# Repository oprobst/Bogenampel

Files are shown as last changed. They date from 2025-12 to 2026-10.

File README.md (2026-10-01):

# Bogenampel

Eine funkgesteuerte Timer-Anzeige für Bogenschießplätze — zwei Geräte, zwei Taster,
kein Pairing, kein Netzwerk.

<!-- TODO: Durch ein Foto der fertig montierten Anzeigetafel im Betrieb ersetzen
     (leuchtende 7-Segment-Anzeige). Bis dahin steht hier die geöffnete
     Bedieneinheit, weil sie das Projekt am besten zeigt. -->
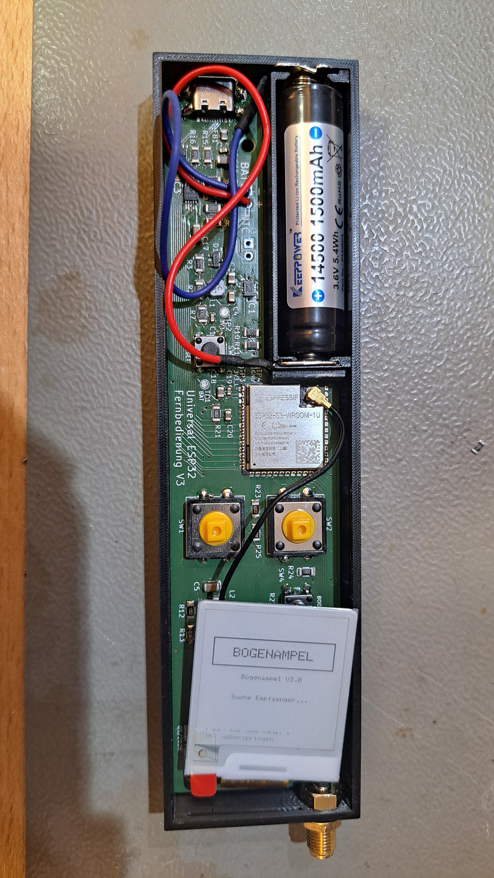
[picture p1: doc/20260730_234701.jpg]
Bedieneinheit geöffnet: ESP32-S3, 14500-Akku und e-Paper mit dem Startbildschirm


---

**Inhalt** — [1. Das Projekt](#1-das-projekt) · [2. Entwicklung](#2-entwicklung)

---

# 1. Das Projekt

## Worum es geht

Auf dem Schießplatz gibt eine Ampel den Takt vor: Rot heißt warten, Grün heißt
schießen, die Restzeit läuft sichtbar herunter. Die Bogenampel macht genau das —
aber ohne Kabel zwischen Schießlinie und Zielbereich, und mit so wenig Bedienung
wie möglich.

An der Bedieneinheit wird einmal der Modus vorgewählt (120 oder 240 Sekunden,
1-2 oder 3-4 Schützen), danach steuern **zwei Taster** den kompletten
Turnierablauf. Die Einstellung überlebt das Ausschalten.

Die Anlage besteht aus zwei Geräten:

- **Bedieneinheit (Sender)** — liegt an der Schießlinie. Akkubetrieben, e-Paper-Display,
  zwei große Taster.
- **Anzeigeeinheit (Empfänger)** — steht am Ziel. Große dreistellige 7-Segment-Anzeige
  aus LED-Streifen, in Ampelfarben, dazu zwei Gruppenbalken.

Dazwischen läuft ESP-NOW auf Kanal 1 — kein WLAN, kein Accesspoint, kein Pairing.
Der Sender sucht den Empfänger beim Einschalten selbst und merkt sich dessen
MAC-Adresse zur Laufzeit.

**Das wichtigste Sicherheitsmerkmal ist ein Stück Nicht-Verhalten**: Der Empfänger
zählt eine gestartete Passe **autonom** zu Ende. Fällt der Funk aus oder geht der
Sender aus, läuft der Timer trotzdem korrekt ab und schaltet danach auf Rot. Die
Anzeige bleibt nie in Grün stehen, nur weil die Verbindung weg ist.

## Die Bedieneinheit

ESP32-S3-WROOM-1U mit externer Antenne am U.FL-Anschluss, 1,54″-e-Paper
(200 × 200, SSD1681), eine 14500-LiIon-Zelle mit MCP73837-Lader und ein
Soft-Power-Latch um einen TPS62742: Einschalten per Taster, Ausschalten übernimmt
die Firmware selbst, sobald sie fertig aufgeräumt hat.
Das e-Paper behält sein Bild ohne Strom — der Abschaltbildschirm bleibt deshalb nach
dem Ausschalten lesbar stehen.

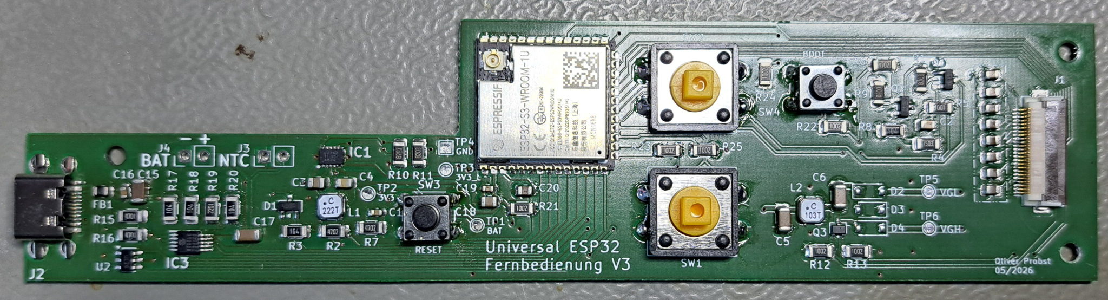
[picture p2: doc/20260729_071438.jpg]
Bestückte Sender-Platine mit ESP32-S3-WROOM-1U und den beiden Tastern


Die Platine trägt den Namen „Universal ESP32 Fernbedienung V3" — sie ist bewusst
etwas allgemeiner gehalten als nötig. Links sitzen Ladeteil und USB-C, in der Mitte
das Funkmodul mit den beiden Tastern, rechts die Ansteuerung für das e-Paper.

## Die Anzeigeeinheit

Ein XIAO ESP32C3 treibt einen WS2811-Streifen mit **66 Pixeln**: 12 für den
Gruppenbalken C/D, 12 für A/B und 3 × 14 für die dreistellige Ziffernanzeige
(2 Pixel je Segment). Versorgt wird alles aus einem USB-C-Netzteil, das über einen
CH224K-Trigger auf **12 V** verhandelt wird.

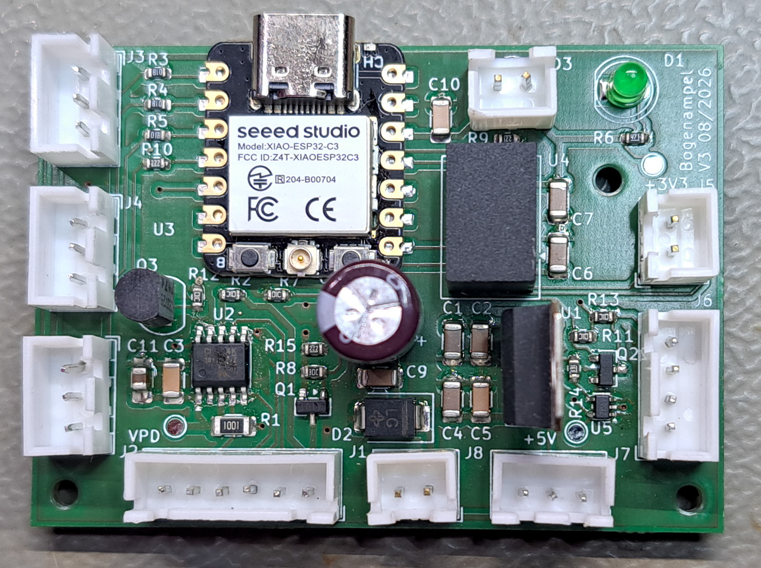
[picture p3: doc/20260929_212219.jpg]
Bestückte Empfänger-Platine mit XIAO ESP32C3 und CH224K


Drei Potis regeln direkt am Gerät, ohne Umweg über den Funk: **Lautstärke**,
**Helligkeit** und **Lüfterdrehzahl**. Dazu ein Piezo-Transducer für die
Signaltöne und ein temperaturunkritischer, aber hörbarer Lüfter — deshalb regelbar.

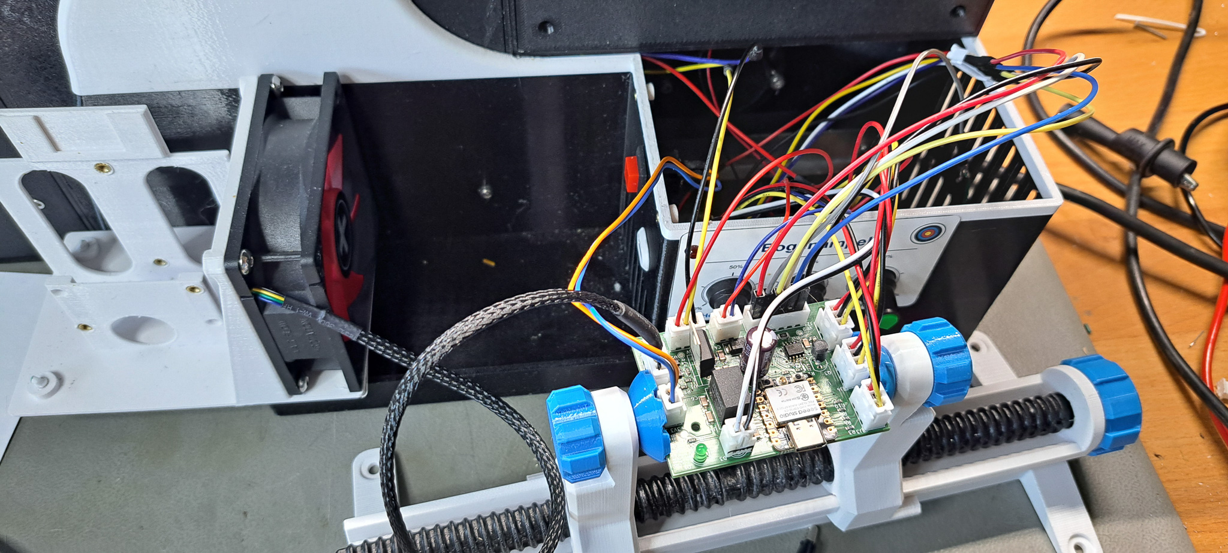
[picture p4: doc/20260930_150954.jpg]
Empfänger-Elektronik im 3D-gedruckten Gehäuse mit Lüfter und Potis


## Bedienung

Der Sender hat zwei Taster. Welcher Taster einschaltet, legt der Power-Latch in der
Hardware fest — das ist die **CONFIG**-Taste.

| Taste | kurz | 3× schnell klicken | 3 s halten |
|---|---|---|---|
| **CONFIG** | Weiter / Wert ändern | — | Ausschalten |
| **OK** | Bestätigen / Passe beenden | Alarm | Ausschalten |

Einschalten: CONFIG drücken. Ausschalten: eine der beiden Tasten 3 Sekunden halten.
Die Konfiguration (Schießzeit, Schützenzahl) bleibt im NVS erhalten und steht beim
nächsten Einschalten wieder zur Verfügung.

**Alarm**: die **OK**-Taste dreimal schnell hintereinander drücken (höchstens 0,4 s
zwischen den Klicks). Das geht im Schießbetrieb und beim Pfeileholen — also überall
dort, wo Leute an der Schießlinie stehen können. Im Konfigurationsmenü und im
Startbildschirm bleibt die Folge bewusst wirkungslos. CONFIG löst grundsätzlich
keinen Alarm aus: Diese Taste blättert durch Menüs und zählt Werte hoch, dort ist
zügiges Tippen normale Bedienung. Quittiert wird ein Alarm mit einem kurzen OK.

Ausschalten und Alarm liegen absichtlich auf **verschiedenen** Bewegungen: Halten
schaltet immer aus, egal in welchem Zustand das Gerät gerade ist. Früher hing die
Bedeutung des Haltens am Betriebszustand — wer im Schießbetrieb ausschalten wollte,
löste stattdessen einen Alarm aus.

**Automatische Abschaltung**: Wird im Konfigurationsmenü oder in „Pfeile holen" 60 Minuten
lang keine Taste gedrückt, schaltet sich der Sender selbst ab und zeigt dabei
„Automatische Abschaltung". Im Schießbetrieb und bei stehendem Alarm greift das
bewusst **nicht** — dort läuft eine Passe bzw. ein Sicherheitszustand. Gedacht ist es
gegen das im Koffer vergessene Gerät; dagegen hilft keine Stromsparmaßnahme, nur
Ausschalten.

## Ablauf einer Passe

| Phase | Anzeige | Dauer |
|---|---|---|
| **Stopp** | Rot, `000` | bis zum Start |
| **Vorbereitung** | Rot, Countdown | 10 s |
| **Schießzeit** | Grün, Countdown | 120 s oder 240 s |
| **letzte 30 s** | Orange, Countdown | 30 s |
| **Ende** | Rot, `000` | — |

Der Piezo quittiert die Phasenwechsel mit kurzen Tonfolgen (3250 Hz), das Passenende
mit drei Tönen. Ein ausgelöster Alarm blinkt und piept achtmal.

### Gruppen und halbe Passe

Bei 3-4 Schützen wird zwischen den Gruppen A/B und C/D umgeschaltet; die Anzeige folgt
einem 4er-Zyklus. Zusätzlich lässt sich eine halbe Passe starten, wenn nur noch die
zweite Gruppe schießt. Den Wechsel von der ersten auf die zweite Hälfte vollzieht der
Empfänger selbst, sobald sein Countdown abgelaufen ist — auch das gehört zur
Autonomie-Regel oben.

## Schaltpläne und Platinen

Autoritativ sind die KiCad-Projekte [`Schaltung-Sender/`](Schaltung-Sender/) und
[`Schaltung-Empfaenger/`](Schaltung-Empfaenger/). Die folgenden Exporte sind für alle
gedacht, die ohne KiCad hineinsehen wollen.

**Bedieneinheit (Sender)**

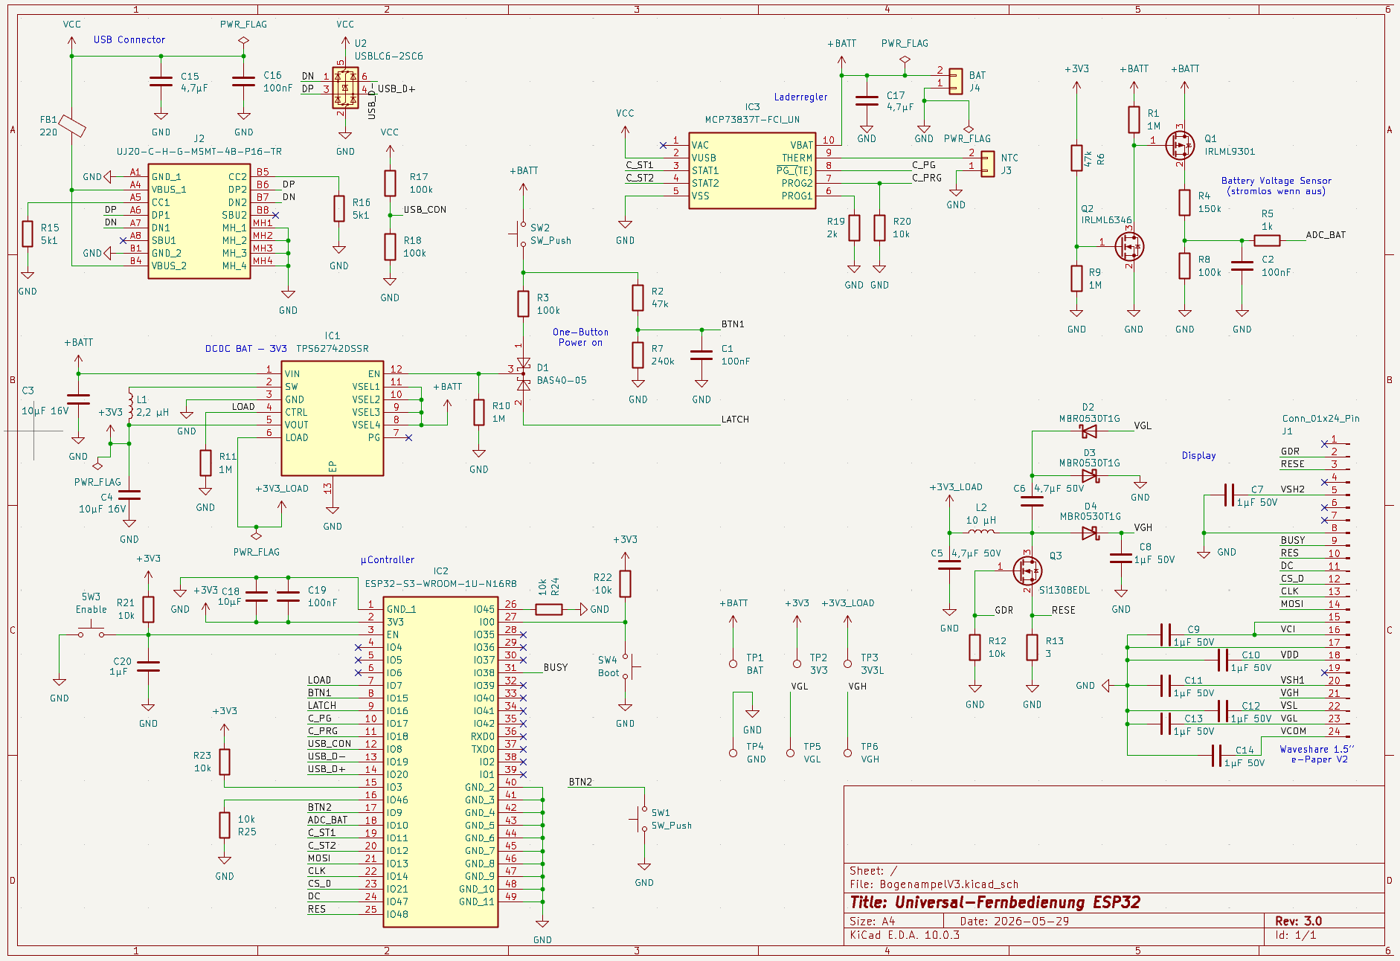
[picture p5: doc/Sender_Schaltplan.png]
Schaltplan Sender


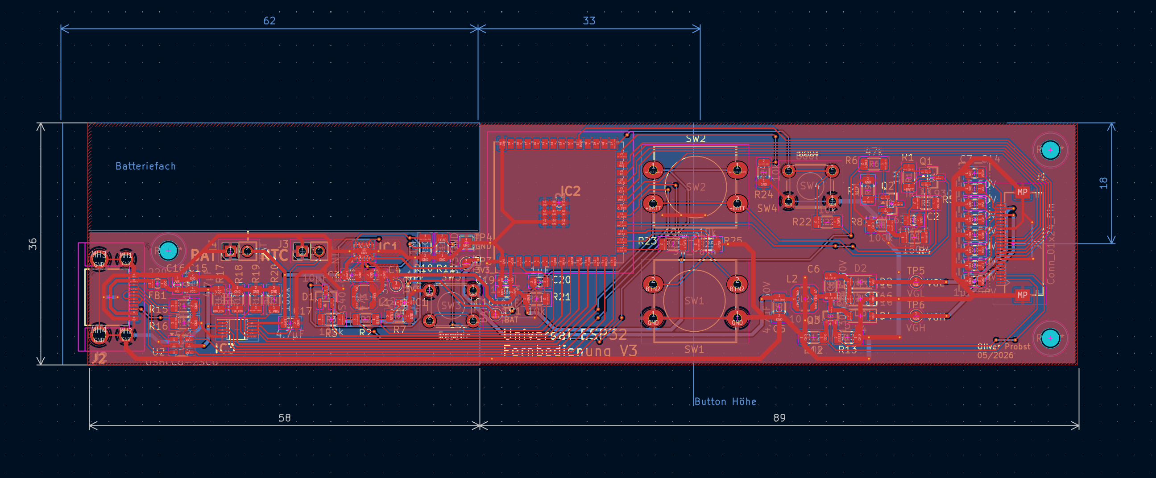
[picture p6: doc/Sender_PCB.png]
Platinenlayout Sender


**Anzeigeeinheit (Empfänger)**

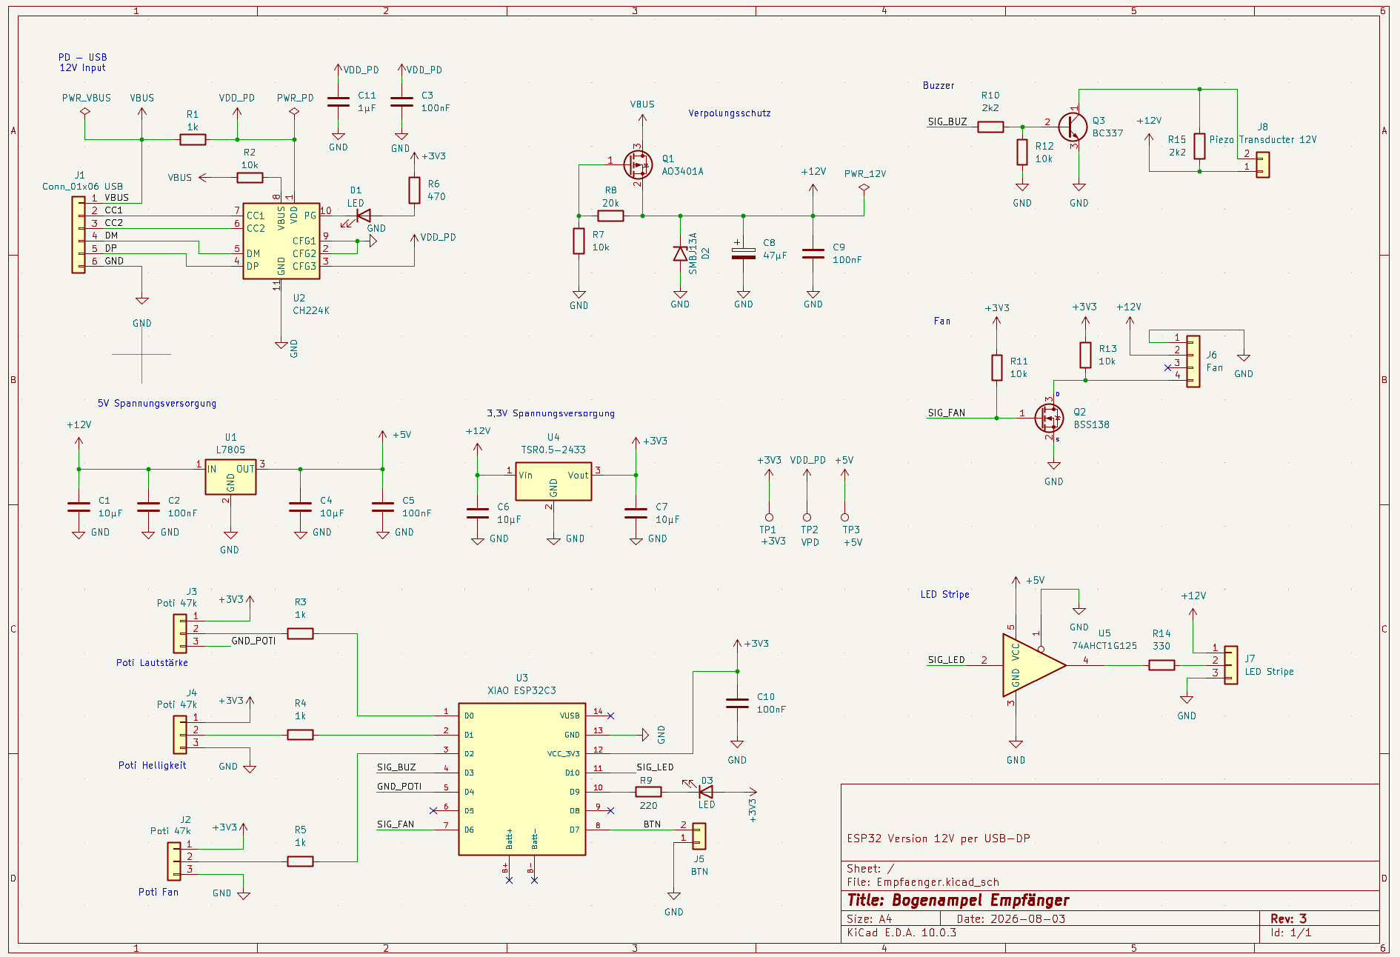
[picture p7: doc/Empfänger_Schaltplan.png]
Schaltplan Empfänger


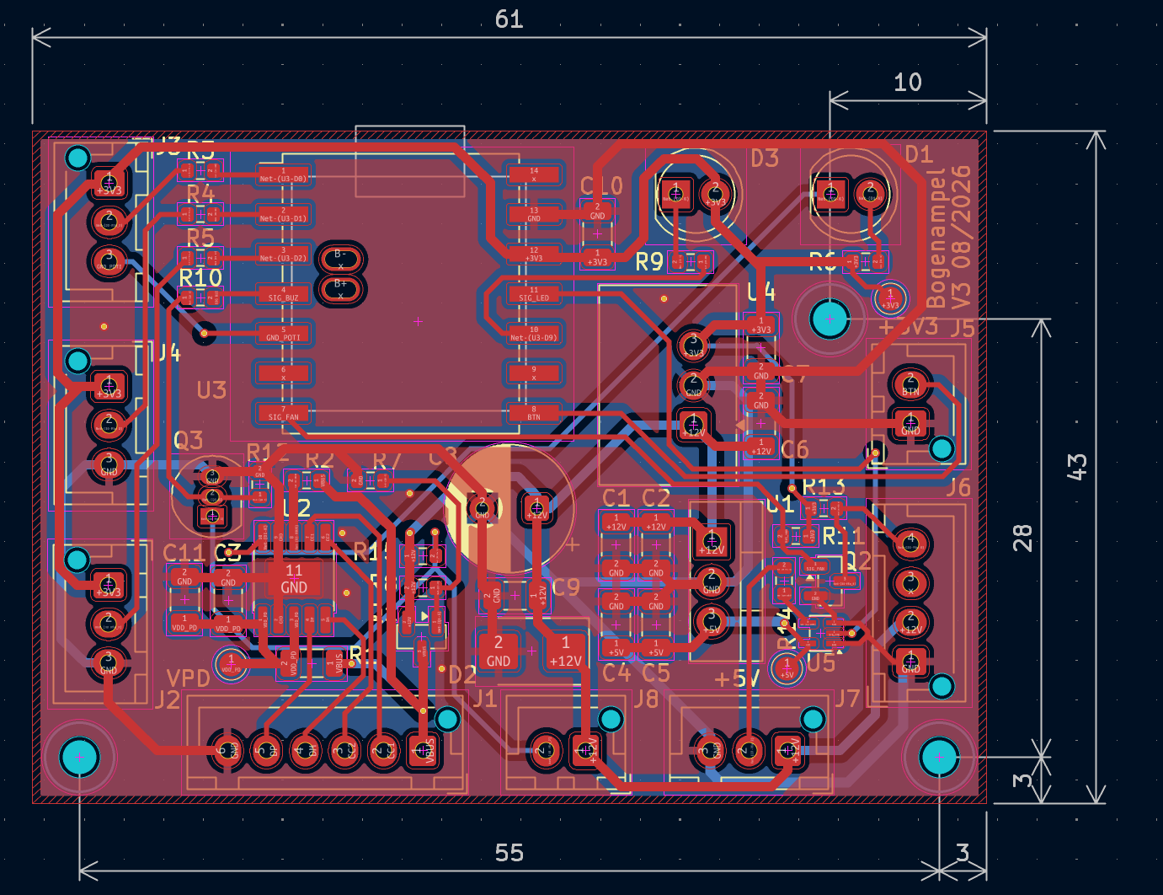
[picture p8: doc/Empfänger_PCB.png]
Platinenlayout Empfänger


---

# 2. Entwicklung

## Hardware-Überblick

| | Sender (Bedieneinheit) | Empfänger (Anzeigeeinheit) |
|---|---|---|
| **Controller** | ESP32-S3-WROOM-1U-N16R8 (16 MB Flash, 8 MB PSRAM) | Seeed XIAO ESP32C3 |
| **Anzeige** | 1.54″ e-Paper, 200×200 (SSD1681) | LED-Strip WS2811 12 V, 66 Pixel |
| **Funk** | ESP-NOW, Kanal 1 (im Chip integriert) | ESP-NOW, Kanal 1 |
| **Versorgung** | LiIon 14500 + MCP73837-Lader, USB-C | USB-C PD 12 V über CH224K (≥ 2 A) |
| **Bedienelemente** | 2 Taster (CONFIG, OK) | Debug-Taster, 3 Potis |
| **Sonstiges** | Soft-Power-Latch (TPS62742) | Piezo 12 V, geregelter Lüfter, Pegelwandler 74AHCT1G125 |
| **Firmware** | [`Sender/`](Sender/) | [`Empfaenger/`](Empfaenger/) |
| **Schaltplan** | [`Schaltung-Sender/`](Schaltung-Sender/) | [`Schaltung-Empfaenger/`](Schaltung-Empfaenger/) |

Die verbindliche Pin-Belegung steht in
[`specs/004-v3-esp32-port/contracts/hardware-pins.md`](specs/004-v3-esp32-port/contracts/hardware-pins.md)
und wird aus den KiCad-Netzlisten abgeleitet. Bei Abweichungen gilt der Schaltplan —
Änderungen gehören zuerst dorthin, dann in den Code.

Die Empfänger-Platine erzeugt aus den 12 V zwei weitere Schienen: ein TSR0.5-2433
versorgt den XIAO mit 3,3 V, ein L7805 den Pegelwandler mit 5 V. Der LED-Strip hängt
direkt am 12-V-Netz — er kann die Logikversorgung also nicht mehr in die Knie zwingen.

## Funk

ESP-NOW auf Kanal 1, ohne externes Funkmodul und ohne Pairing: Der Sender sucht den
Empfänger beim Start per Broadcast und merkt sich dessen MAC-Adresse zur Laufzeit.

Jeder Frame ist 6 Byte groß und trägt Magic-Bytes, eine Prüfsumme und eine
Sequenznummer; der Empfänger verwirft doppelte und fehlerhafte Pakete. Übertragen
werden 11 Kommandos (Start 120/240, Stopp, Init, Alarm, Ping, Gruppenwahl, halbe Passe).
Beim Start misst der Sender die Verbindungsqualität mit 10 Pings und zeigt das Ergebnis
im Splash-Screen.

> **Ein Radio, ein Kanal.** Der ESP32 kann nicht gleichzeitig ESP-NOW auf Kanal 1 und
> WLAN auf einem anderen Kanal betreiben. Deshalb läuft im Normalbetrieb **kein** WiFi —
> weder ein Accesspoint noch eine Netzwerkverbindung. Für Updates gibt es den
> Wartungsmodus (siehe unten).

Die Protokollregeln stehen in
[`espnow-protocol.md`](specs/004-v3-esp32-port/contracts/espnow-protocol.md). Zwei
davon sind beim Ändern leicht zu übersehen:

- **Regel 3**: Ein `CMD_START` wird vom Empfänger ignoriert, solange seine
  Vorbereitungsphase bereits läuft. Beim regulären Gruppenwechsel ist das Kommando
  nur ein Sync-Signal — der Empfänger hat da längst selbst umgeschaltet.
- **FR-004a**: Beim Ablauf der Zeit sendet der Sender **nie** `CMD_STOP`. Das
  Passenende gehört dem Empfänger allein.

## Bauen und Flashen

PlatformIO ist der einzige unterstützte Build-Pfad. Die `platformio.ini` liegt **zentral
im Repo-Root**, nicht in den Firmware-Ordnern — das Repo-Root ist das Arbeitsverzeichnis.
Bibliotheken kommen über `lib_deps`, es muss nichts manuell installiert werden; die
Versionen sind **gepinnt** (FastLED 3.10.3, GxEPD2 1.6.9, Adafruit GFX 1.12.6).

```bash
pio run -e sender                 # bauen
pio run -e empfaenger

pio run -t upload -e sender       # per USB flashen
pio device monitor -e sender      # 115200 Baud

pio run -e sender-release         # Feld-Build: ohne Debug-Ausgaben und CDC-Task
```

Drei Stolpersteine, die alle wie Hardwaredefekte aussehen:

**Beim Sender muss CONFIG während des gesamten Uploads gedrückt bleiben.** Der Reset von
esptool lässt sonst den Power-Latch fallen; das Gerät schaltet sich mitten im Flashen ab
und der USB-Port verschwindet. Zu beachten: `pio run -t upload` startet esptool erst nach
gut einer Minute Build- und Dependency-Scan — so lange muss der Taster gehalten werden.
Praktischer ist, das Gerät **mit gehaltenem CONFIG einzuschalten** (dann greift der
Boot-Lockout und das Halten löst keine Power-Off-Geste aus) und esptool direkt mit den
vier Images aufzurufen.

**Die Upload-Baudrate darf nicht hochgesetzt werden** (`upload_speed = 115200` in der
`platformio.ini`). Der Sender flasht über die native USB-Serial/JTAG-Peripherie, wo die
Baudrate bedeutungslos ist — esptool wechselt beim Board-Default 460800 trotzdem, der Port
re-enumeriert dabei und der Upload stirbt mitten im Stub-Flasher mit
`PermissionError(13) ... Cannot configure port`.

**Unter Windows vor jedem Upload `$env:PYTHONIOENCODING="utf-8"` setzen.** Sonst bricht
der Vorgang mit `UnicodeEncodeError` und `[upload] Error 4294967295` ab — esptool schreibt
Unicode-Fortschrittsbalken, die eine cp1252-Konsole nicht kodieren kann. Auf den Chip
wurde zu diesem Zeitpunkt noch nichts geschrieben.

### Testlauf mit verkürzten Zeiten

Für Tests gibt es eigene Environments: Vorbereitung 5 s statt 10, Schießzeit 6 s statt
120 bzw. 12 s statt 240, Orange-Phase 2 s statt 30. Eine komplette Passe läuft damit in
unter einer Minute durch.

```bash
pio run -t upload -e empfaenger-debug-ota
pio run -t upload -e sender-debug-ota
```

Eingeschaltet wird das über `-DDEBUG_SHORT_TIMES=1` aus der `platformio.ini` — **nicht**
im Quellcode, wo ein `#ifndef`-Guard mit Default 0 steht. So kann ein Build mit
6-Sekunden-Passe nicht versehentlich im Feld landen.

> **Immer beide Geräte umstellen.** Der Empfänger zählt die Passe autonom und bekommt
> per Funk nur `CMD_START_120/240`, nie die Dauer selbst. Die Zeittabelle
> (`Timing::shootingSeconds()`) steht wortgleich in beiden `Config.h` und muss es
> bleiben — sonst endet die Passe auf zwei verschiedenen Sekunden.

### OTA-Wartungsmodus

Beide Geräte lassen sich drahtlos aktualisieren, aber nur in einem eigenen Betriebsmodus —
im Normalbetrieb ist WiFi aus (siehe Kasten oben).

- **Sender**: beide Taster gleichzeitig gedrückt halten und einschalten
- **Empfänger**: mit gehaltenem Debug-Taster (D7) einschalten

Der Sender zeigt daraufhin einen Wartungs-Screen mit WLAN-Status und **seiner eigenen
IP-Adresse**; beim Empfänger signalisiert die Status-LED durch langsames Blinken, dass er
bereit ist. Die IP wird als `upload_port` in der `platformio.ini` eingetragen (eine feste
DHCP-Reservierung ist empfehlenswert, mDNS-Namen lösen über Subnetzgrenzen nicht
zuverlässig auf).

```bash
pio run -t upload -e sender-ota            # Sender, Debug-Build (serieller Monitor bleibt)
pio run -t upload -e sender-release-ota    # Sender, Feld-Build (ohne Debug-Ausgaben/CDC)
pio run -t upload -e empfaenger-ota
```

`sender-release-ota` ist der Auslieferungsweg: gleicher Wartungsmodus, aber das
Image aus `sender-release`. Danach meldet sich kein serieller Port mehr — der
Rückweg auf den Debug-Build geht weiterhin per OTA über `sender-ota`, solange der
Wartungsmodus erreichbar bleibt.

Voraussetzung ist eine `wifi_credentials.h` im Repo-Root — Vorlage:
[`wifi_credentials.h.example`](wifi_credentials.h.example). Die Datei ist bewusst nicht
eingecheckt. Fehlt sie, meldet der Wartungsmodus das auf dem Display und wartet; einen
Accesspoint-Fallback gibt es absichtlich nicht, weil ein zweites Netz auf fremdem Kanal
ESP-NOW stilllegen würde.

Zur Fehlersuche: **ArduinoOTA lauscht auf UDP 3232, nicht TCP.** Ein TCP-Portscan meldet den
Port folgerichtig als geschlossen, auch wenn der Wartungsmodus einwandfrei läuft — daraus
lässt sich also nichts über die Erreichbarkeit ableiten. espota schickt eine UDP-Einladung,
woraufhin das Gerät eine TCP-Rückverbindung zum Host aufbaut.

Der Zugang ist nicht durch ein Passwort geschützt, sondern dadurch, dass der Modus nur mit
physisch gedrückten Tastern erreichbar ist. Grund: Das ArduinoOTA-Passwort (PBKDF2) ist mit
der `espota.py` von PlatformIO nicht kompatibel, die Authentifizierung scheitert stumm.

## Anzeige-Eigenheiten

Zwei Stellen, an denen das naheliegende Verhalten bewusst nicht implementiert ist:

**Das e-Paper blitzt nur beim Start und beim Beenden.** Ein Voll-Refresh (~2,6 s,
schwarz/weiß-Invertierung) läuft nur im Splash und auf dem Abschaltbildschirm. Alles
dazwischen — Menü, Countdown, Pfeile holen, Alarm — nutzt die Partial-Waveform und
bleibt ruhig. Restschatten werden dafür in Kauf genommen und erst beim nächsten
Einschalten weggeblitzt. Die Entwicklungsgeschichte dieser Stelle steht als Kommentar
in `Sender/EpaperDisplay.cpp`; sie ist zweimal in die andere Richtung gelaufen.

**Die Poti-Drehrichtung sitzt an genau einer Stelle**: `Poti::ASCENDING` und
`Poti::level()` in `Empfaenger/Config.h`. Alle Kennlinien rechnen mit der
Reglerstellung, nie mit dem ADC-Rohwert. Wer eine Drehrichtung umdreht, ändert das
Flag — nicht die einzelnen Kennlinien.

## Stromverbrauch des Senders

Gemessen am laufenden Gerät: **0,39 W → 0,20 W**, also etwa doppelte Akkulaufzeit.
Zwei Maßnahmen, beide in der Firmware:

| Maßnahme | Ersparnis |
|---|---|
| CPU-Takt 240 → 80 MHz (`System::CPU_FREQ_NORMAL_MHZ`) | ~10 mA |
| ESP-NOW-Empfangsfenster duty-cycled statt dauerhaft offen | ~38 mA |

Der Löwenanteil war das Funkmodul: ESP-NOW hält den Empfänger per Default dauerhaft an.
Der Sender ist nach der Discovery aber ein reiner Sender — das ACK auf eigene Frames
kommt im Sendefenster zurück, also darf das Empfangsfenster zu bleiben. Während der
Discovery wird es nur um den HELLO-Broadcast herum geöffnet. Details und Voraussetzungen
stehen in [`espnow-protocol.md`](specs/004-v3-esp32-port/contracts/espnow-protocol.md),
Regel 7.

Das **e-Paper ist für den Verbrauch praktisch irrelevant** (unter 2 %) — der
Sekundencountdown im Schießbetrieb ist bewusst nicht angetastet. Nicht möglich ist das
Abschalten des PSRAM: `CONFIG_SPIRAM=1` steckt in allen vorkompilierten
arduino-esp32-Varianten und die Initialisierung hängt nicht an `-DBOARD_HAS_PSRAM`.
Weiter runter käme man nur mit abgeschaltetem Radio zwischen den Kommandos und
manuellem Light-Sleep — die automatische Variante scheidet aus, weil `CONFIG_PM_ENABLE`
in den vorkompilierten Libs fehlt.

## Projektstruktur

```text
platformio.ini          zentrale Build-Konfiguration (beide Geräte)
Sender/                 Firmware Bedieneinheit (ESP32-S3)
Empfaenger/             Firmware Anzeigeeinheit (XIAO ESP32C3)
Schaltung-Sender/       KiCad-Projekt Sender
Schaltung-Empfaenger/   KiCad-Projekt Empfänger
doc/                    Fotos, Schaltplan- und Layout-Exporte
specs/                  Feature-Spezifikationen, Pin-Contract, Abnahme-Checkliste
```

Weiterführend: [`HARDWARE.md`](HARDWARE.md) für die Hardware-Spezifikation,
[`CLAUDE.md`](CLAUDE.md) für die Entwicklungs-Leitplanken und die Änderungshistorie,
[`specs/004-v3-esp32-port/quickstart.md`](specs/004-v3-esp32-port/quickstart.md) für die
vollständige Inbetriebnahme- und Abnahme-Checkliste.

## Bekannte offene Punkte

- **Funk mit geschlossenem Empfangsfenster noch nicht im Turnierablauf verifiziert**: Dass
  das Link-ACK bei `esp_now_set_wake_window(0)` zuverlässig zurückkommt, ist durch die
  Strommessung und den Treiber-Kontrakt gestützt, aber ein vollständiger Durchlauf
  (Start, Gruppenwechsel, Alarm, Stop, Empfänger im Betrieb ausschalten → Relink) steht
  aus. Falls Kommandos zicken: `Radio::PS_WINDOW_CLOSED_MS` in `Sender/Config.h` von 0 auf
  10 setzen — kostet ~10 mA, hält das Fenster aber zu 10 % offen.
- **Restschatten am e-Paper über eine lange Sitzung**: Seit der Voll-Refresh nur noch
  beim Start und beim Beenden läuft, sammelt sich Ghosting über das ganze Turnier an.
  Ob das im Betrieb stört, ist noch nicht beurteilt. Falls ja, wäre ein Voll-Refresh
  beim Verlassen des Schießbetriebs der nächste Kompromiss.
- **MOSFET-Typen im KiCad-Projekt uneinheitlich**: Im Empfänger-Schaltplan stehen die
  MOSFETs als **Q1 = AO3401A** und **Q2 = BSS138** — aber nur im *Value*-Feld. Die
  **MPN-Eigenschaft**, die Felder im **Layout** (`Empfaenger.kicad_pcb`) und der
  **BOM-Export** (`Empfaenger.csv`) nennen weiterhin IRLML9301 bzw. 2N7002. Wer nach
  der BOM oder der MPN bestellt, bekommt also die alten Typen. Zu klären ist zuerst,
  welche Teile physisch bestückt sind; danach in KiCad die MPN nachziehen,
  „Update PCB from Schematic" laufen lassen und die BOM neu exportieren.
  Die Firmware-Kommentare und die Doku folgen dem Value-Feld (AO3401A/BSS138).
- **Ladestrom**: Der Sender lädt mit 80–100 mA. Auf 500 mA umschalten geht **nicht per
  Firmware**, auch wenn die Leitung dafür vorbereitet aussieht: Der PROG2-Eingang des
  MCP73837 verlangt für „High" mindestens 0,8 × VDD = 4,0 V (VDD = VUSB = 5 V), ein
  ESP32-GPIO liefert nur 3,3 V — und landet damit im Shutdown-Fenster, der Lader schaltet
  ab. Schnellladen braucht eine Hardware-Änderung (R20 als Pull-up nach VUSB, ggf. mit
  MOSFET zum Umschalten). Details in
  [`hardware-pins.md`](specs/004-v3-esp32-port/contracts/hardware-pins.md), Befund 4.

## Historie

**Version 2** (bis 2026-08-01) basierte auf zwei Arduino Nanos mit nRF24L01+-Funkmodulen,
einem ST7789-TFT am Sender und einer EEPROM-Konfiguration. Timer-Ablauf, Ampelfarben,
Gruppenlogik und die 11 Funk-Kommandos wurden unverändert nach V3 übernommen.

Firmware, Bibliotheken und KiCad-Projekt von V2 wurden aus dem Arbeitsverzeichnis
entfernt und sind über die Git-Historie zugänglich (letzter Stand: Commit `e632bfb`).
Beachte dabei: Die Ordnernamen `Sender/` und `Empfaenger/` bezeichnen **vor** diesem
Zeitpunkt die V2-, danach die V3-Firmware.

```bash
git show e632bfb:Sender/Sender.ino      # V2-Quelltext ansehen
```

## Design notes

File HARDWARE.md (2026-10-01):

# Hardware-Spezifikation: Bogenampel

> **Aktuelle Generation: V3 (ESP32)** — siehe direkt unten.
> Die V2-Spezifikation (Arduino Nano) folgt weiter unten als eingefrorener
> Legacy-Stand.

## Hardware V3 (aktuell)

Autoritative Quelle ist der KiCad-Schaltplan in `Schaltung-Sender/` bzw. `Schaltung-Empfaenger/`
(Constitution V: „Schaltplan zuerst, dann Code"); die daraus extrahierte,
verbindliche Pin-Tabelle für beide Firmwares steht in
[`specs/004-v3-esp32-port/contracts/hardware-pins.md`](specs/004-v3-esp32-port/contracts/hardware-pins.md).

### Sender V3 („Universal-Fernbedienung")

- **ESP32-S3-WROOM-1U-N16R8** (16 MB Flash, 8 MB Octal-PSRAM → GPIO35-37 reserviert)
- **1.54″ e-Paper** Waveshare V2 (GDEH0154D67/SSD1681, 200×200) als rohes Panel an J1
  (24-pol FPC) mit diskretem Boost (Si1308EDL + MBR0530)
- **Power**: TPS62742 mit Latch (GPIO16 hält das Gerät an, LOW = Selbstabschaltung),
  LOAD-Rail (GPIO7) schaltet die Display-Versorgung
- **Akku**: einzelne LiIon-/LiPo-Zelle (verbaut: 14500, 1500 mAh) mit MCP73837-Lader
  (STAT1/STAT2/PG an GPIO11/12/17),
  Spannungsmessung über Teiler R4=150k/R8=100k an GPIO10 (ADC1, ×2,5)
- **Taster**: BTN1 = SW2/GPIO15, aktiv HIGH über Teiler R2=47k/R7=240k an +BATT;
  BTN2 = SW1/GPIO9 gegen GND (interner Pull-up).
  **Rollen** (seit 2026-08-01 an der Gehäusebeschriftung ausgerichtet):
  GPIO15 = **CONFIG** (Weiter/Ändern; hält beim Einschalten den Power-Latch — das ist
  Hardware und per Firmware nicht auf den anderen Taster verlegbar),
  GPIO9 = **OK** (Bestätigen, Dreifachklick = Alarm). Die Zuordnung Rolle → Pin steht
  ausschließlich in `ButtonManager::readRawState()`.
- **Funk**: ESP-NOW; der **-1U** hat keine Leiterplattenantenne, sondern einen
  **U.FL-Anschluss für eine externe Antenne** (verbaut: SMA-Pigtail)

| Funktion | GPIO | | Funktion | GPIO |
|---|---|---|---|---|
| LATCH (Power halten) | 16 | | e-Paper CS | 21 |
| LOAD (Display-Rail) | 7 | | e-Paper DC | 47 |
| BTN1 = CONFIG (Power-On, aktiv HIGH) | 15 | | e-Paper RES | 48 |
| BTN2 = OK (aktiv LOW) | 9 | | e-Paper BUSY | 38 |
| ADC_BAT (ADC1, ×2,5) | 10 | | SPI CLK | 14 |
| USB_CON (aktiv HIGH) | 8 | | SPI MOSI | 13 |
| Lader ST1 / ST2 / PG / PRG | 11 / 12 / 17 / 18 | | USB D-/D+ | 19/20 |

### Empfänger V3 (PD-12V-Platine, Rev. 2026-08-03)

- **Seeed XIAO ESP32C3** (4 MB Flash), Versorgung über den **3V3-Pin** (VUSB/Batt unbeschaltet)
- **Stromversorgung**: USB-C (J1) → **CH224K** (U2) verhandelt 12 V → Verpolungsschutz
  Q1 (**AO3401A**, P-Kanal) + TVS D2 (SMBJ13A) → +12V-Netz; daraus **TSR0.5-2433** (U4) → 3V3
  für den XIAO und **L7805** (U1) → 5 V nur für den Pegelwandler U5. Kein Step-up, keine
  Jumper mehr. Netzteil: 12 V / ≥ 2 A.
- **WS2811-Strip** 66 Pixel, direkt am 12V-Netz (2×12 Gruppen + 3×14 Ziffern-Pixel)
- **Pegelwandler U5 74AHCT1G125** (3,3 → 5 V, /OE fest an GND) in der Datenleitung,
  Ausgang über R14 330 Ω an J7 — behebt die früheren Farbkipper bei 3,3-V-Pegel
- **Piezo**: 12-V-Transducer über BC337 (Q3; R10 2k2 Basisvorwiderstand, R12 10k
  Basis-Pulldown, R15 2k2 nach +12 V als Entlade-Pfad), LEDC-PWM (3,25 kHz = Resonanz,
  Lautstärke = Duty 0-50 %)
- **Lüfter**: **BSS138** Low-Side (Q2, **invertiert**: Gate HIGH = PWM-Leitung LOW =
  langsam), LEDC-PWM 25 kHz, Drehzahl per Poti;
  Tacho bewusst unbeschaltet (R11 = Gate-Pull-up → Lüfter läuft beim Boot auf Minimaldrehzahl)
- **Potis** (3 × 47 k, je über 1 k am Schleifer): regulär zwischen GND und 3V3 verdrahtet,
  **Aufdrehen liefert den höheren ADC-Wert**. Die Firmware rechnet deshalb über
  `Poti::level()` mit der Reglerstellung statt mit dem Rohwert; die Drehrichtung steht
  als einziges Flag in `Poti::ASCENDING` (`Empfaenger/Config.h`) — nie einzeln in den
  Kennlinien invertieren.
- **ESP32-C3-Strapping-Fixes** (alle im Schaltplan umgesetzt):
  GPIO2 (Lautstärke-Poti) → Fußpunkt an D4/GPIO6 statt GND („POTI_GND");
  GPIO9 (Status-LED) → aktiv LOW (3V3 → LED → R9 → Pin); GPIO8 frei (kein Tacho)

| Funktion | XIAO-Pin | GPIO |
|---|---|---|
| Poti Lautstärke (J3, Fußpunkt an D4!) | D0 | 2 |
| Poti Helligkeit (J4) | D1 | 3 |
| Poti Lüfter-Drehzahl (J2) | D2 | 4 |
| Piezo (J8, über BC337) | D3 | 5 |
| POTI_GND (geschalteter Fußpunkt) | D4 | 6 |
| Lüfter-PWM (J6 Pin 4, über Q2 BSS138) | D6 | 21 |
| Debug-Taster (J5, aktiv LOW) | D7 | 20 |
| Status-LED (**aktiv LOW**) | D9 | 9 |
| WS2811 Data (J7, über U5) | D10 | 10 |
| frei / Reserve | D5, D8 | 7, 8 |

---

# Hardware-Spezifikation V2 (Legacy): Bogenampel Sender

## Übersicht

Der Sender ist die Bedieneinheit der Bogenampel und basiert auf einem Arduino Nano V3. Er steuert per Funk (NRF24L01) die Anzeigeeinheit und verfügt über ein TFT-Display zur Statusanzeige.

## Komponenten

### Mikrocontroller
- **Arduino Nano V3**
  - ATmega328P @ 16 MHz
  - 32 KB Flash (2 KB für Bootloader)
  - 2 KB SRAM
  - 1 KB EEPROM
  - Betriebsspannung: 5V
  - I/O-Pins: 3.3V/5V tolerant (über Level Shifter für Display)

### Display
- **2.4" TFT LCD ST7789**
  - Auflösung: 240 x 320 Pixel
  - Farbtiefe: 65K (16-bit RGB565)
  - Interface: SPI
  - Betriebsspannung: 3.3V (via Level Shifter)
  - Controller: ST7789

### Level Shifter
- **TXS0108EPW**
  - 8-Kanal bidirektionaler Level Shifter
  - Konvertiert 5V (Arduino) ↔ 3.3V (Display)
  - Kanäle für: SCK, MOSI, MISO, CS, DC, RST

### Funk-Modul
- **NRF24L01**
  - 2.4 GHz Transceiver
  - Reichweite: ~20-50m (indoor), bis 100m (Freifeld)
  - Interface: SPI
  - Betriebsspannung: 3.3V
  - Datenstrom 1-2 Mbps

### Spannungsversorgung
- **9V Block-Batterie**
  - Über Ein/Aus-Schalter zuschaltbar
  - Spannungsüberwachung über Spannungsteiler an A7
  - Spannungsteiler: 2x 10kΩ (1:1)

- **USB-Versorgung (5V)**
  - Alternative zur Batterie
  - Für Entwicklung und Programmierung

### Weitere Komponenten
- **Taster** (für Timer-Steuerung und Menü-Navigation)
- **Status-LEDs** (Betriebsanzeige)
- **Kondensatoren** (Spannungsstabilisierung für NRF24L01)

---

## Pin-Belegung Arduino Nano

> **WICHTIG:** Die folgenden Pin-Zuweisungen basieren auf typischen SPI-Konfigurationen.
> Der zugehörige KiCad-Schaltplan `Schaltung/Bogenampel.kicad_sch` wurde am 2026-08-01
> aus dem Arbeitsverzeichnis entfernt und ist nur noch über die Git-Historie zugänglich
> (`git show <commit>:Schaltung/Bogenampel.kicad_sch`). Da V2 eingefroren ist (FR-025),
> werden diese Angaben nicht mehr nachgeführt.

### SPI-Bus (Gemeinsam für Display und NRF24L01)

| Arduino Pin | Signal | Funktion | Level Shifter | Ziel |
|---|---|---|---|---|
| D13 (SCK) | SPI.SCK | SPI Clock | → 3.3V | Display SCK, NRF24 SCK |
| D11 (MOSI) | SPI.MOSI | SPI Data Out | → 3.3V | Display MOSI (SDI), NRF24 MOSI |
| D12 (MISO) | SPI.MISO | SPI Data In | ← 3.3V | Display MISO (SDO), NRF24 MISO |

### ST7789 TFT Display (über TXS0108EPW Level Shifter)

| Arduino Pin | Signal | Display Pin | Funktion | Level |
|---|---|---|---|---|
| A0 | UI_CS → DSPL_CS | CS | Chip Select | 5V → 3.3V |
| D10 | UI_DC/RS → DSPL_DC/RS | DC/RS | Data/Command | 5V → 3.3V |
| A1 | UI_RES → DSPL_RES | RESET | Reset | 5V → 3.3V |
| D13 | SPI.SCK → DSPL_SCK | SCK | SPI Clock | 5V → 3.3V |
| D11 | SPI.MOSI → DSPL_MOSI | SDA | SPI Data Out | 5V → 3.3V |
| D12 | SPI.MISO → DSPL_MISO | - | SPI Data In | 5V → 3.3V |

**Aktualisiert für ST7789:**
- A0  → UI_CS → TXS0108 → DSPL_CS (Display Chip Select)
- D10 → UI_DC/RS → TXS0108 → DSPL_DC/RS (Data/Command)
- A1  → UI_RES → TXS0108 → DSPL_RES (Reset)
- Backlight: Fest an 3.3V (kein PWM-Control)

### NRF24L01 Funkmodul

| Arduino Pin | Signal | NRF24 Pin | Funktion | Level |
|---|---|---|---|---|
| D9 | CE_NRF | CE (Pin 3) | Chip Enable | 5V → 3.3V intern |
| D8 | CS_NRF | CSN (Pin 4) | Chip Select | 5V → 3.3V intern |
| D13 | SPI.SCK | SCK (Pin 5) | SPI Clock | Gemeinsam mit Display |
| D11 | SPI.MOSI | MOSI (Pin 6) | SPI Data Out | Gemeinsam mit Display |
| D12 | SPI.MISO | MISO (Pin 7) | SPI Data In | Gemeinsam mit Display |
| 3.3V | VCC | VCC (Pin 2) | Stromversorgung | 3.3V |
| GND | GND | GND (Pin 1) | Masse | 0V |

**Verifiziert aus Code (Sender/Config.h):**
- D9 → CE_NRF (Chip Enable)
- D8 → CS_NRF (Chip Select)
- 10µF Kondensator (C1) zwischen VCC und GND für Stabilisierung

### Eingänge (Taster & Schalter)

| Arduino Pin | Signal | Funktion | Pull-Up | Bemerkung |
|---|---|---|---|---|
| D5 | Input 1 (J1) | Menü-Navigation links | Ja | Aktiv LOW |
| D6 | Input 2 (J2) | Menü-Auswahl bestätigen (OK) | Ja | Aktiv LOW |
| D7 | Input 3 (J3) | Menü-Navigation rechts | Ja | Aktiv LOW |

**Verifiziert aus Code (Sender/Config.h):**
- J1 (Input 1) → D5 mit internem Pull-Up (Links)
- J2 (Input 2) → D6 mit internem Pull-Up (OK)
- J3 (Input 3) → D7 mit internem Pull-Up (Rechts)
- Alle Taster sind aktiv LOW (Taster schließt gegen GND)

### Analoge Eingänge

| Arduino Pin | Signal | Funktion | Spannungsteiler | Bemerkung |
|---|---|---|---|---|
| A5 | VOLTAGE_SENSE | Batteriespannung | 10kΩ:10kΩ (1:1) | Median-Filter über 5 Werte |

**Berechnung Batteriespannung:**
```cpp
// Spannungsteiler 1:1 → Vbat = 2 × Vmeasured
uint16_t adcValue = analogRead(A5);
float voltage = (adcValue / 1023.0) * 5.0 * 2.0;  // in Volt
uint8_t percent = map(voltage, 6.0, 9.6, 0, 100); // 6V=0%, 9.6V=100%
```

### Status-LEDs

| Arduino Pin | Signal | Funktion | Widerstand | Bemerkung |
|---|---|---|---|---|
| A2 | LED_STATUS (D1) | Debug/Status LED | 330Ω | Rot |

**Aktualisiert:**
- D1 (rot) → A2 über 330Ω Widerstand
- Nur eine LED bestückt, verwendet für Debug-Zwecke (z.B. RF-Übertragung)

### Buzzer (Akustisches Feedback)

| Arduino Pin | Signal | Funktion | Bemerkung |
|---|---|---|---|
| D4 | BUZZER | KY-006 Passiver Piezo Buzzer | Für Tastentöne (Click-Feedback) |

**Details:**
- Frequenz: 1600 Hz (satter Klick-Ton)
- Dauer: 25ms pro Klick
- Wird beim Drücken von Tasten aktiviert (ButtonManager)

### Stromversorgung

| Pin | Funktion | Spannung | Bemerkung |
|-----|---|---|---|
| VIN | Batterie-Eingang | 9V | Über Schalter |
| 5V | Spannungsausgang | 5V | Geregelt durch Nano |
| 3.3V | Spannungsausgang | 3.3V | Für NRF24L01 |
| GND | Masse | 0V | Gemeinsam für alle Komponenten |

---

## SPI-Bus Konfiguration

Der Arduino Nano nutzt **Hardware-SPI** für Display und NRF24L01:

### SPI-Einstellungen ST7789
```cpp
SPISettings displaySPI(40000000, MSBFIRST, SPI_MODE0);
// 40 MHz (max für ST7789), MSB First, Mode 0
```

### SPI-Einstellungen NRF24L01
```cpp
SPISettings nrfSPI(10000000, MSBFIRST, SPI_MODE0);
// 10 MHz (max für NRF24L01), MSB First, Mode 0
```

### Chip Select Management
Da Display und NRF24L01 den gleichen SPI-Bus teilen, ist ein sauberes CS-Management kritisch:

```cpp
// Display aktivieren
digitalWrite(DSPL_CS, LOW);
SPI.beginTransaction(displaySPI);
// ... Display-Kommunikation ...
SPI.endTransaction();
digitalWrite(DSPL_CS, HIGH);

// NRF24 aktivieren
digitalWrite(CS_NRF, LOW);
SPI.beginTransaction(nrfSPI);
// ... NRF-Kommunikation ...
SPI.endTransaction();
digitalWrite(CS_NRF, HIGH);
```

---

## Level Shifter Details (TXS0108EPW)

Der TXS0108EPW konvertiert bidirektional zwischen 5V (Arduino) und 3.3V (Display):

| Kanal | Arduino (5V) | Display (3.3V) | Signal |
|---|---|---|---|
| A1 | DSPL_SCK | SCK | SPI Clock |
| A2 | DSPL_MOSI | MOSI/SDI | SPI Data Out |
| A3 | DSPL_MISO | MISO/SDO | SPI Data In |
| A4 | DSPL_CS | CS | Chip Select |
| A5 | DSPL_DC | DC/RS | Data/Command |
| A6 | DSPL_RST | RESET | Reset |

**Wichtig:**
- VCCB = 5V (Arduino-Seite)
- VCCA = 3.3V (Display-Seite)
- OE (Output Enable) = VCCA (immer aktiviert)

---

## Ressourcen-Übersicht

### SRAM-Nutzung (Arduino Nano: 2 KB)

| Komponente | Geschätzter Verbrauch | Bemerkung |
|---|---|---|
| Display-Buffer (TFT_eSPI) | ~200-400 Bytes | Sprite-Buffer optional |
| NRF24 Library | ~150 Bytes | RF24 Library |
| State Machine | ~50 Bytes | Enum + Zeitstempel |
| Median Filter (5 Werte) | 10 Bytes | uint16_t × 5 |
| Button Manager | ~20 Bytes | 2 Buttons |
| String Konstanten (PROGMEM) | 0 Bytes (Flash) | Im Flash gespeichert |
| **Gesamt (grob)** | **~500-700 Bytes** | ~30% von 2 KB |

### Flash-Nutzung (Arduino Nano: 30 KB nutzbar)

| Komponente | Geschätzter Verbrauch | Bemerkung |
|---|---|---|
| TFT_eSPI Library | ~15-20 KB | Mit ILI9341 Treiber |
| RF24 Library | ~8-10 KB | NRF24L01 |
| Application Code | ~5-8 KB | State Machine, UI |
| **Gesamt (grob)** | **~28-38 KB** | Knapp! Optimierung nötig |

**Optimierungen:**
- `#define TFT_eSPI_DISABLE_ALL_FONTS` - nur benötigte Fonts
- `#define RF24_TINY` - reduzierte RF24-Version
- Strings im PROGMEM (`PROGMEM`)
- `-Os` Compiler-Flag (Size-Optimierung)

---

## Empfohlene Bibliotheken

### Display
- **Adafruit ST7789** (verwendet)
  - Offizielle Adafruit Library
  - Hardware-SPI-Unterstützung
  - ST7789-Treiber integriert
  - `lib_deps = adafruit/Adafruit ST7735 and ST7789 Library@^1.10.0`
  - Benötigt auch: `adafruit/Adafruit GFX Library@^1.11.0`

### Funk
- **RF24** (empfohlen)
  - Optimiert für NRF24L01
  - `lib_deps = nRF24/RF24@^1.4.0`

---

## Schaltplan-Referenz

**KiCad-Dateien** (nur noch in der Git-Historie, siehe oben):
- `Schaltung/Bogenampel.kicad_sch` - Hauptschaltplan
- `Schaltung/Bogenampel.kicad_pcb` - PCB-Layout

**Netz-Labels im Schaltplan:**
- `SPI.SCK`, `SPI.MOSI`, `SPI.MISO` - Gemeinsamer SPI-Bus
- `DSPL_CS`, `DSPL_DC`, `DSPL_RST` - Display Control Pins
- `CE_NRF`, `CS_NRF` - NRF24L01 Control Pins

---

## ✅ Pin-Verifikation - Komplett

**Alle Pin-Zuweisungen wurden aus dem Code (Sender/Config.h) verifiziert:**

1. ✅ **ST7789 Display** (über TXS0108EPW Level Shifter):
   - [x] DSPL_CS → A0
   - [x] DSPL_DC/RS → D10
   - [x] DSPL_RES → A1
   - [x] DSPL_LED → 3.3V (fest)

2. ✅ **NRF24L01**:
   - [x] CE_NRF → D9
   - [x] CS_NRF → D8

3. ✅ **Taster**:
   - [x] Input 1 (J1) → D5 (Menü Links)
   - [x] Input 2 (J2) → D6 (Menü OK)
   - [x] Input 3 (J3) → D7 (Menü Rechts)

4. ✅ **Status-LED**:
   - [x] LED 1 (D1 rot) → A2 (Debug/Status)

5. ✅ **Buzzer**:
   - [x] Buzzer → D4 (KY-006 Passiver Piezo)

6. ✅ **Analoge Eingänge**:
   - [x] Batteriespannung → A5 (via 1:1 Spannungsteiler)

7. ✅ **SPI-Bus** (gemeinsam):
   - [x] SCK → D13
   - [x] MOSI → D11
   - [x] MISO → D12

---

## Änderungshistorie

| Datum | Version | Änderung |
|---|---|---|
| 2025-12-13 | 1.0 | Initiale Version mit Platzhalter-Pins |
| 2025-12-13 | 1.1 | Pin-Zuweisungen aus Schaltplan.png verifiziert und aktualisiert |
| 2025-12-13 | 1.2 | Display auf ST7789 korrigiert, Pin-Zuweisungen aktualisiert (TFT_CS→A0, TFT_RST→A1, LEDs→A2/A3/A4) |
| 2025-12-13 | 1.3 | Button-Namen aktualisiert (Links/OK/Rechts), nur LED_RED (A2) bestückt, grüne und gelbe LED entfernt |
| 2025-12-25 | 1.4 | Pin-Zuweisungen aus Code synchronisiert: NRF (D9/D8), Buttons (D5/D6/D7), VOLTAGE_SENSE (A5), Buzzer (D4) hinzugefügt |

---

**Nächste Schritte** (historisch, bezieht sich auf V2 — V2 ist seit 2026-08-01
eingefroren, diese Punkte werden nicht mehr verfolgt):
1. Pin-Zuweisungen aus KiCad-Schaltplan übernehmen
2. Hardware-Tests durchführen
3. Config.h mit korrekten Pins aktualisieren

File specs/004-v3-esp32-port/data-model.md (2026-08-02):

# Data Model: Bogenampel V3 Hardware Port

**Feature**: 004-v3-esp32-port | **Date**: 2026-06-09

Die fachlichen Entitäten sind eine 1:1-Übernahme aus V2; neu sind der ESP-NOW-Frame, der
Power-Zustand des Senders und die Empfänger-Lokalregler. Quellen: `Sender/Config.h`,
`Sender/Commands.h`, `Sender/StateMachine.cpp`, `Empfaenger/Empfaenger.ino` (V2).

## 1. TournamentConfig (Sender, persistent in NVS)

| Feld | Typ | Werte | Default | Validierung |
|---|-----|---|---|---|
| `shootingTime` | uint16 | 120, 240 (Sekunden) | 120 | Whitelist, sonst Default |
| `shooterCount` | uint8 | 2 (= „1-2 Schützen"), 4 (= „3-4 Schützen") | 2 | Whitelist, sonst Default |

- **Speicherort**: NVS, Namespace `bogenampel`, Keys `timeS`, `count` (R-6).
- **Schreibzeitpunkt**: sofort bei Bestätigung im ConfigMenu (Edge Case „Empty battery").
- **Lesezeitpunkt**: Boot; fehlende/ungültige Werte → Defaults (FR-005). Die V2-CRC8 entfällt
  (NVS sichert Integrität selbst), die Wertebereichsprüfung bleibt.

## 2. RadioPacketV3 (Funkprotokoll, beide Geräte)

6 Bytes, `__attribute__((packed))` — Details siehe `contracts/espnow-protocol.md`:

| Byte | Feld | Beschreibung |
|---|---|---|
| 0–1 | `magic` | `'B','3'` — Filter gegen fremde ESP-NOW-Frames |
| 2 | `type` | FrameType: `CMD`, `HELLO`, `HELLO_ACK`, `PING`, `PING_ACK` |
| 3 | `seq` | Sequenznummer (Dedup bei Retries, FR-008) |
| 4 | `command` | RadioCommand (nur bei `type == CMD`, sonst 0) |
| 5 | `checksum` | `command ^ 0xFF` (V2-Semantik) |

**RadioCommand** (unverändert aus V2 `Commands.h`, FR-002): `CMD_STOP=0x01`, `CMD_START_120=0x02`,
`CMD_START_240=0x03`, `CMD_INIT=0x04`, `CMD_ALARM=0x05`, `CMD_PING=0x06`, `CMD_GROUP_AB=0x08`,
`CMD_GROUP_CD=0x09`, `CMD_GROUP_NONE=0x0A`, `CMD_GROUP_FINISH_AB=0x0B`, `CMD_GROUP_FINISH_CD=0x0C`.

**TransmissionResult** (V2-API erhalten): `TX_SUCCESS`, `TX_TIMEOUT`, `TX_ERROR`.

## 3. Sender-Zustandsmaschine (PORT aus V2, + Power-Off)

```text
            ┌──────────┐  Splash-Ende (15 s) / Quality-Test fertig
  Boot ───► │  SPLASH  │ ───────────────────────────────┐
  (LATCH=1) └──────────┘                                ▼
            ┌───────────────────────────────────► CONFIG_MENU ◄──── „Neustart"
            │                                        │ „Start" (sendet CMD_INIT,
            │                                        ▼  CMD_GROUP_*)
            │       „Nächste Passe" (CMD_START_*) PFEILE_HOLEN ◄────────────┐
            │      ┌─────────────────────────────────┘                      │
            │      ▼                                                        │
            │  SCHIESS_BETRIEB ── Zeitablauf (KEIN Funk! FR-004a) ──────────┤
            │      │  │            └─ bei 3-4 Schützen POS_1: 2. Gruppe     │
            │      │  │               (lokaler Restart + CMD_START als Sync)│
            │      │  └── „Passe beenden" (CMD_STOP) ───────────────────────┘
            │      └── BTN1 ≥ 2 s gehalten (CMD_ALARM) ──► ALARM
            │                                               │ quittieren (CMD_STOP)
            └───────────────────────────────────────────────┘ → PFEILE_HOLEN

  Power-Off (orthogonal): BTN1 ≥ 3 s in SPLASH/CONFIG_MENU/PFEILE_HOLEN/ALARM
  → Abschalt-Screen → Display hibernate → LOAD aus → LATCH=0.
  In SCHIESS_BETRIEB nicht verfügbar (BTN1-Geste = Alarm, FR-015).
```

**Zustandsdaten** (wie V2): `currentGroup` (AB/CD), `currentPosition` (POS_1/POS_2),
`inPreparationPhase`, `preparationSecondsRemaining`, `shootingSecondsRemaining`.

**Gruppen-4-Zyklus** (`advanceToNextGroup`, exakt wie V2): 
`AB/POS_1 → CD/POS_2 → CD/POS_1 → AB/POS_2 → AB/POS_1 …`
Bei 1-2 Schützen: keine Gruppen (CMD_GROUP_NONE).

**Taster-Gesten (V3-Mapping)** — ⚠️ **überholt seit 2026-08-02**: Diese Tabelle
gibt den Stand vor Feature 006 wieder. Autoritativ ist jetzt
`specs/006-shutdown-alarm-gesten/data-model.md` §3. Geändert haben sich beide
Gesten-Zeilen: „BTN1 ≥ 2 s = Alarm" ist ersatzlos entfallen (Alarm = 3× Klick,
beide Taster, nur in PFEILE_HOLEN und SCHIESS_BETRIEB), und Power-Off durch
Halten gilt jetzt auch im SCHIESS_BETRIEB.

| Geste | SPLASH | CONFIG_MENU | PFEILE_HOLEN | SCHIESS_BETRIEB | ALARM |
|---|---|---|---|---|---|
| BTN2 kurz („Rechts") | — | Auswahl weiter (Wrap) | Menüpunkt weiter (Wrap) | — | — |
| BTN1 kurz („OK") | Splash überspringen | bestätigen | Menüpunkt ausführen | Passe beenden | Alarm quittieren |
| BTN1 ≥ 2 s | — | — | — | **Alarm** | — |
| BTN1 ≥ 3 s | Power-Off | Power-Off | Power-Off | — (durch Alarm belegt) | Power-Off |

Boot-Lockout: alle BTN1-Gesten gesperrt, bis BTN1 nach dem Einschalt-Druck einmal losgelassen
wurde; zusätzlich V2-`MENU_LOCKOUT_MS` (400 ms) nach jedem Zustandswechsel.

## 4. Empfänger-Zustandsmodell (PORT aus V2, autonom)

```text
  IDLE/INIT ── CMD_START_120/240 ──► PREPARATION (10 s, rot, 2 Pieptöne)
     ▲                                   │ Ablauf (autonom)
     │                                   ▼
     │                              SHOOTING (grün; letzte 30 s orange; 1 Piepton bei Start)
     │                                   │
     │             ┌─────────────────────┼──────────────────────┐
     │     CMD_STOP (manuell)    Zeitablauf, POS_2 oder   Zeitablauf, POS_1 bei
     │     3 Pieptöne, rot       keine Gruppen: 3 Pieptöne,    3-4 Schützen:
     │             │             rot, „000" (autonom!)    autonomer Gruppenwechsel
     │             ▼                     │                + neue PREPARATION ──┐
     └──────── STOPPED ◄─────────────────┘                                     │
                   ▲                                      (CMD_START als Sync  │
                   │                                       wird ignoriert,     │
            CMD_ALARM (jederzeit): 8× blinken rot,         wenn PREPARATION    │
            alle LEDs, danach STOPPED                      schon läuft) ◄──────┘
```

**Zustandsdaten** (wie V2): `timerRunning`, `timerRemainingSeconds`, `inPreparationPhase`,
`preparationRemainingSeconds`, `groupsEnabled`, `currentGroup`, `currentPosition`,
`alarmActive`, `alarmBlinkCount`.

**Autonomie-Invariante (FR-004)**: Übergänge bei Zeitablauf benötigen keinen Funkempfang.
**Dedup-Invariante (FR-008)**: identische `seq` → Frame verwerfen; CMD_START während laufender
PREPARATION der zweiten Gruppe → ignorieren (V2-Verhalten, `Empfaenger.ino:827`).

## 5. PowerState (Sender, NEU)

| Feld | Quelle | Werte/Bedeutung |
|---|---|---|
| `batteryMv` | ADC GPIO10 × 2,5, Median-5 | 3000–4200 mV (LiPo) |
| `batteryPercent` | linear aus `batteryMv` | 0–100 %, Warnung < 3300 mV (V2-Schwellen) |
| `usbConnected` | GPIO8 (aktiv HIGH) | USB-Versorgung anliegend |
| `chargeState` | GPIO11/12/17 decodiert (MCP73837) | `CHARGING`, `COMPLETE`, `FAULT`, `NO_INPUT` |
| `latchHeld` | GPIO16 Ausgang | true ab Boot bis Power-Off |

Aktualisierung alle 5 s (V2 `Battery::UPDATE_INTERVAL_MS`), Anzeige in der Statuszeile
(Partial-Refresh-Fenster).

## 6. Empfänger-Lokalregler (NEU)

| Feld | Quelle | Abbildung |
|---|---|---|
| `volume` | Poti D0 (GPIO2, ADC1), ≥10 Hz gelesen | quadratische Kurve → LEDC-Duty 0–50 %, Minimum hörbar |
| `brightness` | Poti D1 (GPIO3, ADC1) **nach Umverdrahtung** | linear → FastLED-Brightness 64–255 (V2) |
| `fanSpeed` | Poti D2 (GPIO4, ADC1), ≥10 Hz gelesen | linear → LEDC-PWM auf D6 (≥ 25 kHz); kein Tacho (nicht angeschlossen) |
| `statusLed` | D9 (**aktiv LOW**, Strapping-Befund 3) | an = bereit, kurzes Aus-Blinken bei Frame-Empfang (ersetzt 3 V2-LEDs) |

## 7. e-Paper-Anzeigemodell (Sender, NEU)

| Bereich | Inhalt | Refresh |
|---|---|---|
| Statuszeile (oben, ~200×24 px) | Akku %, USB/Lade-Symbol, Funkstatus | partial, bei Änderung |
| Hauptbereich | Screen-abhängig (Menü, Countdown groß, Alarm) | voll bei Screenwechsel |
| Countdown-Fenster (zentriert, ~120×64 px) | mm:ss bzw. Sekunden | partial, 1 Hz |

Ghosting-Regel: Voll-Refresh bei jedem Zustandswechsel, mindestens einmal pro Passe-Zyklus (R-2).

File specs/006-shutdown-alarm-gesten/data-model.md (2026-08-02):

# Phase 1 — Data Model: Entkopplung von Ausschalten und Alarm

**Feature**: 006-shutdown-alarm-gesten
**Datum**: 2026-08-02

> **Autoritativ ab sofort**: Die Gesten-Tabelle in §3 ersetzt die Tabelle in
> `specs/004-v3-esp32-port/data-model.md` §3 (Zeilen „BTN1 ≥ 2 s" / „BTN1 ≥ 3 s").
> Constitution V verlangt State-Diagramm-Updates bei jeder Änderung an der
> Zustandsmaschine — die Zustände selbst bleiben unverändert, nur ihre Auslöser
> ändern sich.

## 1. Geänderte Konstanten (`Sender/Config.h`, namespace `Timing`)

| Konstante | alt | neu | Bezug |
|---|---|---|---|
| `ALARM_THRESHOLD_MS` | 2000 | **entfällt** | FR-016 |
| `POWER_OFF_HOLD_MS` | 3000 | 3000 (unverändert) | FR-001, A-001 |
| `MULTI_CLICK_COUNT` | — | **3** (neu) | FR-007 |
| `MULTI_CLICK_GAP_MS` | — | **400** (neu) | FR-007, A-002 |
| `IDLE_POWER_OFF_MS` | 20 min | **60 min** | FR-019 |
| `IDLE_POWER_OFF_MS` (DEBUG_SHORT_TIMES) | 60 s | 60 s (unverändert) | R-5 |
| `DEBOUNCE_MS` | 80 | 80 (unverändert) | — |

Randbedingung: `DEBOUNCE_MS (80) < MULTI_CLICK_GAP_MS (400) < POWER_OFF_HOLD_MS
(3000)`. Als `static_assert` in `Config.h` zu hinterlegen (Projektkonvention,
siehe bestehende Asserts ab Zeile 404).

## 2. Zustand pro Taster (`ButtonManager::ButtonState`)

Bestehende Felder unverändert; **neu** hinzu:

| Feld | Typ | Bedeutung | Reset |
|---|---|---|---|
| `clickCount` | `uint8_t` | Anzahl gültiger Drückflanken der laufenden Folge (0–3) | Zeitfenster überschritten, Taste zu lange gehalten, `resetMultiClick()` |
| `lastPressTime` | `uint32_t` | `millis()` der letzten gezählten Drückflanke | mit `clickCount` |
| `multiClickFlag` | `bool` | One-shot: Folge vollständig erkannt | Lesen über `wasMultiClicked()`, `resetMultiClick()` |
| `multiClickArmed` | `bool` | Die laufende Betätigung **würde** die Folge schließen — entschieden wird beim Loslassen | jede Loslass-Flanke, `resetMultiClick()` |

Unveränderte Felder: `pressed`, `lastRawState`, `lastChangeTime`, `pressTime`,
`clickedFlag`, `reportedHoldMs`, `bootLockout`.

### Zählregeln (in `update()`, nach dem Entprellen)

**Die Folge wird beim LOSLASSEN abgeschlossen, nicht beim Drücken.** Sonst
stünde der Alarm schon fest, bevor sich zeigt, ob der dritte Druck ein Klick
oder der Beginn eines Haltens ist — und der Edge Case „nach zwei Klicks beim
dritten Mal halten = nur ausschalten" (FR-011) wäre nicht umsetzbar.

```text
Drückflanke (entprellt):
    wenn bootLockout            → nichts (FR-004)
    sonst wenn btn == CONFIG    → clickedFlag = true   // klickt beim Drücken,
                                                       // zählt NICHT (FR-009)
    sonst (btn == OK):
        wenn clickCount > 0 und (now - lastPressTime) <= MULTI_CLICK_GAP_MS
                                → clickCount++
        sonst                   → clickCount = 1
        lastPressTime = now
        multiClickArmed = (clickCount >= MULTI_CLICK_COUNT)

Loslass-Flanke (nicht im bootLockout):
    heldMs  = now - pressTime
    wasHold = heldMs >= MULTI_CLICK_GAP_MS      // war kein Klick mehr

    wenn multiClickArmed und NICHT wasHold:
        multiClickFlag = true
        clickCount = 0
        // kein clickedFlag: der auslösende Klick verfällt (R-2)
    sonst:
        wenn wasHold → clickCount = 0           // FR-011: Halten bricht ab
        wenn btn == OK und heldMs < POWER_OFF_HOLD_MS:
            clickedFlag = true                  // OK klickt beim Loslassen
    multiClickArmed = false
```

Beim Auslösen werden zusätzlich die ausstehenden Klick-Ereignisse **beider**
Taster verworfen (`discardPendingClicks()`) — sonst quittiert ein während des
Bildaufbaus liegengebliebener Klick den Alarm sofort wieder (research.md R-2,
zweiter Nachtrag).

`lastActivity` (Grundlage der Inaktivitäts-Abschaltung) wird wie bisher bei
**jeder** entprellten Flanke gesetzt, auch im Boot-Lockout.

## 3. Gesten-Tabelle (autoritativ, ersetzt 004 §3)

| Geste | Splash | Config-Menü | Pfeile holen | Schießbetrieb | Alarm | Wartungsmodus |
|---|---|---|---|---|---|---|
| OK kurz (Klick) | Splash überspringen | bestätigen | nächste Passe / zurück | Passe beenden | Alarm quittieren | — |
| CONFIG kurz (Klick) | Splash überspringen | weiter / Wert ändern | Auswahl wechseln | — | — | — |
| **OK 3× ≤ 400 ms** | — | — | **Alarm** | **Alarm** | — (wirkungslos) | — |
| CONFIG 3× schnell | — | — | — | — | — | — |
| **beliebige Taste ≥ 3 s halten** | **Aus** | **Aus** | **Aus** | **Aus** | **Aus** | **Aus** |
| 60 min ohne Bedienung | — | **Aus** | **Aus** | — | — | — |
| beide Tasten beim Einschalten | Wartungsmodus | — | — | — | — | — |

Entfallen gegenüber 004: „BTN1 ≥ 2 s = Alarm" und die Ausnahme „im Schießbetrieb
kein Power-Off".

Weiterhin gültig: Boot-Lockout pro Taster (gesperrt bis zum ersten Loslassen)
und `MENU_LOCKOUT_MS` (400 ms Eingabesperre in `PfeileHolenMenu` nach dem
Zustandswechsel). Der Menü-Lockout wirkt **nur** auf die Menü-Aktion, nicht auf
die Zählung im `ButtonManager` — deshalb funktioniert FR-012 (Folge überlebt
Schießbetrieb → Pfeile holen) trotz Lockout.

## 4. Zustandsmaschine — geänderte Übergänge

Die fünf Zustände bleiben unverändert. Geändert werden nur Auslöser:

```text
STATE_SCHIESS_BETRIEB
  ── OK-Klick ───────────────────► STATE_PFEILE_HOLEN      (unverändert)
  ── 3× Klick (OK oder CONFIG) ──► STATE_ALARM             (NEU, ersetzt "OK ≥ 2 s")
  ── beliebige Taste ≥ 3 s ──────► Power-Off               (NEU, vorher gesperrt)

STATE_PFEILE_HOLEN
  ── 3× Klick (OK oder CONFIG) ──► STATE_ALARM             (NEU)

STATE_ALARM
  ── OK-Klick ───────────────────► STATE_PFEILE_HOLEN      (unverändert, + CMD_STOP)
  ── 3× Klick ───────────────────► (kein Übergang)         (FR-015)

alle Zustände
  ── beliebige Taste ≥ 3 s ──────► Power-Off               (jetzt zentral in update())
```

### Alarmfähigkeit (neue Hilfsfunktion)

```text
isAlarmCapable(State s) := s ∈ { STATE_SCHIESS_BETRIEB, STATE_PFEILE_HOLEN }
```

`setState(neu)` ruft `buttons.resetMultiClick()`, **außer** wenn alter **und**
neuer Zustand alarmfähig sind (R-3, FR-011 + FR-012).

## 5. Aufrufreihenfolge pro Schleifendurchlauf

```text
loopNormal()
  1. buttons.update()                    // auch aus dem e-Paper-Busy-Callback (R-1)
  2. radio.update()
  3. stateMachine.update()
       a. checkPowerOffGesture()         // NEU zentral, gilt für alle Zustände
       b. handle<Zustand>()
            - alarmfähige Zustände: zuerst Alarmfolge prüfen, dann Klicks
            - Wartezustände: checkIdleTimeout()
```

Reihenfolge in den alarmfähigen Handlern ist bindend: **Ausschalten vor Alarm
vor normalem Klick.** Damit gewinnt bei gleichzeitig erfüllten Bedingungen immer
die eindeutigere, langsamere Geste.

## 6. Keine persistenten Daten

Kein NVS-Zugriff, keine neuen Einstellungen, keine Protokolländerung. Alle neuen
Felder sind Laufzeitzustand im RAM und werden beim Einschalten mit 0
initialisiert.

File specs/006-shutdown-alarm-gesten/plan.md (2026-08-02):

# Implementation Plan: Entkopplung von Ausschalten und Alarm

**Branch**: `006-shutdown-alarm-gesten` | **Date**: 2026-08-02 | **Spec**: [spec.md](./spec.md)
**Input**: Feature specification from `/specs/006-shutdown-alarm-gesten/spec.md`

## Summary

Ausschalten und Alarm liegen heute beide auf „Taste halten" und werden nur über
den Betriebszustand auseinandergehalten. Künftig gilt: **Halten ≥ 3 s = Aus (in
jedem Zustand)**, **Dreifachklick ≤ 400 ms Abstand = Alarm (nur im Schießbetrieb
und in „Pfeile holen")**, und die Inaktivitäts-Abschaltung greift erst nach
60 statt 20 Minuten.

Technisch ist das eine reine Sender-Firmware-Änderung in drei Klassen
(`ButtonManager`, `StateMachine`, `Config.h`) plus einer kleinen Ergänzung im
Display-Layer. Der einzige nicht triviale Punkt: Der e-Paper-Refresh blockiert
300–400 ms und im Schießbetrieb läuft er im Sekundentakt — ohne Gegenmaßnahme
gingen die schnellen Klicks der Alarmfolge dort verloren. Gelöst über den
GxEPD2-Busy-Callback, der `ButtonManager::update()` auch während des Refreshs
weiterlaufen lässt (Details und Fallback: `research.md` R-1).

Keine Hardware-, Protokoll- oder Empfänger-Änderung.

## Technical Context

**Language/Version**: C++17, Arduino core for ESP32 (arduino-esp32 3.3.7)
**Primary Dependencies**: GxEPD2 (Busy-Callback, neu genutzt), Adafruit GFX; ESP-NOW unverändert
**Storage**: keine — kein NVS-Zugriff, keine neuen Einstellungen
**Testing**: Hardware-in-the-Loop nach `quickstart.md` (T-01…T-64); keine Unit-Test-Infrastruktur im Repo
**Target Platform**: Sender ESP32-S3-WROOM-1U-N16R8; Empfänger XIAO ESP32C3 **unverändert**
**Project Type**: Embedded-Firmware, flache Dateistruktur, zentrale `platformio.ini` im Repo-Root
**Performance Goals**: Alarmfolge < 1,5 s ab erstem Klick (SC-001), 9/10 Trefferquote (SC-001a), Erkennung zuverlässig trotz 300–400 ms Refresh-Blockade
**Constraints**: Betriebsstrom bleibt bei 0,20 W (SC-007); Zeitkonstanten `DEBOUNCE_MS (80) < MULTI_CLICK_GAP_MS (400) < POWER_OFF_HOLD_MS (3000)`; kein Pin-, Schaltplan- oder Protokoll-Eingriff
**Scale/Scope**: 5 Zustände, 2 Taster, ~6 Quelldateien im Ordner `Sender/`, geschätzt 120–150 geänderte Zeilen

## Constitution Check

*GATE: bestanden vor Phase 0 — und nach Phase 1 erneut geprüft (Ergebnis unten identisch).*

| Prinzip | Bewertung | Begründung |
|---|---|---|
| **I. Sicherheit Zuerst** (NON-NEGOTIABLE) | ✅ PASS | Der Alarm wird **zugänglicher**, nicht eingeschränkt: bisher nur im Schießbetrieb, künftig auch in „Pfeile holen". Zustandsübergänge bleiben deterministisch (feste Reihenfolge Aus → Alarm → Klick, `data-model.md` §5). Das neue Ausschalten im Schießbetrieb ist durch das autonome Passenende des Empfängers abgesichert (R-6). Funkvalidierung unverändert. **Auflage**: R-1 muss umgesetzt sein, sonst wäre die Alarmerkennung nicht deterministisch — Abnahme über T-23. |
| **II. Einfachheit & Zuverlässigkeit** | ✅ PASS | Zwei klar getrennte Gesten statt einer zustandsabhängigen Doppelbelegung — das ist netto weniger Bedienkomplexität. Vier neue Felder pro Taster, zwei neue Methoden, keine neue Bibliothek. Kein Konfigurationsmenü für die Schwellen (bewusst out of scope). |
| **III. Embedded-Hardware-Standards** | ✅ PASS | Keine Pin-Änderung (R-7), KiCad unangetastet. Neue Zeitwerte als `constexpr` in `Config.h` mit `static_assert` auf die Reihenfolge. Baubar mit `pio run -e sender`. |
| **IV. Testbarkeit & Validierung** | ✅ PASS | 33 HIL-Testfälle in `quickstart.md`, jeder auf eine FR/SC abgebildet. Grenzfälle (Halten statt Klicken, Zustandswechsel mitten in der Folge, Boot-Lockout) explizit abgedeckt. Stromverbrauch wird nachgemessen (T-64). |
| **V. Wartbarkeit & Dokumentation** | ✅ PASS | Gesten-Tabelle und Zustandsübergänge in `data-model.md` §3/§4 aktualisiert (ersetzt 004 §3) — erfüllt „Änderungen an Zustandsmaschine MÜSSEN State-Diagramm-Updates beinhalten". Header-Doku von `ButtonManager.h`, `CLAUDE.md` und `README.md` werden nachgezogen (FR-023). |

**Safety-kritische Änderung** → laut Constitution „Review-Anforderungen"
zusätzliches Review erforderlich, bevor das Feature als abgenommen gilt.

Keine Verstöße → **Complexity Tracking entfällt.**

## Project Structure

### Documentation (this feature)

```text
specs/006-shutdown-alarm-gesten/
├── plan.md                        # diese Datei
├── spec.md                        # Feature-Spezifikation (freigegeben)
├── research.md                    # Phase 0: R-1…R-8
├── data-model.md                  # Phase 1: Konstanten, Tasterzustand, Gesten-Tabelle
├── quickstart.md                  # Phase 1: HIL-Abnahme T-01…T-64
├── contracts/
│   └── button-gestures.md         # Phase 1: Vertrag ButtonManager ↔ StateMachine
├── checklists/
│   └── requirements.md            # Spec-Qualität (vollständig grün)
└── tasks.md                       # Phase 2 — NICHT von /speckit.plan erzeugt
```

### Source Code (repository root)

```text
platformio.ini                     # unverändert (env: sender / sender-release)

Sender/                            # NUR hier wird geändert
├── Config.h                       # ALARM_THRESHOLD_MS raus; MULTI_CLICK_* rein;
│                                  #   IDLE_POWER_OFF_MS 20 → 60 min; static_asserts
├── ButtonManager.h                # neu: wasMultiClicked(), resetMultiClick(); Doku
├── ButtonManager.cpp              # Zählwerk, Klick-Unterdrückung, Schwelle → 3 s
├── StateMachine.h                 # neu: isAlarmCapable(); Doku der Gesten
├── StateMachine.cpp               # Power-Off zentral; Alarm über Mehrfachklick;
│                                  #   resetMultiClick() in setState()
├── EpaperDisplay.h/.cpp           # Passthrough setBusyCallback() (R-1)
├── Sender.cpp                     # Busy-Callback registrieren; loopOta unverändert
└── SchiessBetriebMenu.h           # nur Kommentar (alte 2-s-Geste erwähnt)

Empfaenger/                        # NICHT angefasst, nicht neu geflasht
Schaltung-Sender/                  # NICHT angefasst (keine Hardware-Änderung)

CLAUDE.md, README.md               # Tastenbelegung nachziehen (FR-023)
specs/004-v3-esp32-port/data-model.md   # Hinweis: §3 durch 006 §3 ersetzt
```

**Structure Decision**: Bestehende flache Struktur unter `Sender/` beibehalten
(Projektkonvention, `platformio.ini` bleibt zentral im Repo-Root). Es entstehen
keine neuen Quelldateien — die Gestenerkennung gehört fachlich in den
`ButtonManager`, der sie bereits für Klick und Halten kapselt.

## Phase 0 — Research (abgeschlossen)

Ergebnisse in [`research.md`](./research.md):

| # | Thema | Entscheidung |
|---|---|---|
| R-1 | Klickverlust während des e-Paper-Refreshs | `GxEPD2_EPD::setBusyCallback()` → `buttons.update()` läuft im Refresh weiter; Fallback GPIO-Interrupts |
| R-2 | Auslösender Klick wirkt doppelt (quittiert den Alarm sofort) | `ButtonManager` unterdrückt Klick-Flag + kommende Loslass-Flanke |
| R-3 | Zähler über Zustandswechsel | `resetMultiClick()` in `setState()`, außer zwischen zwei alarmfähigen Zuständen |
| R-4 | Klickschwelle beim Loslassen von OK | `ALARM_THRESHOLD_MS` → `POWER_OFF_HOLD_MS` |
| R-5 | 60-min-Frist vs. Akku | +36 mAh im Nachlauf, unkritisch; DEBUG-Wert bleibt 60 s |
| R-6 | Ausschalten im laufenden Schießbetrieb | zulässig, autonomes Passenende deckt es ab |
| R-7 | Hardware | keine Änderung, KiCad unberührt |
| R-8 | Empfänger | unverändert, nicht neu flashen |

## Phase 1 — Design & Contracts (abgeschlossen)

- [`data-model.md`](./data-model.md) — Konstanten, neue Felder im Tasterzustand,
  Zählregeln, **autoritative Gesten-Tabelle** (ersetzt 004 §3), geänderte
  Zustandsübergänge, Aufrufreihenfolge
- [`contracts/button-gestures.md`](./contracts/button-gestures.md) — Vertrag
  `ButtonManager` ↔ `StateMachine`: neue API, 10 Garantien (G-1…G-10), 5
  Aufrufer-Pflichten (P-1…P-5), Display-Vertrag (D-1…D-3)
- [`quickstart.md`](./quickstart.md) — HIL-Abnahme, 33 Testfälle mit FR-Bezug

Agent-Kontext (`CLAUDE.md`) wurde über `.specify/scripts/bash/update-agent-context.sh claude`
aktualisiert.

## Umsetzungsreihenfolge (Vorschau für `/speckit.tasks`)

1. **Konstanten** (`Config.h`) — Basis für alles Weitere, isoliert prüfbar per Build
2. **Busy-Callback** (`EpaperDisplay`, `Sender.cpp`) — muss **vor** der
   Alarmfolge stehen, sonst testet T-23 ins Leere
3. **`ButtonManager`** — Zählwerk, Klick-Unterdrückung, neue Schwelle
4. **`StateMachine`** — Power-Off zentral, Alarmfolge in zwei Handlern,
   `resetMultiClick()` in `setState()`
5. **Dokumentation** — Header-Doku, `CLAUDE.md`, `README.md`, Hinweis in 004
6. **HIL-Abnahme** nach `quickstart.md`, danach Strommessung (T-64)

Reihenfolge 3 → 4 ist zwingend (die StateMachine ruft die neue API auf);
Schritt 2 ist unabhängig von 3/4 und kann parallel laufen.

## Risiken

| Risiko | Auswirkung | Gegenmaßnahme |
|---|---|---|
| Busy-Callback reicht nicht, Klicks gehen weiter verloren | Alarm unzuverlässig — safety-kritisch | T-23 (10 Wiederholungen) als Gate; Fallback GPIO-Interrupts steht in R-1 bereit |
| 400 ms Klickabstand für ungeübte Bediener zu eng | Alarm wird nicht ausgelöst | T-23/SC-001a misst die Trefferquote; Stellschraube ist genau eine Konstante (`MULTI_CLICK_GAP_MS`) |
| Fehlalarm durch schnelles Blättern | Unnötiger Betriebsstopp | Folge gilt nur in zwei Zuständen; T-26 und T-63 prüfen genau das |
| `MENU_LOCKOUT_MS` (400 ms) schluckt Klick 2/3 nach dem Passenende | T-30 schlägt fehl | Zählung liegt im `ButtonManager` **vor** dem Menü-Lockout — bewusst so entworfen (`data-model.md` §3) |

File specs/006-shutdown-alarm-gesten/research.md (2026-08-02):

# Phase 0 — Research: Entkopplung von Ausschalten und Alarm

**Feature**: 006-shutdown-alarm-gesten
**Datum**: 2026-08-02
**Status**: abgeschlossen — keine offenen NEEDS CLARIFICATION

## R-1: Tastendrücke gehen während des e-Paper-Refreshs verloren

**Problem**: `ButtonManager::update()` pollt `digitalRead()` und wird nur aus
`loopNormal()` aufgerufen. Ein Partial-Refresh des e-Papers blockiert laut
`EpaperDisplay.h` **300–400 ms**, ein Voll-Refresh rund 2 s. Im Schießbetrieb
läuft der 1-Hz-Countdown, d. h. das Gerät steht **etwa ein Drittel der Zeit** in
einem blockierenden Refresh. Ein Tastendruck, der vollständig in dieses Fenster
fällt (Drücken + Loslassen in < 300 ms — genau das Tempo eines Dreifachklicks),
wird nie gesehen.

Für die alte Alarm-Geste (2 s halten) war das egal: nach dem Refresh war der
Taster immer noch gedrückt. Für den Dreifachklick mit 400 ms Klickabstand ist es
tödlich — die sicherheitskritische Geste würde unzuverlässig (Constitution I:
„Alle Zustandsübergänge MÜSSEN vorhersehbar und deterministisch sein").

**Decision**: `GxEPD2_EPD::setBusyCallback()` nutzen. GxEPD2 ruft den
registrierten Callback in `_waitWhileBusy()` kontinuierlich auf; dort wird
`ButtonManager::update()` aufgerufen. Damit läuft die Tastenabfrage auch
während jedes Refreshs weiter — der blockierende Anteil ist fast vollständig
BUSY-Warten, die reine SPI-Übertragung (5 000 Byte) liegt im einstelligen
Millisekundenbereich.

Verifiziert in `.pio/libdeps/sender/GxEPD2/src/GxEPD2_EPD.h:96`:

```cpp
// register a callback function to be called during _waitWhileBusy continuously.
void setBusyCallback(void (*busyCallback)(const void*), const void* busy_callback_parameter = 0);
```

**Rationale**:
- ~10 Zeilen Code (Passthrough in `EpaperDisplay` + statische Callback-Funktion
  in `Sender.cpp`), keine Interrupts, keine IRAM-Attribute, keine
  volatile/ISR-Sicherheitsfragen → Constitution II (Einfachheit).
- Reentranz unkritisch: Der Callback läuft, während die Hauptschleife im
  Refresh steht; `ButtonManager::update()` liest nur GPIOs und setzt Flags. Die
  StateMachine wird nicht reentrant aufgerufen.
- Nutzt gleichzeitig der Ausschalt-Geste (Halte-Erkennung tickt weiter) und dem
  Überspringen des Splash-Screens.

**Alternatives considered**:
- **GPIO-Interrupts mit Zeitstempel-Ringpuffer**: robust gegen *jede* blockierende
  Stelle (auch `sendAlarmWithRetry()`, 600 ms). Verworfen: deutlich mehr
  Komplexität (ISR-Sicherheit, `IRAM_ATTR`, volatile Ringpuffer) für einen
  Gewinn, der nur Codepfade betrifft, in denen die Alarmfolge ohnehin nicht mehr
  ausgewertet wird (der Alarm ist dann schon ausgelöst). Bleibt der Fallback,
  falls der HIL-Test T-05 die Klickerkennung als unzuverlässig zeigt.
- **Refresh in Häppchen / nicht-blockierendes BUSY-Warten**: Umbau des gesamten
  Display-Layers, weit außerhalb des Feature-Scopes.
- **Klickabstand auf 800 ms aufmachen**: würde die Folge von normaler Bedienung
  nicht mehr unterscheidbar machen (widerspricht SC-004).

**Zwei Restlücken, bewusst offen gelassen** (in T-23 zu beobachten):

1. **Entprellung als Untergrenze**: `DEBOUNCE_MS` = 80 ms. Eine Betätigung, die
   kürzer als 80 ms Kontakt hat, wird gar nicht erst als Flanke registriert —
   das war schon vor diesem Feature so, fiel aber nicht auf, weil niemand
   schnell klicken musste. Ein sehr hektischer Dreifachklick kann damit einzelne
   Klicks verlieren. Bewusst **nicht** angefasst: 80 ms ist der erprobte V2-Wert,
   und ein Senken erhöht das Prellrisiko an allen anderen Stellen. Fällt SC-001a
   (9 von 10 Auslösungen) durch, ist das die zweite Stellschraube nach
   `MULTI_CLICK_GAP_MS`.
2. **Blockierende Funkaufrufe**: `RadioManager::sendCommand()` wartet bis zu
   100 ms je Sendeversuch (max. 3 Versuche + Retry-Delays). Steht ein Empfänger
   zur Verfügung, dauert das ~10 ms und ist irrelevant; fehlt er, kann ein
   Zustandswechsel ~450 ms ohne Tastenabfrage blockieren und einen Klick der
   Folge schlucken. Ohne Empfänger gäbe es aber ohnehin niemanden zu alarmieren,
   deshalb kein eigener Callback-Haken im `RadioManager`.

## R-2: Der auslösende Klick darf nicht doppelt wirken

**Problem**: Der dritte Klick der Folge löst den Alarm aus — und ist gleichzeitig
ein ganz normaler Klick. In `STATE_ALARM` quittiert ein OK-Klick den Alarm
sofort wieder (`handleAlarm()` → `CMD_STOP` → Pfeile holen). Ohne Gegenmaßnahme
wäre der Alarm nach wenigen Millisekunden von selbst wieder weg.

Die Rollen feuern zudem unterschiedlich: CONFIG setzt `clickedFlag` beim
**Drücken**, OK beim **Loslassen**.

**Decision**: Die Folge wird **auf der Loslass-Flanke** abgeschlossen, und die
auslösende Betätigung erzeugt dabei keinen Klick:
- Erreicht der Zähler beim Drücken die Schwelle, wird die Betätigung nur
  `multiClickArmed` markiert. Für die Rolle CONFIG (die sonst beim Drücken
  klickt) wird das `clickedFlag` dabei **zurückgehalten**.
- Beim Loslassen entscheidet die Haltedauer: kürzer als
  `MULTI_CLICK_GAP_MS` → Alarm ohne Klick; länger → die Folge verfällt und der
  zurückgehaltene CONFIG-Klick wird nachgeliefert.

**Nachtrag aus der Umsetzung (2026-08-02)**: Ursprünglich war das Auslösen auf
der Drückflanke geplant. Das kollidiert mit dem Edge Case „nach zwei Klicks beim
dritten Mal halten" (FR-011): Auf der Drückflanke steht der Alarm bereits fest,
bevor sich zeigt, ob die Betätigung ein Klick oder der Beginn eines Haltens ist
— das Gerät hätte alarmiert und danach abgeschaltet. Kosten der Umstellung: der
Alarm feuert rund 50–100 ms später (beim Loslassen des dritten Klicks), was
gegen SC-001 (< 1,5 s) unkritisch ist.

**Rationale**: Erfüllt FR-013 („Endzustand nach erkannter Folge MUSS Alarm
sein") an der einzigen Stelle, an der beide Rollen zusammenlaufen. Die
Alternative — die StateMachine räumt nach `setState(STATE_ALARM)` die Flags auf —
verteilt die Verantwortung über zwei Klassen und bricht, sobald ein weiterer
Zustand die Folge auswertet.

**Alternatives considered**: Klicks generell erst nach Ablauf des
Mehrfachklick-Fensters ausführen (800 ms Verzögerung auf *jeden* Klick) —
verworfen, weil das e-Paper ohnehin träge ist und die Bedienung dann als defekt
wahrgenommen würde.

**Zweiter Nachtrag aus dem Feldtest (2026-08-02)**: Den auslösenden Klick zu
unterdrücken reicht nicht. Beobachtet wurde: Der Alarmbildschirm erschien kurz
und das Gerät fiel sofort nach „Pfeile holen" zurück. Ursache sind die
**vorangegangenen** Klicks der Folge:

1. Klick 1 (OK) beendet im Schießbetrieb die Passe → `enterPfeileHolen()`
   blockiert mit Refresh und Gruppen-Kommando.
2. Klick 2 setzt währenddessen ein Klick-Ereignis, das niemand abholt — die
   StateMachine läuft ja nicht, nur der Busy-Callback pollt.
3. Klick 3 löst den Alarm aus. In `STATE_ALARM` quittiert der erste OK-Klick,
   und das ist genau das liegengebliebene Ereignis aus Schritt 2.

Dasselbe passiert ein zweites Mal *innerhalb* von `enterAlarm()`: Senden mit
Retries (bis 600 ms) plus Refresh (~500 ms) blockieren rund eine Sekunde, in der
weitere Klicks eingesammelt werden.

**Fix**: `ButtonManager::discardPendingClicks()` verwirft die Klick-Ereignisse
beider Taster. Aufgerufen wird sie an genau zwei Stellen — beim Auslösen der
Folge und am Ende von `enterAlarm()`. Alles, was während des Auslösens getippt
wurde, gehört zur Geste und nicht zur Quittierung.

## R-3: Zähler über Zustandswechsel hinweg

**Problem**: FR-012 verlangt, dass eine begonnene Folge den Wechsel
Schießbetrieb → Pfeile holen überlebt (der erste OK-Klick beendet die Passe).
FR-011 verlangt gleichzeitig, dass der Zähler beim Wechsel in einen nicht
alarmfähigen Zustand verworfen wird — sonst löst ein im Konfigurationsmenü
aufgebauter Zählerstand später im Schießbetrieb einen Fehlalarm aus.

**Decision**: Genau eine Regel in `StateMachine::setState()`:

```text
alarmfähig := { STATE_SCHIESS_BETRIEB, STATE_PFEILE_HOLEN }
wenn NICHT (alter Zustand alarmfähig UND neuer Zustand alarmfähig)
    → buttons.resetMultiClick()
```

**Rationale**: Eine einzige Stelle, deterministisch, deckt FR-011 und FR-012
zusammen ab. Insbesondere setzt der Eintritt in `STATE_ALARM` den Zähler zurück
(Alarm ist nicht alarmfähig) — damit ist FR-015 („erneute Folge im Alarm
wirkungslos") ohne Sonderfall erfüllt, und beim Quittieren nach „Pfeile holen"
startet die Zählung ebenfalls sauber bei null.

**Alternatives considered**: Zähler nur per Zeitfenster verfallen lassen —
verworfen, weil ein Zählerstand von 2 aus dem Konfigurationsmenü dann bis zu
400 ms in den Schießbetrieb hineinreicht.

## R-4: Klick-Schwelle beim Loslassen von OK

**Problem**: `ButtonManager::update()` erzeugt den OK-Klick beim Loslassen nur,
wenn die Betätigung kürzer als `ALARM_THRESHOLD_MS` (2 s) war. Diese Konstante
entfällt mit FR-016. Ohne Ersatz würde jede Betätigung als Klick gelten — auch
die abgebrochene Ausschalt-Geste.

**Decision**: Schwelle auf `POWER_OFF_HOLD_MS` (3 s) umstellen.

**Rationale**: Deckt sich exakt mit dem geforderten Verhalten (Spec, US2
Szenario 3: „kürzer als 3 s gehalten → wirkt als normaler Klick"), und es bleibt
bei genau einer Schwelle pro Taster. `ALARM_THRESHOLD_MS` wird ersatzlos
gelöscht, damit kein toter Wert zurückbleibt (Constitution: Magic Numbers /
Wartbarkeit).

## R-5: 60-Minuten-Abschaltung vs. Batterielaufzeit

**Problem**: Constitution fordert ≥ 8 h Batterielaufzeit; die Verdreifachung der
Idle-Frist erhöht den Verbrauch im Fall „vergessen eingeschaltet".

**Decision**: `IDLE_POWER_OFF_MS` von 20 auf 60 Minuten anheben, DEBUG-Wert
(`DEBUG_SHORT_TIMES` → 60 s) unverändert lassen.

**Rationale**: Der gemessene Betriebsstrom liegt bei 0,20 W (≈ 54 mA bei 3,7 V).
Die zusätzlichen 40 Minuten Nachlauf kosten rund **36 mAh** — bei einem
LiPo-Akku in der verbauten Größenordnung deutlich unter 5 % der Kapazität und
ohne Einfluss auf die geforderten 8 h *aktiver* Nutzung. Der Zweck der
Abschaltung („im Koffer vergessenes Gerät", Kommentar in `Config.h`) bleibt
erhalten. Der DEBUG-Wert bleibt bei 60 s, sonst wird der HIL-Test unbrauchbar.

**Alternatives considered**: 45 Minuten als Kompromiss — verworfen, weil die
Vorgabe „eine Stunde" explizit ist und Mittagspausen bei Turnieren regelmäßig
länger als 45 Minuten dauern.

## R-6: Ausschalten im Schießbetrieb — Sicherheitsbetrachtung

**Problem**: FR-002 macht die Ausschalt-Geste erstmals auch im laufenden
Schießbetrieb verfügbar. Constitution I verlangt einen sicheren Zustand bei
Kommunikationsausfall.

**Decision**: Keine zusätzliche Absicherung, kein Rückfragedialog. Der Sender
schaltet ab, der Empfänger führt die laufende Passe autonom zu Ende (FR-004 der
V3-Spec, im Empfänger unverändert implementiert).

**Rationale**: Das ist genau der Fall, für den das autonome Passenende gebaut
wurde — ein abgeschalteter Sender ist funktional identisch zu einem Sender außer
Funkreichweite. Ein Bestätigungsdialog widerspräche der Ein-Knopf-Bedienung
(Constitution II) und würde 3 s Halten + Bestätigung erfordern. Zusätzlich ist
die Fehlbedienung unwahrscheinlich: 3 s ununterbrochenes Halten passiert nicht
versehentlich.

## R-7: Keine Hardware-Änderung

Geprüft gegen `specs/004-v3-esp32-port/contracts/hardware-pins.md` und die
KiCad-Quelle `Schaltung-Sender/`: Das Feature ändert **keine** Pin-Belegung,
keine Beschaltung und keine Bauteilwerte. Beide Taster sind bereits als
Eingänge mit definierten Pegeln vorhanden (BTN1/GPIO15 aktiv HIGH über Teiler
R2/R7, BTN2/GPIO9 aktiv LOW mit internem Pullup). Constitution III/V
(„Änderungen an Pin-Belegungen zuerst im KiCad") ist damit nicht berührt.

## R-8: Empfänger bleibt unberührt

Das Funkprotokoll (`Commands.h`, byte-identisch auf beiden Seiten) und das
`CMD_ALARM`-Verhalten des Empfängers bleiben unverändert. Geändert wird
ausschließlich, **wodurch** der Sender `CMD_ALARM` auslöst. `Empfaenger/` wird in
diesem Feature nicht angefasst — auch nicht neu geflasht.

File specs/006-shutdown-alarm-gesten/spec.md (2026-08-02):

# Feature Specification: Entkopplung von Ausschalten und Alarm

**Feature Branch**: `006-shutdown-alarm-gesten`
**Created**: 2026-08-02
**Status**: Draft
**Input**: User description: "Aktuell liegen shutdown und alarm auf der selben Nutzerinteraktion. Künftig soll folgendes gelten: Bei einem langen Tastendruck (> 3sek), egal welche Taste, soll das Gerät herunterfahren. Wenn eine Taste sehr schnell hintereinander mehr als drei mal gedrückt wird, soll der Alarm Modus gelten. Weiterhin soll der timeout shutdown erst nach einer Stunde erfolgen."

## Ausgangslage (Problem)

An der Bedieneinheit liegen Ausschalten und Not-Alarm heute auf derselben
Nutzerinteraktion — dem Halten einer Taste. Unterschieden wird allein über den
Betriebszustand: im Schießbetrieb löst Halten den Alarm aus, in allen anderen
Zuständen schaltet Halten das Gerät ab. Daraus folgen drei Probleme:

1. **Nicht vorhersagbar**: Dieselbe Handbewegung hat je nach Bildschirm eine
   völlig andere Wirkung. Wer die Ampel abschalten will, muss wissen, in welchem
   Zustand das Gerät gerade steht.
2. **Fehlbedienung mit Folgen**: Wer im Schießbetrieb ausschalten will, löst
   stattdessen einen Alarm für die ganze Schießlinie aus — umgekehrt kann im
   Schießbetrieb gar nicht ausgeschaltet werden.
3. **Zu kurze Abschaltzeit**: Die automatische Abschaltung nach Inaktivität
   greift bereits nach 20 Minuten. Bei Turnieren mit längeren Pausen
   (Scheibenwechsel, Wertung, Mittagspause) schaltet sich die Bedieneinheit ab,
   während der Betrieb noch läuft.

## User Scenarios & Testing *(mandatory)*

### User Story 1 - Not-Alarm zuverlässig auslösen (Priority: P1)

Ein Schütze betritt unerwartet die Schießlinie oder es kommt zu einem Zwischen-
fall. Der Bediener drückt die OK-Taste dreimal schnell hintereinander;
die Anlage geht sofort in den Alarmzustand und stoppt den laufenden Durchgang.
Das gilt in den Phasen, in denen Menschen an der Schießlinie sein können:
Schießbetrieb und „Pfeile holen".

**Why this priority**: Der Alarm ist die sicherheitsrelevante Funktion der
Anlage. Er muss unter Stress ohne Nachdenken und ohne Wartezeit auslösbar sein
und darf niemals versehentlich zum Ausschalten führen.

**Independent Test**: Vollständig testbar, indem im Schießbetrieb und in „Pfeile
holen" je die Alarmfolge auf beiden Tasten ausgeführt wird und geprüft wird,
dass die Anzeigeeinheit den Alarm meldet und die Bedieneinheit den
Alarmbildschirm zeigt — ohne dass das Gerät abschaltet; im Konfigurationsmenü
darf dieselbe Folge keinen Alarm auslösen.

**Acceptance Scenarios**:

1. **Given** das Gerät ist im Schießbetrieb, **When** der Bediener die OK-Taste
   dreimal mit höchstens 400 ms Abstand drückt, **Then** wechselt die
   Bedieneinheit in den Alarmzustand und die Anzeigeeinheit signalisiert Alarm.
1a. **Given** das Gerät ist im Schießbetrieb, **When** der Bediener die
   CONFIG-Taste dreimal schnell drückt, **Then** wird **kein** Alarm ausgelöst.
2. **Given** das Gerät ist im Zustand „Pfeile holen", **When** der Bediener die
   Alarmfolge ausführt, **Then** wechselt die Anlage ebenfalls in den
   Alarmzustand.
3. **Given** das Gerät ist im Schießbetrieb, **When** der Bediener eine Taste
   ununterbrochen hält, **Then** wird **kein** Alarm ausgelöst (das Halten ist
   jetzt ausschließlich die Ausschalt-Geste).
4. **Given** der Bediener drückt die Taste zwar dreimal, aber mit mehr als
   400 ms Abstand, **When** die Folge abgeschlossen ist, **Then** wird kein
   Alarm ausgelöst, sondern jeder Druck wirkt als normaler Klick.
5. **Given** das Gerät steht im Konfigurationsmenü, **When** der Bediener
   dreimal schnell klickt (zügiges Hochzählen eines Werts), **Then** wird kein
   Alarm ausgelöst und die Werte zählen normal weiter.
6. **Given** die Anlage steht im Alarmzustand, **When** der Bediener die
   Alarmfolge erneut ausführt, **Then** bleibt der Alarmzustand unverändert
   bestehen (keine Doppelauslösung, kein Zustandssprung).
7. **Given** der erste Klick der Folge hat im Schießbetrieb bereits die Passe
   beendet (Zustandswechsel nach „Pfeile holen"), **When** die beiden weiteren
   Klicks rechtzeitig folgen, **Then** wird der Alarm trotzdem ausgelöst — der
   Zählerstand überlebt den Zustandswechsel.

---

### User Story 2 - Gerät jederzeit vorhersagbar ausschalten (Priority: P2)

Der Bediener ist mit dem Schießen fertig oder will das Gerät verstauen. Er hält
eine beliebige Taste länger als drei Sekunden gedrückt; das Gerät verabschiedet
sich und schaltet ab — aus jedem Betriebszustand heraus, auch aus dem laufenden
Schießbetrieb und aus dem Alarmzustand.

**Why this priority**: Löst das eigentliche Bedienproblem (gleiche Geste, zwei
Bedeutungen), ist aber ohne die neue Alarm-Geste aus User Story 1 nicht sinnvoll
einführbar — das Halten muss erst frei werden.

**Independent Test**: Vollständig testbar, indem in jedem der fünf
Betriebszustände nacheinander jede Taste > 3 s gehalten und geprüft wird, dass
das Gerät jedes Mal abschaltet.

**Acceptance Scenarios**:

1. **Given** das Gerät ist eingeschaltet und in einem beliebigen
   Betriebszustand, **When** eine beliebige Taste länger als 3 s gehalten wird,
   **Then** zeigt die Bedieneinheit den Abschaltbildschirm und schaltet ab.
2. **Given** das Gerät ist im Schießbetrieb mit laufendem Countdown, **When**
   eine Taste > 3 s gehalten wird, **Then** schaltet das Gerät ab (bisher: Alarm
   statt Abschalten).
3. **Given** eine Taste wird kürzer als 3 s gehalten und dann losgelassen,
   **When** die Taste losgelassen wird, **Then** schaltet das Gerät nicht ab,
   sondern der Druck wirkt als normaler Klick.
4. **Given** das Gerät wird gerade über die Einschalt-Taste eingeschaltet und
   der Bediener hält diese länger als 3 s, **When** das Gerät hochfährt,
   **Then** schaltet es sich **nicht** sofort wieder ab.

---

### User Story 3 - Längere Pausen ohne Selbstabschaltung (Priority: P3)

Bei einem Turnier liegt zwischen zwei Passen eine längere Pause (Wertung,
Scheibenwechsel, Mittagspause). Die Bedieneinheit bleibt eingeschaltet und
betriebsbereit, statt sich nach 20 Minuten abzuschalten.

**Why this priority**: Reiner Komfortgewinn ohne Sicherheitsbezug; unabhängig
von den beiden Gesten umsetzbar und testbar.

**Independent Test**: Vollständig testbar, indem das Gerät in einem Wartezustand
ohne Bedienung stehen bleibt und geprüft wird, dass es nach 20 und nach 55
Minuten noch läuft und nach 60 Minuten abschaltet.

**Acceptance Scenarios**:

1. **Given** das Gerät steht unbedient in einem Wartezustand, **When** 59
   Minuten ohne Bedienung vergangen sind, **Then** ist das Gerät noch
   eingeschaltet und bedienbar.
2. **Given** das Gerät steht unbedient in einem Wartezustand, **When** 60
   Minuten ohne Bedienung vergangen sind, **Then** schaltet es mit dem Hinweis
   auf die automatische Abschaltung ab.
3. **Given** das Gerät steht 45 Minuten unbedient, **When** der Bediener eine
   Taste drückt, **Then** beginnt die Stunde von vorn.

---

### Edge Cases

- **Mehrfachklick trifft auf normale Aktionen**: Jeder einzelne Tastendruck der
  Alarmfolge wirkt zunächst als normaler Klick (Passe beenden, weiter …). Beim
  Erreichen der Alarm-Schwelle überschreibt der Alarmzustand alles zuvor
  Ausgelöste. Der Bediener darf am Ende der Folge in keinem anderen Zustand als
  „Alarm" landen.
- **Zustandswechsel mitten in der Folge**: Löst der erste Klick einen Wechsel
  zwischen zwei alarmfähigen Zuständen aus (Schießbetrieb → Pfeile holen), läuft
  die Zählung weiter. Wechselt das Gerät dagegen in einen nicht alarmfähigen
  Zustand (z. B. Konfigurationsmenü), wird die Folge verworfen.
- **Übergang Mehrfachklick → Halten**: Wird nach zwei schnellen Klicks die Taste
  beim dritten Mal gehalten, gilt allein die Halte-Geste — nach 3 s schaltet das
  Gerät ab, ein Alarm wird nicht ausgelöst.
- **Alarmfolge im Konfigurationsmenü**: Dort wird nicht gezählt; schnelles
  Hochzählen von Werten bleibt folgenlos. Ausschalten per Halten funktioniert
  dort weiterhin.
- **Beide Tasten gleichzeitig gehalten**: Das ist die Einstiegsgeste in den
  Wartungsmodus beim Einschalten. Im laufenden Betrieb löst gleichzeitiges
  Halten beider Tasten genau eine Abschaltung aus (nicht zwei konkurrierende).
- **Klicks auf zwei verschiedene Tasten**: Abwechselnde schnelle Klicks auf OK
  und CONFIG zählen nicht als Alarmfolge — gezählt wird ausschließlich OK. Drei
  OK-Klicks im Zeitfenster lösen den Alarm aber auch dann aus, wenn dazwischen
  CONFIG gedrückt wurde.
- **Einschalt-Druck**: Der Tastendruck, mit dem das Gerät eingeschaltet wird,
  zählt weder als Klick der Alarmfolge noch als Beginn der Halte-Geste.
- **Alarm während des Abschaltbildschirms**: Ist die Abschaltsequenz einmal
  gestartet, ist sie nicht mehr abbrechbar; weitere Tastendrücke bleiben ohne
  Wirkung.
- **Automatische Abschaltung im laufenden Schießbetrieb**: Während einer
  laufenden Passe und im Alarmzustand greift die Inaktivitäts-Abschaltung
  weiterhin nicht — nur in den Wartezuständen.
- **Alarm im Wartungsmodus**: Im Wartungsmodus (OTA) gibt es keinen
  Schießbetrieb und keine Alarmfolge; dort bleibt die Tastenbelegung wie bisher.

## Requirements *(mandatory)*

### Functional Requirements

**Ausschalten per langem Tastendruck**

- **FR-001**: Das System MUSS abschalten, wenn eine beliebige Taste länger als
  3 Sekunden ununterbrochen gedrückt gehalten wird.
- **FR-002**: Die Ausschalt-Geste MUSS in **allen** Betriebszuständen wirken —
  einschließlich laufendem Schießbetrieb und Alarmzustand.
- **FR-003**: Das System MUSS beide Tasten für die Ausschalt-Geste gleichwertig
  behandeln; die Wirkung darf nicht davon abhängen, welche Taste gehalten wird.
- **FR-004**: Das System MUSS die Ausschalt-Geste ignorieren, solange die
  gehaltene Taste seit dem Einschalten noch nicht einmal losgelassen wurde
  (Schutz vor sofortigem Wiederausschalten beim Einschalten).
- **FR-005**: Das System MUSS vor dem Abschalten einen Abschalthinweis anzeigen
  und die Anzeige geordnet stilllegen (unverändert zum heutigen Verhalten).
- **FR-006**: Das System MUSS die Abschaltung genau einmal ausführen, auch wenn
  die Geste auf beiden Tasten gleichzeitig erfüllt wird.

**Alarm per schneller Mehrfachbetätigung**

- **FR-007**: Das System MUSS den Alarmzustand auslösen, wenn dieselbe Taste
  dreimal so gedrückt wird, dass zwischen zwei aufeinanderfolgenden Klicks
  höchstens 400 ms liegen (Dreifachklick, Gesamtdauer damit höchstens 800 ms).
- **FR-008**: Das System MUSS ausschließlich OK-Klicks zur Folge zählen; ein
  zwischengeschobener CONFIG-Klick darf die Folge weder weiterzählen noch
  abbrechen.
- **FR-009**: Das System MUSS die Alarmfolge **ausschließlich** auf der OK-Taste
  auswerten. Ein Dreifachklick auf CONFIG DARF keinen Alarm auslösen —
  CONFIG blättert durch Menüs und zählt Werte hoch, dort ist zügiges Tippen
  normale Bedienung. *(Geändert am 2026-08-02 nach dem Feldtest; ursprünglich
  waren beide Tasten vorgesehen.)*
- **FR-010**: Das System MUSS die Alarmfolge ausschließlich in den Zuständen
  „Schießbetrieb" und „Pfeile holen" auswerten. In allen übrigen Zuständen
  (Startbildschirm, Konfigurationsmenü, Alarm, Wartungsmodus) MUSS die Folge
  wirkungslos bleiben — insbesondere darf zügiges Blättern oder Hochzählen im
  Konfigurationsmenü keinen Alarm auslösen.
- **FR-011**: Das System MUSS den Alarmzähler zurücksetzen, sobald das
  Zeitfenster überschritten wird, die Taste gehalten statt geklickt wird oder
  das Gerät in einen nicht alarmfähigen Zustand wechselt.
- **FR-012**: Das System MUSS eine begonnene Alarmfolge über einen Wechsel
  zwischen den beiden alarmfähigen Zuständen hinweg weiterzählen (Schießbetrieb
  → Pfeile holen durch den ersten Klick).
- **FR-013**: Das System MUSS beim Auslösen des Alarms den Alarmzustand über
  alle zuvor durch die Einzelklicks ausgelösten Zustandswechsel stellen; der
  Endzustand nach einer erkannten Alarmfolge MUSS „Alarm" sein.
- **FR-014**: Das System MUSS den Alarm wie bisher an die Anzeigeeinheit senden
  (inklusive der bestehenden Wiederholversuche) und das Ergebnis der Übertragung
  auf der Bedieneinheit anzeigen.
- **FR-015**: Das System MUSS eine erneut erkannte Alarmfolge im bereits
  stehenden Alarmzustand wirkungslos lassen.
- **FR-016**: Das System DARF die bisherige Alarm-Geste (Taste ≥ 2 s halten)
  NICHT mehr auswerten.

**Quittieren und übrige Bedienung**

- **FR-017**: Der Bediener MUSS den Alarm weiterhin mit einem kurzen Klick
  quittieren können; die Anlage geht danach in den Zustand „Pfeile holen".
- **FR-018**: Das System MUSS alle übrigen Kurzklick-Funktionen (Menü weiter,
  Wert ändern, bestätigen, Passe beenden) unverändert beibehalten.

**Automatische Abschaltung**

- **FR-019**: Das System MUSS die automatische Abschaltung wegen Inaktivität
  erst nach 60 Minuten ohne Bedienung auslösen (bisher 20 Minuten).
- **FR-020**: Das System MUSS jeden Tastendruck und jeden Zustandswechsel als
  Aktivität werten und die Frist neu starten (unverändert zum heutigen
  Verhalten).
- **FR-021**: Das System MUSS die automatische Abschaltung weiterhin nur in den
  Wartezuständen anwenden, nicht im laufenden Schießbetrieb und nicht im
  Alarmzustand.
- **FR-022**: Das System MUSS die automatische Abschaltung als solche kenntlich
  machen (Hinweistext auf dem Abschaltbildschirm), damit sie nicht als Defekt
  wahrgenommen wird.

**Dokumentation**

- **FR-023**: Die Bedienanleitung/Projektdokumentation MUSS die neue
  Tastenbelegung beschreiben (langer Druck = Aus, schnelle Mehrfachbetätigung =
  Alarm, 60 Minuten Inaktivitätsabschaltung).

## Success Criteria *(mandatory)*

### Measurable Outcomes

- **SC-001**: Ein Bediener löst den Alarm aus dem laufenden Schießbetrieb in
  unter 1,5 Sekunden ab dem ersten Tastendruck aus.
- **SC-001a**: Die Alarmfolge gelingt ungeübten Bedienern in mindestens 9 von 10
  Versuchen im ersten Anlauf (Nachweis, dass die 400-ms-Schwelle nicht zu eng
  gewählt ist).
- **SC-002**: In 100 % der geprüften Betriebszustände (alle fünf) schaltet das
  Gerät durch langes Halten jeder der beiden Tasten ab — 10 von 10 Versuchen je
  Kombination.
- **SC-003**: Kein einziger Ausschaltversuch löst einen Alarm aus und keine
  Alarmauslösung schaltet das Gerät ab (0 Verwechslungen in 20 Testdurchläufen).
- **SC-004**: Normale Bedienung erzeugt keinen Fehlalarm: 30 Minuten Bedienung
  im üblichen Tempo — inklusive zügigem Hochzählen der Werte im
  Konfigurationsmenü und wiederholtem Passe-Beenden — ohne eine einzige
  ungewollte Alarmauslösung.
- **SC-005**: Das Gerät bleibt bei Inaktivität mindestens 59 Minuten
  eingeschaltet und schaltet spätestens nach 61 Minuten ab.
- **SC-006**: Ein Bediener, der die Anlage zum ersten Mal benutzt, kann nach
  einer Erklärung von unter 30 Sekunden sowohl Alarm auslösen als auch
  ausschalten, ohne die Anleitung erneut zu lesen.
- **SC-007**: Die Änderung erhöht die gemessene Leistungsaufnahme im
  Normalbetrieb nicht messbar gegenüber dem heutigen Stand (0,20 W).

## Assumptions

- **A-001**: „Lang" bedeutet mehr als 3 Sekunden ununterbrochenes Halten; die
  bisherige Schwelle von 3 s wird beibehalten, da sie sich bewährt hat.
- **A-002**: „Sehr schnell hintereinander mehr als drei Mal" wird als
  Dreifachklick mit höchstens 400 ms Klickabstand umgesetzt (Entscheidung vom
  2026-08-02). Drei statt vier Klicks, weil die Geste unter Stress sicher
  ausführbar sein muss; dafür ein engeres Zeitfenster, damit sie sich klar von
  normaler Bedienung unterscheidet.
- **A-002a**: Die Beschränkung auf „Schießbetrieb" und „Pfeile holen"
  (Entscheidung vom 2026-08-02) deckt genau die Phasen ab, in denen Personen an
  der Schießlinie sein können, und hält das Konfigurationsmenü fehlalarmfrei.
- **A-002b**: Die Alarmfolge liegt allein auf OK (Entscheidung vom 2026-08-02
  nach dem Feldtest, ersetzt die ursprüngliche Festlegung „beide Tasten"). Eine
  Taste für die Sicherheitsfunktion ist eindeutiger zu vermitteln, und CONFIG
  bleibt vollständig frei für die Navigation.
- **A-003**: Die Hardware bleibt unverändert; es gibt weiterhin genau zwei
  Taster an der Bedieneinheit, und eingeschaltet wird hardwareseitig weiterhin
  über den Config-Taster.
- **A-004**: Der Wartungsmodus (beide Tasten beim Einschalten) bleibt
  unverändert erreichbar und ist von dieser Änderung nicht betroffen.
- **A-005**: Das Funkprotokoll zur Anzeigeeinheit bleibt unverändert — geändert
  wird ausschließlich, wie der Alarm an der Bedieneinheit ausgelöst wird.
- **A-006**: Die längere Abschaltfrist (60 statt 20 Minuten) ist ein bewusster
  Kompromiss zulasten der Akkulaufzeit; sie schützt weiterhin vor dem im Koffer
  vergessenen Gerät.
- **A-007**: Der Alarm bleibt an der Bedieneinheit ohne akustische Rückmeldung
  (kein Summer verbaut); die Rückmeldung erfolgt über den Bildschirm und die
  Anzeigeeinheit.

## Out of Scope

- Änderungen an der Anzeigeeinheit (Alarmsignalisierung, Lautstärke,
  Quittierung dort)
- Änderungen am Funkprotokoll oder an den Kommandos
- Zusätzliche Tasten, Hardwareänderungen oder ein Summer an der Bedieneinheit
- Konfigurierbarkeit der Schwellenwerte über das Menü (feste Werte)
- Weitere Stromsparmaßnahmen

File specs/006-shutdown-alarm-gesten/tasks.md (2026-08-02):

---

description: "Task list for 006-shutdown-alarm-gesten"
---

# Tasks: Entkopplung von Ausschalten und Alarm

**Input**: Design documents from `/specs/006-shutdown-alarm-gesten/`
**Prerequisites**: plan.md, spec.md, research.md, data-model.md, contracts/button-gestures.md, quickstart.md

**Tests**: Es gibt keine Unit-Test-Infrastruktur im Repo. Die Validierung erfolgt
als Hardware-in-the-Loop-Abnahme nach `quickstart.md` (Constitution IV) — die
HIL-Tasks stehen am Ende jeder Story-Phase.

**Organization**: Nach User Story gruppiert, damit jede Story einzeln geflasht
und am Gerät abgenommen werden kann.

## Format: `[ID] [P?] [Story] Description`

- **[P]**: parallel möglich (andere Datei, keine offenen Abhängigkeiten)
- **[Story]**: US1 = Alarm (P1), US2 = Ausschalten (P2), US3 = 60-min-Abschaltung (P3)
- Alle Pfade sind repo-relativ; gebaut wird immer aus dem Repo-Root

## Path Conventions

Embedded-Firmware, flache Struktur: alle Quelldateien liegen direkt in
`Sender/`. `platformio.ini` liegt im Repo-Root; Build immer mit
`pio run -e sender` aus `/d/git/Bogenampel`. `Empfaenger/` und
`Schaltung-Sender/` werden in diesem Feature **nicht** angefasst.

---

## Phase 1: Setup

**Purpose**: Ausgangszustand absichern, damit spätere Fehler zuordenbar sind

- [X] T001 Baseline-Build prüfen: `pio run -e sender` aus dem Repo-Root (`platformio.ini`) muss fehlerfrei durchlaufen, bevor irgendetwas geändert wird
- [ ] T002 Baseline-Verhalten am Gerät festhalten: Sender flashen und die Ausgangslage aus `specs/006-shutdown-alarm-gesten/quickstart.md` notieren — heute löst OK ≥ 2 s im Schießbetrieb den Alarm aus und Ausschalten ist dort **nicht** möglich (Gegenprobe für T-04/T-33)

---

## Phase 2: Foundational (Blocking Prerequisites)

**Purpose**: Konstanten und die Tastenabfrage während des e-Paper-Refreshs — ohne
diese Phase ist die Alarmfolge nicht zuverlässig erkennbar (research.md R-1)

**⚠️ CRITICAL**: Keine Story-Arbeit vor Abschluss dieser Phase

- [X] T003 In `Sender/Config.h` (namespace `Timing`, bei den Tastergesten ~Zeile 277) `MULTI_CLICK_COUNT = 3` und `MULTI_CLICK_GAP_MS = 400` als `constexpr` ergänzen, mit Kommentar-Verweis auf FR-007/A-002 — `ALARM_THRESHOLD_MS` bleibt in dieser Phase noch stehen
- [X] T004 In `Sender/Config.h` (bei den bestehenden `static_assert`s ab ~Zeile 404) die Reihenfolge absichern: `DEBOUNCE_MS < MULTI_CLICK_GAP_MS < POWER_OFF_HOLD_MS` (data-model.md §1)
- [X] T005 [P] In `Sender/EpaperDisplay.h` und `Sender/EpaperDisplay.cpp` einen Passthrough `void setBusyCallback(void (*cb)(const void*), const void* param = nullptr)` auf `display.epd2.setBusyCallback()` ergänzen, mit Doxygen-Kommentar zum Zweck (Tastenabfrage während des 300–400 ms blockierenden Refreshs, research.md R-1)
- [X] T006 In `Sender/Sender.cpp` eine statische Callback-Funktion anlegen, die `buttons.update()` aufruft, und sie in `setup()` über `epaper.setBusyCallback()` registrieren (nach der Display-Initialisierung, vor `stateMachine.begin()`); Kommentar mit Verweis auf Contract D-1…D-3 (abhängig von T005)
- [X] T007 In `Sender/ButtonManager.cpp` (`update()`, Loslass-Zweig ~Zeile 79) die Klick-Schwelle der Rolle OK von `Timing::ALARM_THRESHOLD_MS` auf `Timing::POWER_OFF_HOLD_MS` umstellen (Contract G-8, research.md R-4)
- [ ] T008 Build-Gate: `pio run -e sender`, flashen und am Gerät prüfen, dass das Display unverändert refresht und Klicks in allen Menüs weiterhin ankommen (Regression zu T002)

**Checkpoint**: Tastenabfrage läuft auch während des Refreshs — Story-Arbeit kann beginnen

---

## Phase 3: User Story 1 - Not-Alarm zuverlässig auslösen (Priority: P1) 🎯 MVP

**Goal**: Der Alarm wird durch einen Dreifachklick (≤ 400 ms Abstand, beide
Taster gleichwertig) ausgelöst — in „Schießbetrieb" und „Pfeile holen". Die alte
2-s-Halte-Geste entfällt.

**Independent Test**: Im Schießbetrieb und in „Pfeile holen" je dreimal schnell
klicken → Alarmbildschirm + Empfänger alarmiert; dieselbe Folge im
Konfigurationsmenü löst nichts aus; OK 2 s halten löst keinen Alarm mehr
(quickstart.md T-20…T-33).

### Implementation for User Story 1

- [X] T009 [US1] In `Sender/ButtonManager.h` die Struktur `ButtonState` um `clickCount` (uint8_t), `lastPressTime` (uint32_t), `multiClickFlag` (bool) und `multiClickArmed` (bool) erweitern (data-model.md §2) — *umgesetzt als `multiClickArmed` statt `suppressClickOnRelease`, siehe T014*
- [X] T010 [US1] In `Sender/ButtonManager.h` die Methoden `bool wasMultiClicked(Button btn)` und `void resetMultiClick()` mit Doxygen-Kommentaren deklarieren (contracts/button-gestures.md §1)
- [X] T011 [US1] Im Konstruktor von `Sender/ButtonManager.cpp` die vier neuen Felder mit 0/false initialisieren
- [X] T012 [US1] In `Sender/ButtonManager.cpp` (`update()`, Drück-Flanken-Zweig ~Zeile 59) das Zählwerk ergänzen: im Boot-Lockout nicht zählen; `clickCount++` wenn `now - lastPressTime <= MULTI_CLICK_GAP_MS`, sonst `clickCount = 1`; `lastPressTime = now` (data-model.md §2, Contract G-2/G-6)
- [X] T013 [US1] In `Sender/ButtonManager.cpp` (`update()`, Loslass-Zweig) den Folgenabbruch beim Halten ergänzen: dauerte die Betätigung ≥ `MULTI_CLICK_GAP_MS`, `clickCount = 0` setzen (Contract G-5, FR-011)
- [X] T014 [US1] In `Sender/ButtonManager.cpp` (`update()`, Drück-Flanke) nur **scharfstellen**: bei `clickCount >= MULTI_CLICK_COUNT` → `multiClickArmed = true` und den CONFIG-Klick zurückhalten. **Abweichung vom ursprünglichen Entwurf**: das Auslösen auf der Drückflanke hätte den Edge Case „nach zwei Klicks halten = nur ausschalten" (FR-011) unmöglich gemacht — begründet in research.md R-2, Nachtrag
- [X] T015 [US1] In `Sender/ButtonManager.cpp` (`update()`, Loslass-Zweig) die Folge abschließen: kurz gehalten und `multiClickArmed` → `multiClickFlag = true`, kein Klick; sonst Folge verwerfen und den zurückgehaltenen CONFIG-Klick nachliefern (Contract G-4/G-4a)
- [X] T016 [US1] In `Sender/ButtonManager.cpp` `wasMultiClicked()` (one-shot, Flag beim Lesen löschen) und `resetMultiClick()` (verwirft `clickCount`, `lastPressTime` und `multiClickFlag` **beider** Taster) implementieren (Contract G-1)
- [X] T017 [US1] In `Sender/StateMachine.h` die private Hilfsfunktion `static bool isAlarmCapable(State s)` deklarieren und den Klassen-Kopfkommentar (Zeile 10: „OK ≥2s = Alarm") auf die neue Gestenlage umschreiben
- [X] T018 [US1] In `Sender/StateMachine.cpp` `isAlarmCapable()` implementieren (`STATE_SCHIESS_BETRIEB`, `STATE_PFEILE_HOLEN`) und in `setState()` (~Zeile 63) `buttons.resetMultiClick()` aufrufen, außer wenn alter **und** neuer Zustand alarmfähig sind (research.md R-3, FR-011 + FR-012)
- [X] T019 [US1] In `Sender/StateMachine.cpp` `handleSchiessBetrieb()` (~Zeile 383) die Geste `wasHeldFor(Button::OK, ALARM_THRESHOLD_MS)` durch `wasMultiClicked(Button::OK) || wasMultiClicked(Button::CONFIG)` ersetzen; `setState(STATE_ALARM)` + sofortiges `return` beibehalten (Contract P-2/P-5)
- [X] T020 [US1] In `Sender/StateMachine.cpp` `handlePfeileHolen()` (~Zeile 291) dieselbe Alarmprüfung **vor** `pfeileHolenMenu.update()` einfügen, mit `return` nach dem Zustandswechsel (FR-010)
- [X] T021 [US1] In `Sender/Config.h` `ALARM_THRESHOLD_MS` ersatzlos entfernen und den Rollen-Kommentar (~Zeile 59: „Alarm 2s") auf „Alarm = 3× Klick" korrigieren (FR-016)
- [X] T022 [P] [US1] Kommentare in `Sender/SchiessBetriebMenu.h` (Zeile 10) und `Sender/SchiessBetriebMenu.cpp` (Zeile 30) auf die neue Alarm-Geste umschreiben
- [ ] T023 [US1] `pio run -e sender` bauen, flashen und HIL-Testfälle T-20 bis T-33 aus `specs/006-shutdown-alarm-gesten/quickstart.md` abarbeiten — **T-23 (10 von 10 Auslösungen im laufenden Countdown) ist das Gate für research.md R-1**; bei Durchfallen auf die dort dokumentierte GPIO-Interrupt-Variante wechseln

**Checkpoint**: Alarm läuft über den Dreifachklick, die 2-s-Geste ist weg. Halten
tut im Schießbetrieb noch nichts — das liefert US2.

---

## Phase 4: User Story 2 - Gerät jederzeit vorhersagbar ausschalten (Priority: P2)

**Goal**: Halten einer beliebigen Taste ≥ 3 s schaltet aus jedem Zustand ab,
auch aus laufendem Schießbetrieb und Alarm.

**Independent Test**: In allen fünf Zuständen nacheinander jede Taste 3 s halten
→ Gerät schaltet jedes Mal ab (quickstart.md T-01…T-09).

### Implementation for User Story 2

- [X] T024 [US2] In `Sender/StateMachine.cpp` `update()` (~Zeile 53) `checkPowerOffGesture()` **einmal zentral** vor dem `switch` aufrufen (Contract P-1, data-model.md §5)
- [X] T025 [US2] In `Sender/StateMachine.cpp` die Einzelaufrufe von `checkPowerOffGesture()` in `handleSplash()` (~Zeile 169), `handleConfigMenu()` (~Zeile 220), `handlePfeileHolen()` (~Zeile 292) und `handleAlarm()` (~Zeile 546) entfernen (abhängig von T024)
- [X] T026 [US2] In `Sender/StateMachine.cpp` den Kommentar in `checkPowerOffGesture()` (~Zeile 100–105) neu fassen: gilt jetzt in **allen** Zuständen, die Ausnahme „nicht im Schießbetrieb (dort Alarm)" entfällt; Verweis auf FR-002 und research.md R-6 (autonomes Passenende deckt das Abschalten im Schießbetrieb ab)
- [X] T027 [P] [US2] In `Sender/StateMachine.h` die Doxygen-Kommentare zu `checkPowerOffGesture()` (~Zeile 171–180) auf die neue Gültigkeit und den falschen FR-Verweis („FR-015") korrigieren
- [ ] T028 [US2] `pio run -e sender` bauen, flashen und HIL-Testfälle T-01 bis T-09 aus `specs/006-shutdown-alarm-gesten/quickstart.md` abarbeiten — T-04 (Ausschalten im laufenden Countdown, Empfänger führt die Passe autonom zu Ende) und T-07 (kein Selbstabschalten beim Einschalten) sind die kritischen

**Checkpoint**: Beide Gesten sind entkoppelt und in allen Zuständen konsistent

---

## Phase 5: User Story 3 - Längere Pausen ohne Selbstabschaltung (Priority: P3)

**Goal**: Die Inaktivitäts-Abschaltung greift erst nach 60 statt 20 Minuten.

**Independent Test**: Gerät unbedient stehen lassen — nach 59 min noch an, nach
60 min aus (mit `DEBUG_SHORT_TIMES` in Sekunden, quickstart.md T-40…T-44).

### Implementation for User Story 3

- [X] T029 [US3] In `Sender/Config.h` `IDLE_POWER_OFF_MS` im Nicht-DEBUG-Zweig (~Zeile 294) von `20UL * 60 * 1000` auf `60UL * 60 * 1000` ändern; DEBUG-Wert (60 s) unverändert lassen und den Begründungskommentar um den Turnier-Anwendungsfall ergänzen (FR-019, research.md R-5)
- [X] T030 [US3] In `Sender/StateMachine.cpp` verifizieren, dass `checkIdleTimeout()` (~Zeile 112) und seine Aufrufstellen in `handleConfigMenu()` und `handlePfeileHolen()` unverändert bleiben — die Abschaltung darf weiterhin nur in den Wartezuständen greifen, nicht im Schießbetrieb und nicht im Alarm (FR-021)
- [ ] T031 [US3] `pio run -e sender` mit `DEBUG_SHORT_TIMES` bauen, flashen und HIL-Testfälle T-40 bis T-44 aus `specs/006-shutdown-alarm-gesten/quickstart.md` abarbeiten

**Checkpoint**: Alle drei Stories sind einzeln abgenommen

---

## Phase 6: Polish & Cross-Cutting Concerns

- [X] T032 [P] Kopfkommentar von `Sender/ButtonManager.h` (Zeilen 1–26) neu schreiben: Gesten-Übersicht auf „Klick / 3× Klick = Alarm / ≥ 3 s = Aus", Rolle OK ohne 2-s-Schwelle, Hinweis auf den Busy-Callback-Aufrufpfad
- [X] T033 [P] `README.md` aktualisieren: Tastentabelle (Zeilen 41–46) auf die neuen Gesten, Spalte „2 s halten" ersetzen durch „3× schnell klicken"; Abschnitt „Automatische Abschaltung" (Zeile 50) von 20 auf 60 Minuten (FR-023)
- [X] T034 [P] `CLAUDE.md` finalisieren: den Planungsvermerk unter „Recent Changes" auf den umgesetzten Stand umschreiben und den Hinweis „Auto-Abschaltung nach 20 min Inaktivität" im Stromspar-Absatz auf 60 min korrigieren
- [X] T035 [P] In `specs/004-v3-esp32-port/data-model.md` §3 (Zeilen 77–81) einen Hinweis ergänzen, dass die Gesten-Tabelle durch `specs/006-shutdown-alarm-gesten/data-model.md` §3 abgelöst ist
- [ ] T036 Regressionstests T-60 bis T-63 aus `specs/006-shutdown-alarm-gesten/quickstart.md` abarbeiten (kompletter Turnierdurchlauf, Gruppenzyklus, Wartungsmodus/OTA, 30 min Bedienung ohne Fehlalarm)
- [ ] T037 Stromaufnahme im Konfigurationsmenü nachmessen (T-64): muss bei ≤ 0,20 W bleiben — Constitution fordert Neumessung bei Verbrauchsänderungen; Ergebnis in `specs/006-shutdown-alarm-gesten/quickstart.md` eintragen
- [ ] T038 `pio run -e sender-release` bauen und flashen, danach T-20 und T-01 im Feld-Build gegenprüfen (kein Debug-Output, kein CDC)
- [ ] T039 Safety-Review über den Diff von `Sender/ButtonManager.cpp` und `Sender/StateMachine.cpp` durchführen (Constitution „Review-Anforderungen": sicherheitskritische Änderung erfordert zusätzliches Review) — Fokus auf Determinismus der Gestenerkennung und das Abschalten im laufenden Schießbetrieb
- [ ] T040 Checkliste `specs/006-shutdown-alarm-gesten/quickstart.md` vollständig auf ✅ setzen und offene Punkte dokumentieren

---

## Dependencies & Execution Order

### Phase Dependencies

- **Setup (Phase 1)**: keine Abhängigkeiten
- **Foundational (Phase 2)**: nach Setup — **blockiert alle Stories** (ohne den Busy-Callback ist die Alarmfolge nicht zuverlässig messbar)
- **US1 (Phase 3)**: nach Phase 2 — MVP
- **US2 (Phase 4)**: nach Phase 2 technisch möglich, **fachlich aber nach US1**: solange die alte 2-s-Alarm-Geste lebt, würden im Schießbetrieb beim Durchhalten erst der Alarm (2 s) und dann das Abschalten (3 s) feuern
- **US3 (Phase 5)**: nach Phase 2, sonst unabhängig — berührt nur `IDLE_POWER_OFF_MS`
- **Polish (Phase 6)**: nach allen gewünschten Stories

### Within User Story 1

Strikt sequenziell in `Sender/ButtonManager.cpp` (T011 → T016, eine Datei) und
danach `Sender/StateMachine.cpp` (T018 → T020). T021 (Konstante löschen) erst
**nach** T019, sonst bricht der Build. T022 ist reine Kommentararbeit und
parallel möglich.

### Parallel Opportunities

- Phase 2: T005 (`EpaperDisplay.*`) parallel zu T003/T004 (`Config.h`); T006 wartet auf T005
- Phase 3: T022 parallel zu allem anderen
- Phase 4: T027 (`StateMachine.h`) parallel zu T024–T026 (`StateMachine.cpp`)
- Phase 6: T032–T035 sind vier verschiedene Dateien und laufen komplett parallel
- **Nicht parallelisierbar**: alles innerhalb von `Sender/ButtonManager.cpp`, `Sender/StateMachine.cpp` und `Sender/Config.h` — jeweils eine Datei, mehrere Tasks

## Parallel Example: Phase 6

```bash
# Vier Dokumentations-Tasks gleichzeitig (verschiedene Dateien):
Task: "Kopfkommentar Sender/ButtonManager.h neu schreiben"
Task: "README.md Tastentabelle und Abschaltzeit aktualisieren"
Task: "CLAUDE.md Recent Changes finalisieren"
Task: "specs/004-v3-esp32-port/data-model.md §3 als abgelöst markieren"
```

## Implementation Strategy

### MVP First (User Story 1)

1. Phase 1 (Setup) → Phase 2 (Foundational)
2. Phase 3 (US1) vollständig
3. **STOPP und validieren**: T-20…T-33, insbesondere T-23
4. Ab hier ist die sicherheitskritische Funktion bereits besser als vorher: Alarm ist auch in „Pfeile holen" erreichbar und nicht mehr mit dem Ausschalten verwechselbar

### Incremental Delivery

1. Setup + Foundational → Tastenabfrage refreshfest
2. US1 → Alarm entkoppelt → flashen, abnehmen (MVP)
3. US2 → Ausschalten überall → flashen, abnehmen
4. US3 → 60-Minuten-Frist → flashen, abnehmen
5. Polish → Doku, Regression, Strommessung, Safety-Review

### Ein Entwickler, ein Gerät

Parallelarbeit lohnt hier kaum: Es gibt genau einen Sender zum Flashen, und die
drei Kern-Dateien werden von fast allen Tasks angefasst. Die [P]-Marker sind
dokumentativ (verschiedene Dateien) und vor allem für die Doku-Phase relevant.

## Notes

- Gebaut wird **immer** aus dem Repo-Root; unter Windows vor jedem Upload `$env:PYTHONIOENCODING="utf-8"` setzen
- Sender-USB-Flash: BTN1 während des gesamten Uploads gedrückt halten
- `Empfaenger/` wird nicht angefasst und **nicht** neu geflasht
- Keine Pin-, Schaltplan- oder Protokolländerung — `Schaltung-Sender/` bleibt unberührt (research.md R-7)
- Nach jedem Task oder logischen Block committen

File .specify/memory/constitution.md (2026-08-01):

<!--
SYNC IMPACT REPORT
==================
Version Change: 1.1.0 → 2.0.0 → 2.1.0 (2026-06-10) → 2.2.0 (2026-06-11)

2.0.0 — Rationale: Hardware-Generationswechsel V2 → V3 (ESP32 statt Arduino Nano, ESP-NOW
statt NRF24L01, e-Paper statt TFT). Autoritative Hardware-Quelle ist jetzt das KiCad-Projekt
`Schaltung-Sender/` bzw. `Schaltung-Empfaenger/`. MAJOR-Bump wegen grundlegender Neudefinition der
Hardware-Standards-Sektion (Versioning-Richtlinie).

2.1.0 — Rationale: USB-Strombegrenzungs-Regel (Entwicklungsmodus, Prinzip I) entfernt —
in V3 wird der LED-Strip immer aus einer externen Quelle versorgt (5 V oder 12 V per Jumper
im Empfänger), nie aus dem USB-Port des MCU-Boards; die Schutzanforderung ist gegenstandslos.
Entscheidung des Projektverantwortlichen vom 2026-06-10.

2.2.0 — Rationale: Arduino-IDE-Kompatibilitätsanforderung (Prinzip III) entfernt — das
Projekt migriert mit V3 vollständig auf PlatformIO + ESP32; `pio run` ist der einzige
unterstützte und verifizierte Build-Pfad. Die eingefrorene V2 (Arduino Nano) bleibt davon
unberührt. Entscheidung des Projektverantwortlichen vom 2026-06-11.

Changes Made:
- Hardware-Anforderungen vollständig auf V3 umgestellt (ESP32-S3-Sender, XIAO-ESP32C3-Empfänger)
- Betriebsparameter aktualisiert (Initialisierungszeit < 10 s wegen e-Paper + Funktest)
- Pin-Belegungen: autoritative Quelle jetzt `Schaltung-Sender/` bzw. `Schaltung-Empfaenger/` (KiCad);
  eingefrorener Pin-Contract in `specs/004-v3-esp32-port/contracts/hardware-pins.md`
- V2-Hardware (Arduino Nano, NRF24) als eingefrorenes Legacy dokumentiert
- USB-Strombegrenzungs-Bullet aus Prinzip I entfernt (v2.1.0, siehe oben)

Modified Principles:
- I. Sicherheit Zuerst — Entwicklungsmodus-Strombegrenzung entfernt (obsolet durch externe LED-Versorgung)
- III. Embedded-Hardware-Standards — autoritative Schaltplan-Quelle pro Hardware-Generation
- V. Wartbarkeit & Dokumentation — Schaltplan-Pfad auf `Schaltung-Sender/` und `Schaltung-Empfaenger/` aktualisiert

Templates Status:
✅ plan-template.md - Verified alignment
✅ spec-template.md - Verified alignment
✅ tasks-template.md - Verified alignment

Follow-up TODOs: None
-->

# Bogenampel Constitution

## Kernprinzipien

### I. Sicherheit Zuerst (Safety First)

**NON-NEGOTIABLE**: Sicherheit hat absolute Priorität in allen Designentscheidungen.

- Das System MUSS bei Kommunikationsausfall in einen sicheren Zustand übergehen (Fail-Safe-Prinzip); eine gestartete Passe MUSS auf dem Empfänger autonom korrekt zu Ende laufen, ohne dass dafür ein Funkkommando nötig ist
- Alle Zustandsübergänge MÜSSEN vorhersehbar und deterministisch sein
- Rote Ampelphase (Stopp-Signal) MUSS eindeutig erkennbar sein und darf nicht mit anderen Zuständen verwechselbar sein
- Funksignale MÜSSEN validiert werden - keine ungeprüfte Ausführung empfangener Befehle (Magic + Checksumme + Duplikat-Unterdrückung)

**Rationale**: Die Bogenampel ist ein Sicherheitssystem für Bogenschießplätze. Fehlfunktionen könnten zu gefährlichen Situationen führen, wenn Schützen fälschlicherweise annehmen, das Schießen sei erlaubt oder verboten.

### II. Einfachheit & Zuverlässigkeit (Simplicity & Reliability)

Minimale Benutzereingaben, maximale Betriebssicherheit.

- Code MUSS einfach und verständlich sein - keine unnötige Komplexität
- Ein-Knopf-Bedienung für Hauptfunktionen (Start/Stop) MUSS erhalten bleiben
- System MUSS ohne Konfiguration oder Setup sofort betriebsbereit sein (Plug-and-Play, kein Pairing-Menü)
- Hardware-Komponenten MÜSSEN standardisiert und leicht austauschbar sein
- Energieverwaltung MUSS Batterielaufzeit maximieren (Soft-Power-Latch, vollständiges Abschalten)

**Rationale**: Das Bedienkonzept basiert auf "möglichst einfach, mit minimalen Benutzereingaben". Komplexität erhöht Fehlerrisiko und senkt Benutzerakzeptanz.

### III. Embedded-Hardware-Standards (Embedded Hardware Standards)

Arduino-Platform und etablierte Standards nutzen.

- Code MUSS mit PlatformIO baubar sein (`pio run` pro Firmware-Ordner = verifizierter
  Build-Pfad); Arduino-IDE-Kompatibilität ist seit v2.2.0 (2026-06-11) KEINE Anforderung
  mehr — V3 ist vollständig auf PlatformIO migriert (V2-Legacy bleibt Arduino-IDE-basiert)
- Verwendete Bibliotheken MÜSSEN stabil, wartbar und Open Source sein
- Pin-Belegungen MÜSSEN dokumentiert und im Code als Konstanten definiert sein
- **Pin-Belegungen MÜSSEN exakt mit dem KiCad-Schaltplan der jeweiligen Hardware-Generation übereinstimmen (NON-NEGOTIABLE)**: V3-Firmware (`Sender/`, `Empfaenger/`) gegen `Schaltung-Sender/` bzw. `Schaltung-Empfaenger/`; die V2-Firmware wurde am 2026-08-01 samt Schaltplan entfernt und ist nur noch in der Git-Historie
- Hardware-Schnittstellen MÜSSEN gegen Fehlbeschaltung geschützt sein (Pull-up/Pull-down Widerstände)
- Analoge Eingänge MÜSSEN auf ADC1-Pins liegen (ESP32: ADC2 ist bei aktivem Funk unbrauchbar)
- Stromversorgung MUSS innerhalb spezifizierter Grenzen bleiben (USB: 0,5-3A, Powerbank/Netzteil: bis 12A)

**Rationale**: Standardisierung erleichtert Wartung, Reparatur und Weiterentwicklung. Arduino-Ökosystem bietet bewährte Komponenten und Community-Support. Der KiCad-Schaltplan ist die Single Source of Truth für alle Hardware-Verbindungen.

### IV. Testbarkeit & Validierung (Testability & Validation)

Alle Funktionen MÜSSEN testbar und validierbar sein.

- Jede Timer-Phase MUSS einzeln testbar sein (Stopp, Vorbereitung, Aktiv, Abgelaufen)
- Funkübertragung MUSS unter realistischen Bedingungen getestet werden (Reichweite, Interferenzen)
- Akustische und visuelle Signale MÜSSEN auf Korrektheit geprüft werden (Frequenzen, Farben, Timing)
- Grenzfälle MÜSSEN definierte erwartete Verhaltensweisen haben und getestet werden
- Stromverbrauch MUSS gemessen und gegen Spezifikationen validiert werden

**Rationale**: Embedded Systems sind schwer zu debuggen im Feld. Umfassende Tests vor Deployment sind kritisch für Zuverlässigkeit.

### V. Wartbarkeit & Dokumentation (Maintainability & Documentation)

Code und Hardware MÜSSEN vollständig dokumentiert sein.

- Alle Pin-Belegungen MÜSSEN im Code und in Hardware-Dokumentation übereinstimmen
- **Änderungen an Pin-Belegungen MÜSSEN zuerst im KiCad-Schaltplan (V3: `Schaltung-Sender/` bzw. `Schaltung-Empfaenger/`) vorgenommen werden, bevor Code angepasst wird**
- Funktionen MÜSSEN klare, selbsterklärende Namen haben
- Zustandsübergänge MÜSSEN mit Kommentaren erklärt sein
- Hardware-Komponenten MÜSSEN mit Teilenummern und Spezifikationen dokumentiert sein
- Schaltpläne und Verkabelungsdiagramme MÜSSEN aktuell gehalten werden
- Code-Kommentare MÜSSEN auf entsprechende Connector-Bezeichner im Schaltplan verweisen (z.B. J1, J8, RV1)

**Rationale**: Das System muss von anderen gewartet werden können. Fehlende Dokumentation führt zu Ausfallzeiten und Fehlern bei Reparaturen. Der KiCad-Schaltplan ist die autoritative Quelle für Hardware-Designs.

## Hardware-Anforderungen

### Komponenten-Spezifikationen (V3, aktuell)

- **Sender (Bedieneinheit)**: ESP32-S3-WROOM-1U-N16R8 (16 MB Flash, 8 MB Octal-PSRAM); 1.54″ e-Paper 200×200 monochrom (SSD1681, Waveshare-1.54-V2-Rohpanel); LiPo-Akku 3,0–4,2 V mit MCP73837-Lader und USB-C; Ein-Knopf-Soft-Power (Power-Latch)
- **Empfänger (Anzeigeeinheit)**: Seeed XIAO ESP32C3; WS2812B LED-Strip (158 LEDs: 2× Gruppenanzeige + 3× 7-Segment); Piezo-Transducer 12 V über Transistorstufe mit Lautstärke-Poti; Gehäuselüfter mit Tacho; Helligkeits-Poti
- **Funk**: integriertes 2,4-GHz-Funkmodul der ESP32-Chips via ESP-NOW — KEIN externes Funkmodul
- **Stromversorgung Sender**: LiPo-Akku, Laden über USB-C
- **Stromversorgung Empfänger**: extern 12 V oder USB 5 V (keine Akku-Verwaltung)

### Legacy-Hardware (V2, eingefroren)

Die V2-Firmware (`Sender/`, `Empfaenger/`) und ihre Hardware (Arduino Nano ATmega328P,
nRF24L01+, ST7789-TFT) bleiben unverändert im Repository und werden nicht
weiterentwickelt. Die zugehörigen KiCad-Dateien (`Schaltung/`) wurden am 2026-08-01
entfernt; als autoritative V2-Quelle gilt ihr letzter Stand in der Git-Historie.

### Betriebsparameter

- **Funkreichweite**: mindestens 30 m Freifeld (volle Schießplatz-Distanz); Startup-Qualitätstest ≥ 90 %
- **Timer-Genauigkeit**: ±1 Sekunde über 240 Sekunden
- **LED-Helligkeit**: 25–100 % über Helligkeits-Poti (LED-Versorgung immer extern: 5 V oder 12 V je nach Jumper im Empfänger — keine USB-Schutzbegrenzung nötig)
- **Batterielaufzeit Sender**: mindestens 8 Stunden bei normaler Nutzung; im Aus-Zustand nur Hardware-Leckströme (Latch vollständig gelöst)
- **Initialisierungszeit Sender**: unter 10 Sekunden vom Einschalten bis zum bedienbaren Konfigurationsmenü (e-Paper-Voll-Refresh + Funk-Qualitätstest eingerechnet)

### Pin-Belegungen

**AUTORITATIVE QUELLE**: KiCad-Projekt `Schaltung-Sender/` bzw. `Schaltung-Empfaenger/`
(Sender: `BogenampelV3.kicad_sch`, Empfänger: `Zusatzplatine-Empfänger.kicad_sch`)

**Alle Pin-Zuweisungen im Code MÜSSEN exakt mit dem Schaltplan übereinstimmen.**
Der aus den KiCad-Netzlisten eingefrorene, verbindliche Pin-Contract liegt in
`specs/004-v3-esp32-port/contracts/hardware-pins.md` (inkl. Connector-Referenzen und
dokumentierter Hardware-Reworks: Helligkeits-Poti D5→D1, BTN1-Teiler R7 47k→240k).

#### Sender (ESP32-S3, GPIO-Nummern)

- **e-Paper**: BUSY=38, RES=48, DC=47, CS=21, CLK=14, MOSI=13
- **Power**: LATCH=16 (HIGH = an halten), Display-Rail LOAD=7
- **Akku/Lader**: ADC_BAT=10 (Teiler 150k/100k, ×2,5), USB_CON=8, C_ST1=11, C_ST2=12, C_PG=17, C_PRG=18
- **Taster**: BTN1 (Power/OK)=15 (aktiv HIGH), BTN2 (Weiter)=9 (INPUT_PULLUP, aktiv LOW)
- **Reserviert**: GPIO 35–37 (Octal-PSRAM des Moduls)

#### Empfänger (XIAO ESP32C3, D-Nummern)

- **WS2812B-Daten**: D10
- **Taster (Debug)**: D7; **Status-LED**: D9
- **Piezo (PWM)**: D2; **Lautstärke-Poti**: D0 (ADC1); **Helligkeits-Poti**: D1 (ADC1, nach Rework von D5)
- **Lüfter**: PWM=D6, Tacho=D8

## Entwicklungs-Workflow

### Code-Standards

- Alle Zustandsvariablen MÜSSEN volatile deklariert sein, wenn in Interrupts/Timer-Callbacks verwendet
- Magic Numbers MÜSSEN durch benannte Konstanten ersetzt werden
- Globale Variablen MÜSSEN minimiert und klar dokumentiert sein
- Timer-Interrupts/esp_timer-Callbacks MÜSSEN korrekt konfiguriert und dokumentiert sein

### Test-Workflow

1. **Unit-Tests**: Logik-Funktionen isoliert testen (State-Machine-Übergänge)
2. **Hardware-in-the-Loop**: Testen mit echter Hardware in Labor-Umgebung
3. **Reichweitentests**: Funkübertragung unter realistischen Bedingungen
4. **Langzeittests**: Batterielaufzeit und Stabilitätstests (mindestens 8 Stunden)
5. **Feldtests**: Finale Validierung unter echten Einsatzbedingungen

### Review-Anforderungen

- Code-Reviews MÜSSEN Pin-Belegungen gegen den KiCad-Schaltplan der jeweiligen Hardware-Generation prüfen (V3: `Schaltung-Sender/` bzw. `Schaltung-Empfaenger/`)
- Code-Kommentare MÜSSEN Connector-Bezeichner aus dem Schaltplan referenzieren (z.B. "// J9: WS2812B Stripe Timer")
- Alle Änderungen an Zustandsmaschine MÜSSEN State-Diagramm-Updates beinhalten
- Stromverbrauchsänderungen MÜSSEN neu gemessen werden
- Safety-kritische Änderungen erfordern zusätzliches Review
- Hardware-Änderungen MÜSSEN zuerst im KiCad-Schaltplan dokumentiert werden, bevor Code geändert wird

## Governance

### Amendment-Prozess

Änderungen an dieser Verfassung erfordern:
1. Dokumentation der vorgeschlagenen Änderung mit Begründung
2. Review und Zustimmung des Projektverantwortlichen
3. Aktualisierung aller abhängigen Templates und Dokumentation
4. Versions-Bump nach Semantic Versioning

### Versioning-Richtlinien

- **MAJOR**: Entfernung oder grundlegende Neudefinition von Prinzipien
- **MINOR**: Neue Prinzipien oder wesentliche Erweiterungen
- **PATCH**: Klarstellungen, Formulierungsverbesserungen, Korrekturen

### Compliance

- Alle Spezifikationen MÜSSEN gegen diese Prinzipien geprüft werden
- Alle Implementierungspläne MÜSSEN Sicherheitsaspekte adressieren
- Alle Code-Reviews MÜSSEN Einfachheit und Wartbarkeit bewerten
- Hardware-Änderungen MÜSSEN gegen Komponentenstandards validiert werden

### Laufzeit-Entwicklungsleitfaden

Für detaillierte Implementierungsrichtlinien siehe:
- **README.md**: Projektübersicht und Funktionsbeschreibung
- **Schaltung-Sender/**, **Schaltung-Empfaenger/**: Autoritative Hardware-Pin-Belegungen V3 (KiCad)
- **specs/004-v3-esp32-port/contracts/hardware-pins.md**: Eingefrorener Pin-Contract V3
- **Schaltung/** (entfernt 2026-08-01): KiCad-Projekt der eingefrorenen V2-Hardware — nur noch in der Git-Historie

**Version**: 2.2.0 | **Ratifiziert**: 2025-12-04 | **Zuletzt geändert**: 2026-06-11

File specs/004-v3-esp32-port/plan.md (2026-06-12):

# Implementation Plan: Bogenampel V3 Hardware Port (ESP32 + e-Paper + ESP-NOW)

**Branch**: `004-v3-esp32-port` | **Date**: 2026-06-09 | **Spec**: [spec.md](spec.md)
**Input**: Feature specification from `/specs/004-v3-esp32-port/spec.md`

## Summary

Port the functionally complete V2 firmware to the V3 hardware: the sender moves from Arduino
Nano + ST7789 TFT + NRF24 to an ESP32-S3 with a 1.54″ e-paper panel, LiPo charging and one-button
soft power; the receiver moves from Arduino Nano + NRF24 to a XIAO ESP32C3 driving the unchanged
158-LED display, with new volume and fan control. The radio transport is replaced by ESP-NOW
(built-in 2.4 GHz) while keeping the 11-command protocol semantics. The tournament logic
(WA timer 120/240 s, group cycle, half-end, alarm, autonomous passe end on the receiver —
FR-004/FR-004a) is ported 1:1 from the V2 code base into two new firmware trees `SenderV3/` and
`EmpfaengerV3/`, built with PlatformIO (sole build path since 2026-06-11 — full PlatformIO
migration, constitution v2.2.0).

## Technical Context

**Language/Version**: C++ (Arduino core for ESP32 / arduino-esp32 3.x, C++17; V2 logic is C++11 and ports without changes)
**Primary Dependencies**:
- Sender: GxEPD2 (+ Adafruit GFX) for the SSD1681 e-paper, `esp_now` + `WiFi` (core), `Preferences` (core, NVS)
- Receiver: FastLED (WS2812B via RMT), `esp_now` + `WiFi` (core), LEDC (core, piezo PWM)
**Storage**: ESP32 NVS via `Preferences` (replaces AVR EEPROM), namespace `bogenampel`
**Testing**: PlatformIO build verification (`pio run`) for both firmwares; hardware-in-the-loop checklist (quickstart.md); pure tournament logic kept in hardware-free classes to allow optional native tests later
**Target Platform**: Sender = ESP32-S3-WROOM-1U-N16R8 (16 MB flash, 8 MB octal PSRAM → GPIO 35–37 reserved); Receiver = Seeed XIAO ESP32C3 (4 MB flash)
**Project Type**: Embedded, two independent firmware projects sharing one protocol header
**Performance Goals**: command delivery confirmed < 500 ms incl. retries; countdown accuracy ±1 s / 240 s; e-paper partial refresh < 400 ms at 1 Hz; sender boot-to-menu < 10 s
**Constraints**: e-paper refresh budget (full ~2 s only on screen changes); power latch must be asserted in the first milliseconds of `setup()`; ESP32 ADC2 unusable while the radio is active → all analog inputs must be on ADC1 (drives the D5→D1 poti rework and forbids analog reading of BTN1 on GPIO15); BTN1 input level is marginal by schematic (see research.md R-13, hardware fix recommended)
**Scale/Scope**: ~3.7 kLOC V2 firmware to port + new platform layer (~1.5 kLOC new/changed); 2 boards; 11 radio commands; 5 sender screens
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

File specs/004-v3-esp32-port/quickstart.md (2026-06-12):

# Quickstart: Bogenampel V3 bauen, flashen, testen

**Feature**: 004-v3-esp32-port

## Voraussetzungen

- **Hardware-Rework vor dem ersten Test** (siehe `contracts/hardware-pins.md`):
  1. Empfänger: Helligkeits-Poti von D5 auf **D1** umverdrahten (Lochraster).
  2. Sender: **R7 mit 240k bestücken** (R2 bleibt 47k; BTN1-Pegel — Schaltplan seit
     2026-06-10 korrigiert und per Netzliste verifiziert).
  3. Empfänger: Piezo auf **D3**, Lüfter-Poti an **D2**, Status-LED **aktiv LOW**, Tacho
     unbeschaltet, Lautstärke-Poti-Fußpunkt an **D4** — Schaltplan und Lochraster erledigt
     (verifiziert/bestätigt 2026-06-10).
  4. Hinweis: Lüfter läuft beim Boot/Flashen voll (Gate-Pull-up R5, Befund 6 in
     `contracts/hardware-pins.md`).
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

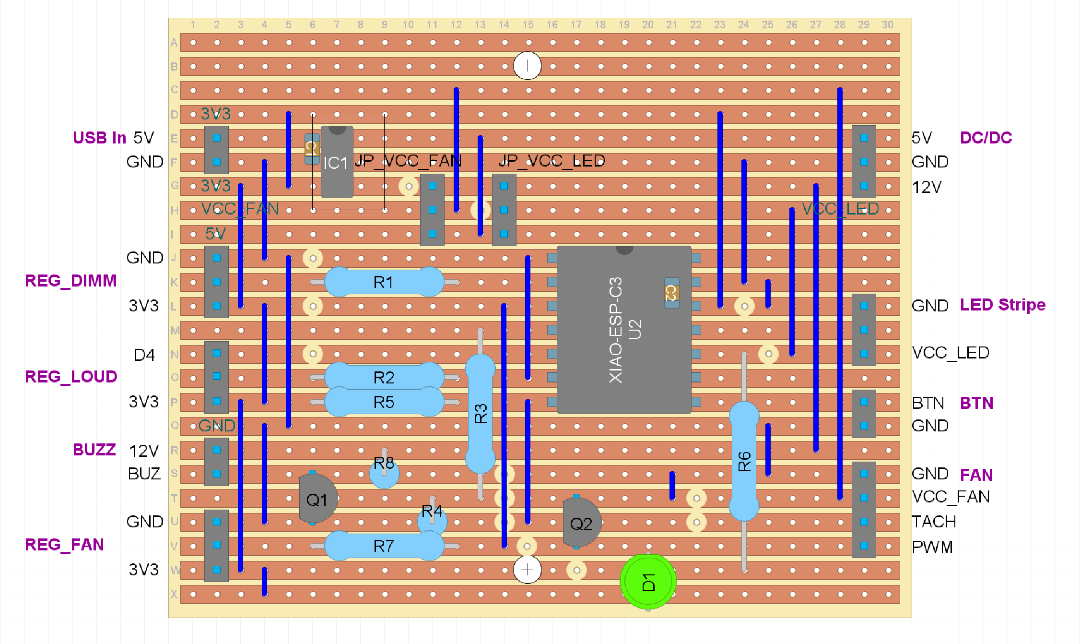
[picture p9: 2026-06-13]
Schaltung-Empfaenger/Lochraster.png

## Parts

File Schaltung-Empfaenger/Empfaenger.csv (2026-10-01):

Reference | Qty | Value | DNP | Exclude from BOM | Exclude from Board | Footprint | Datasheet
C1,C4,C6,C7 | 4 | 10µF |  |  |  | Capacitor_SMD:C_1206_3216Metric
C2,C3,C5,C9,C10 | 5 | 100nF |  |  |  | Capacitor_SMD:C_1206_3216Metric
C8 | 1 | 47µF |  |  |  | Capacitor_THT:CP_Radial_D8.0mm_P3.50mm
C11 | 1 | 1µF |  |  |  | Capacitor_SMD:C_1206_3216Metric
D1,D3 | 2 | LED |  |  |  | LED_THT:LED_D5.0mm
D2 | 1 | SMBJ13A |  |  |  | Diode_SMD:D_SMB
J1 | 1 | Conn_01x06 USB |  |  |  | Connector_JST:JST_XH_B6B-XH-AM_1x06_P2.50mm_Vertical
J2,J3,J4 | 3 | Poti 47k |  |  |  | Connector_JST:JST_XH_B3B-XH-AM_1x03_P2.50mm_Vertical
J5 | 1 | BTN |  |  |  | Connector_JST:JST_XH_B2B-XH-AM_1x02_P2.50mm_Vertical
J6 | 1 | Fan |  |  |  | Connector_JST:JST_XH_B4B-XH-AM_1x04_P2.50mm_Vertical
J7 | 1 | LED Stripe |  |  |  | Connector_JST:JST_XH_B3B-XH-AM_1x03_P2.50mm_Vertical
J8 | 1 | Piezo Transducter 12V |  |  |  | Connector_JST:JST_XH_B2B-XH-AM_1x02_P2.50mm_Vertical
Q1 | 1 | IRLML9301 |  |  |  | Package_TO_SOT_SMD:SOT-23 | https://www.infineon.com/dgdl/irlml9301pbf.pdf?fileId=5546d462533600a401535668e5e42640
Q2 | 1 | 2N7002 |  |  |  | Package_TO_SOT_SMD:SOT-23 | https://diotec.com/request/datasheet/2n7002.pdf
Q3 | 1 | BC337 |  |  |  | Package_TO_SOT_THT:TO-92_Inline | https://diotec.com/tl_files/diotec/files/pdf/datasheets/bc337.pdf
R1 | 1 | 1k |  |  |  | Resistor_SMD:R_1206_3216Metric
R2,R7,R11,R12,R13 | 5 | 10k |  |  |  | Resistor_SMD:R_0603_1608Metric
R3,R4,R5 | 3 | 1k |  |  |  | Resistor_SMD:R_0603_1608Metric
R6 | 1 | 470 |  |  |  | Resistor_SMD:R_0603_1608Metric
R8 | 1 | 20k |  |  |  | Resistor_SMD:R_0603_1608Metric
R9 | 1 | 220 |  |  |  | Resistor_SMD:R_0603_1608Metric
R10,R15 | 2 | 2k2 |  |  |  | Resistor_SMD:R_0603_1608Metric
R14 | 1 | 330 |  |  |  | Resistor_SMD:R_0603_1608Metric
TP1 | 1 | +3V3 |  |  |  | TestPoint:TestPoint_Pad_D1.5mm
TP2 | 1 | VPD |  |  |  | TestPoint:TestPoint_Pad_D1.5mm
TP3 | 1 | +5V |  |  |  | TestPoint:TestPoint_Pad_D1.5mm
U1 | 1 | L7805 |  |  |  | Package_TO_SOT_THT:TO-220-3_Vertical | http://www.st.com/content/ccc/resource/technical/document/datasheet/41/4f/b3/b0/12/d4/47/88/CD00000444.pdf/files/CD00000444.pdf/jcr:content/translations/en.CD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
U2 | 1 | CH224K |  |  |  | Package_SO:SSOP-10-1EP_3.9x4.9mm_P1mm_EP2.1x3.3mm | https://www.wch.cn/downloads/file/301.html
U3 | 1 | XIAO ESP32C3 |  |  |  | 0liver:xiao_esp32c3 | https://files.seeedstudio.com/wiki/Seeed-Studio-XIAO-ESP32/esp32-c3_datasheet.pdf
U4 | 1 | TSR0.5-2433 |  |  |  | Converter_DCDC:Converter_DCDC_TRACO_TSR0.5-24xx_TSR0.5-24xxx_THT | https://www.tracopower.com/products/tsr0.5.pdf
U5 | 1 | 74AHCT1G125 |  |  |  | Package_TO_SOT_SMD:SOT-353_SC-70-5 | http://www.ti.com/lit/sg/scyt129e/scyt129e.pdf

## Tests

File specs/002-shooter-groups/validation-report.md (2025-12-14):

# Validierungs-Bericht: Schützengruppen-Anzeige (Feature 002)

**Datum**: 2025-12-04
**Status**: ⚠️ **BEDINGT BESTANDEN**
**Reviewer**: Automatische Spezifikations-Validierung

## Übersicht

Die Spezifikation für Feature 002 (Schützengruppen-Anzeige) ist **gut strukturiert und größtenteils vollständig**, hat aber **4 kritische Grenzfälle**, die als funktionale Anforderungen formalisiert werden müssen, bevor die Implementation beginnen kann.

## Validierungs-Ergebnisse

### ✅ Bestanden (9/12 Kategorien)

1. **Benutzer-fokussiert**: Alle User Stories beschreiben WAS, nicht WIE
2. **Testbare Akzeptanzkriterien**: 15 Szenarien im Gegeben-Wenn-Dann Format
3. **Messbare Erfolgskriterien**: 8 quantifizierbare Metriken (SC-001 bis SC-008)
4. **Prioritäten**: Logische P1/P2/P3 Zuweisung mit Begründungen
5. **Unabhängige Testbarkeit**: Alle 4 User Stories isoliert testbar
6. **Inkrementeller Wert**: Jede Story liefert sofort Mehrwert
7. **Schlüssel-Entitäten**: 4 Entitäten klar definiert
8. **Technische Machbarkeit**: 5 Annahmen validiert gegen Feature 001
9. **Regelkonformität**: Bogensport-Rhythmus korrekt dokumentiert

### ⚠️ Verbesserungsbedarf (3/12 Kategorien)

#### 1. Funktionale Anforderungen (Blocker)

**Problem**: Die Spezifikation hat 4 Grenzfall-Fragen ohne klare Antworten:

| Grenzfall | Aktuelle Situation | Fehlende FR | Impact |
|---|---|---|---|
| **GF-1**: Manueller Wechsel + Timer-Start | Annahme #5: "setzt NICHT zurück" | FR-013 fehlt | **HOCH** - Betrifft Rhythmus-Logik |
| **GF-2**: Power-Cycle mitten in Passe 3 | FR-009 sagt "Passe 1, A/B" | FR-009 unklar formuliert | **MITTEL** - Betrifft Neustart-Verhalten |
| **GF-3**: Manueller STOP → Gruppe wechselt? | FR-006 sagt "bei Ablauf" | FR-006 nicht explizit | **HOCH** - Betrifft State-Transitions |
| **GF-4**: Passen-Zähler bei manuellem Stopp | Nicht spezifiziert | FR-008 fehlt Details | **HOCH** - Betrifft Rhythmus-Synchronisation |

**Empfohlene Lösung**:

```markdown
### Neue/Erweiterte Anforderungen

- **FR-006** (erweitert): System MUSS automatisch die Gruppenanzeige wechseln, wenn ein Timer **durch Ablauf** (Countdown = 0) endet. Bei manuellem STOP-Befehl DARF die Gruppe NICHT wechseln.

- **FR-008** (erweitert): System MUSS einen internen Passen-Zähler führen, um den Rhythmus zu bestimmen. Der Zähler inkrementiert NUR wenn ein Timer vollständig abläuft (nicht bei manuellem STOP).

- **FR-009** (erweitert): System MUSS bei JEDEM Power-On (unabhängig von vorherigem Zustand) mit Passe 1, Gruppe A/B beginnen. Kein persistenter Zustand wird gespeichert.

- **FR-013** (NEU): Manueller Gruppenwechsel (Taster-Betätigung) DARF den automatischen Passen-Zähler NICHT zurücksetzen. Der Rhythmus läuft intern weiter, auch wenn Anzeige manuell geändert wurde.
```

#### 2. LED-Spezifikation (Nice-to-have)

**Problem**: Keine konkrete Angabe über LED-Anzahl pro Feld (A/B, C/D).

**Empfohlene Lösung**:

```markdown
### Annahme 6 (NEU): LED-Feld-Größe

- Jedes Feld (A/B und C/D) besteht aus mindestens 20 WS2812B LEDs, angeordnet als Buchstaben
- Gesamtzusatz: ~40 LEDs (20 pro Feld)
- Rationale: 20 LEDs pro Feld ermöglichen 20+ Meter Lesbarkeit bei Tageslicht
```

#### 3. Strombudget (Nice-to-have)

**Problem**: Zusätzliche LEDs erhöhen Stromverbrauch, keine Validierung gegen Powerbank.

**Empfohlene Lösung**:

```markdown
### Annahme 7 (NEU): Strombudget

- Timer-Anzeige: ~155 LEDs (bestehend)
- Gruppenfelder: ~40 LEDs (neu)
- **Gesamt: ~195 LEDs**
- Worst-Case: 195 × 60mA = **11.7A** (alle LEDs weiß, 100% Helligkeit)
- Powerbank muss mindestens 12A liefern können (siehe Feature 001, bereits spezifiziert)
- Development-Mode (3% Helligkeit) reduziert auf ~350mA (USB-sicher)
```

## Risiken & Blocker

### 🔴 Kritisch (MUSS vor Implementation gelöst werden)

1. **Grenzfall-Verhalten nicht spezifiziert**: Die 4 Grenzfälle (GF-1 bis GF-4) können zu **widersprüchlichem Verhalten** führen, wenn nicht geklärt:
   - Entwickler könnte annehmen, dass manueller STOP die Gruppe wechselt (wie automatischer Ablauf)
   - Passen-Zähler könnte falsch inkrementieren bei manuellen Eingriffen
   - Rhythmus könnte desynchronisiert werden durch manuelle Wechsel

   **Lösungsweg**: Entweder `/speckit.clarify` ausführen ODER die 4 empfohlenen FRs manuell hinzufügen.

### 🟡 Moderat (Sollte vor Implementation geklärt werden)

2. **LED-Count unbekannt**: Ohne konkrete LED-Anzahl kann Hardware-Design nicht finalisiert werden.
   - **Impact**: Bestückungsliste für PCB kann nicht erstellt werden
   - **Lösungsweg**: Annahme 6 hinzufügen (20 LEDs pro Feld)

3. **Keine Integration-Diagramme**: Unklar, wie Gruppenwechsel in bestehende State-Machine integriert wird.
   - **Impact**: Architektur-Entscheidungen verzögert
   - **Lösungsweg**: In Plan-Phase (data-model.md) klären

## Empfohlene Nächste Schritte

### Option 1: Automatische Klärung (Empfohlen)

```bash
/speckit.clarify
```

**Vorteil**: Interaktiver Prozess stellt bis zu 5 gezielte Fragen zu den Grenzfällen.

**Ergebnis**: Aktualisierte spec.md mit FRs für alle 4 Grenzfälle.

### Option 2: Manuelle Korrektur

1. Öffne `/mnt/d/git/Bogenampel/specs/002-shooter-groups/spec.md`
2. Füge FR-013 hinzu
3. Erweitere FR-006, FR-008, FR-009 wie oben beschrieben
4. Füge Annahmen 6 und 7 hinzu
5. Entferne die 4 Grenzfall-Fragen (jetzt als FRs gelöst)

**Vorteil**: Volle Kontrolle über Formulierungen.

**Nachteil**: Manuelle Arbeit, keine Validierung.

## Qualitäts-Score

| Kategorie | Score | Notizen |
|---|---|---|
| Inhaltsqualität | ✅ 100% | Benutzer-fokussiert, testbar, messbar |
| Anforderungsvollständigkeit | ⚠️ 67% | 4 Grenzfälle fehlen als FRs |
| Feature-Bereitschaft | ✅ 100% | Prioritäten, Testbarkeit, Wert klar |
| Annahmen-Validierung | ⚠️ 71% | 5/7 Annahmen vorhanden |
| **GESAMT** | ⚠️ **84%** | **GUT, aber 4 Blocker** |

## Fazit

Die Spezifikation ist **fast bereit für Implementation**. Die Struktur, Prioritäten und Akzeptanzkriterien sind **exzellent**. Die 4 fehlenden funktionalen Anforderungen (FR-006/FR-008/FR-009 erweitern, FR-013 hinzufügen) sind der **einzige Blocker**.

**Empfehlung**: Führe `/speckit.clarify` aus, um die Grenzfälle interaktiv zu klären. Dies sollte **<10 Minuten** dauern und die Spezifikation auf **100% Bereitschaft** bringen.

---

**Erstellt**: 2025-12-04 | **Tool**: Automatic Spec Validation | **Version**: 1.0

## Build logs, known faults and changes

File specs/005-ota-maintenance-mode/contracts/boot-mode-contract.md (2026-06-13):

# Contract: Boot-Mode Decision & Per-Mode Initialization

Defines the observable obligations of the receiver's startup. "MUST"/"MUST NOT" are testable at the
hardware boundary (radio scans, access-point presence, LED, OTA reachability).

## C1 — Boot decision (FR-001, FR-007, SC-001)

- The receiver MUST evaluate the debug button (D7 / J5, `INPUT_PULLUP`, active-low) exactly once,
  early in `setup()`, after the strapping-pin safety steps (`POTI_GND` LOW, `fan.begin()`) and
  **before** any radio initialization or the boot rainbow effect.
- The read MUST be debounced (stable `LOW` across multiple samples over ~20–30 ms) so a single noisy
  sample cannot flip the decision.
- Result: `bootOtaMode = true` if held, else `false`. The value MUST NOT change for the rest of the
  power cycle, regardless of later button activity.

## C2 — NORMAL path (button not held) (FR-005, FR-006)

When `bootOtaMode == false`, the receiver MUST:

- Initialize ESP-NOW via `radio.begin()` on the fixed channel (channel 1), exactly as before this
  feature.
- Run the existing boot sequence (rainbow effect, timer/display, buzzer, potis, fan, status-LED
  normal behavior, 1 Hz tick) unchanged.

When `bootOtaMode == false`, the receiver MUST NOT:

- Call `WiFi.begin()` or otherwise attempt to join any WiFi network.
- Start any SoftAP / access point (none may be observable in a WiFi scan).
- Start ArduinoOTA.

Observable acceptance: a normal boot shows **no** `Bogenampel-Empfaenger` access point and makes no
association with the home router; the sender↔receiver ESP-NOW link establishes with the prior
reliability (SC-003, SC-006).

## C3 — OTA path (button held) (FR-002, FR-003, FR-009, FR-012)

When `bootOtaMode == true`, the receiver MUST:

- **Not** call `radio.begin()` and **not** start ESP-NOW, the timer, the rainbow effect, the buzzer,
  or the poti loops.
- Set the radio to `WIFI_STA` (station only — no access point) and join the configured home network
  using the compile-time credentials, with auto-reconnect and indefinite retry (no SoftAP fallback).
- Start ArduinoOTA with the configured hostname. No network OTA password is set — access is gated by
  the physical button-at-boot requirement instead (FR-012).
- Drive the status LED via the OTA LED contract (see `ota-led-signal-contract.md`).
- Remain in this mode until reset/power-cycle even if WiFi never connects (keep retrying + keep
  blinking) — it MUST NOT fall through to NORMAL/ESP-NOW.

Observable acceptance: with the button held at power-on, within 20 s under normal network conditions
the device answers the ArduinoOTA UDP handshake at its assigned IP (SC-002); a full flash succeeds
and the device reboots (US1).

## C4 — Mutual exclusion (FR-006)

At no point in a single power cycle may both ESP-NOW (channel 1) and a WiFi-STA association
(router channel) be active. The mode chosen at C1 selects exactly one radio role for the whole power
cycle.

## C5 — Post-update (FR-008, FR-010)

- A successful OTA ends with an automatic restart; the next boot re-runs C1 (so, button released →
  NORMAL).
- An interrupted/failed transfer MUST leave the previously running firmware intact and bootable; the
  device stays in OTA maintenance mode (does not brick, does not silently switch modes).

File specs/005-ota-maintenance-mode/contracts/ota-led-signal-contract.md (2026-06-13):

# Contract: OTA-Mode Status-LED Signalling

Applies only when `BootMode = OTA_MAINTENANCE`. Hardware: status LED on **D9 / GPIO9, active-low**
(`STATUS_LED_ON = LOW`, `STATUS_LED_OFF = HIGH`; 3V3 → LED → R6 → pin, Strapping-Fix Befund 3).
All patterns MUST be produced **non-blocking** (driven from `millis()` each loop), so
`ArduinoOTA.handle()` is never starved — FR-004c runs *during* the transfer.

## Patterns (FR-004a / FR-004b / FR-004c)

| Phase | Period | LED behavior within a period | Drives from |
|---|---|---|---|
| `CONNECTING` (FR-004a) | 600 ms | ON ~100 ms, then OFF ~500 ms (fast short flash) | `WiFi.status() != WL_CONNECTED` or `WiFi.localIP()` is `0.0.0.0` |
| `READY` (FR-004b) | 1000 ms | ON ~500 ms, OFF ~500 ms (slow, even) | connected + valid IP, no transfer in progress |
| `UPDATING` (FR-004c) | 600 ms | ON ~500 ms, then OFF ~100 ms (mostly lit, brief dark blip) | ArduinoOTA `onStart` … `onEnd` |

Timings are targets with ±~50 ms tolerance (Spec Assumptions). The three patterns MUST stay mutually
distinguishable by eye and MUST NOT match the normal-mode indications (steady-on "ready" or the
event-driven receive-blink) — FR-011.

## Phase source of truth

- Phase is recomputed each loop: default to `CONNECTING`; promote to `READY` when
  `WiFi.status() == WL_CONNECTED && WiFi.localIP() != INADDR_NONE`; force `UPDATING` between the
  ArduinoOTA `onStart` and `onEnd`/`onError` callbacks (a boolean set in those callbacks overrides
  the WiFi-derived phase).
- On `onError`, clear the updating flag → the next loop falls back to `READY` or `CONNECTING`
  depending on the live WiFi state (FR-010, stays in maintenance mode).

## Acceptance (maps to SC-004, US3)

1. Power on with button held, WiFi briefly unavailable → LED shows the **fast short flash**.
2. WiFi connects and an IP is assigned → LED switches to the **slow even blink**.
3. Start a flash from the workstation → LED switches to **mostly-lit with brief blips** until the
   transfer finishes (then the device reboots).
4. In NORMAL mode none of these three patterns ever appears.

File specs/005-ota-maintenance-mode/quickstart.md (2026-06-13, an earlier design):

# Quickstart: Receiver OTA Maintenance Mode

## Operator: how to update a deployed receiver

1. Power the receiver **off**.
2. **Hold the debug button** (J5) and apply power; keep holding until the status LED starts the
   **fast short flash** (~100 ms on / 500 ms off). You may release the button now — the mode is
   latched for this power cycle.
3. Wait for the LED to change to the **slow even blink** (~500 ms on / 500 ms off) — the receiver is
   now on the home WiFi with an IP and ready to be flashed.
4. From the workstation, push the firmware:
   ```bash
   # Windows: force UTF-8 so esptool/espota output does not crash the console
   #   PowerShell:  $env:PYTHONIOENCODING="utf-8"; $env:PYTHONUTF8="1"
   pio run -e empfaenger-ota -t upload
   ```
   During the transfer the LED goes **mostly lit with a brief dark blip every ~500 ms**.
5. On success the receiver reboots automatically. With the button **not** held it comes back in
   normal operation (rainbow effect → ESP-NOW).

If the LED keeps the fast short flash and never goes to the slow blink, the home WiFi was not joined
(check the network/credentials). The device stays in maintenance mode and keeps retrying — it never
falls back to an access point.

## Developer: first install (USB bootstrap)

OTA can only update a device that already runs OTA-capable firmware, so the **first** flash of this
firmware must be over USB-C:

```bash
# Windows (PowerShell): UTF-8 is required, otherwise esptool 5.x aborts with UnicodeEncodeError
$env:PYTHONIOENCODING="utf-8"; $env:PYTHONUTF8="1"
pio run -e empfaenger -t upload --upload-port COM3
```

No button press is needed for the USB flash; the XIAO's native USB-Serial/JTAG auto-resets into the
bootloader.

## Finding the receiver's IP

OTA over a direct IP needs no mDNS (and mDNS does not cross the wired-LAN ↔ WiFi subnet boundary in
this network). Set `upload_port` in `platformio.ini [env:empfaenger-ota]` to the receiver's address.
A router-side DHCP reservation on the XIAO's MAC keeps this address stable. To discover it ad hoc,
probe the ArduinoOTA UDP handshake on candidate hosts (a device that answers `AUTH …` on UDP 3232 is
running ArduinoOTA).

## HIL acceptance checklist

| # | Step | Expected | Verifies |
|---|---|---|---|
| 1 | Power on **without** button | Rainbow effect, then normal ESP-NOW; **no** `Bogenampel-Empfaenger` AP in a WiFi scan; no router association | FR-005, SC-003 |
| 2 | From the sender, run commands | Received and acted on as before | FR-006, SC-006 |
| 3 | Power on **with** button held | No rainbow/timer/ESP-NOW; LED **fast short flash** | FR-002, FR-004a, SC-001 |
| 4 | Wait for WiFi | LED switches to **slow even blink**; device answers OTA at its IP within 20 s | FR-003, FR-004b, SC-002 |
| 5 | Run `pio run -e empfaenger-ota -t upload` | LED **mostly lit + brief blips**; transfer completes | FR-004c, US1 |
| 6 | After flash | Device reboots; button released → normal operation | FR-008 |
| 7 | In OTA mode, disable the AP / wrong credentials | Stays in maintenance mode, keeps fast flash, never opens own AP, never starts ESP-NOW | FR-009 |
| 8 | Interrupt a transfer (cancel upload mid-way) | Old firmware still runs; device still reachable in maintenance mode | FR-010 |
| 9 | Confirm OTA mode is unreachable without the button | A normal boot (no button) never joins WiFi / answers OTA; access requires the physical button-at-boot gate (no network password) | FR-012 |

## Build sanity

```bash
pio run -e empfaenger      # compiles the receiver firmware (no upload)
```

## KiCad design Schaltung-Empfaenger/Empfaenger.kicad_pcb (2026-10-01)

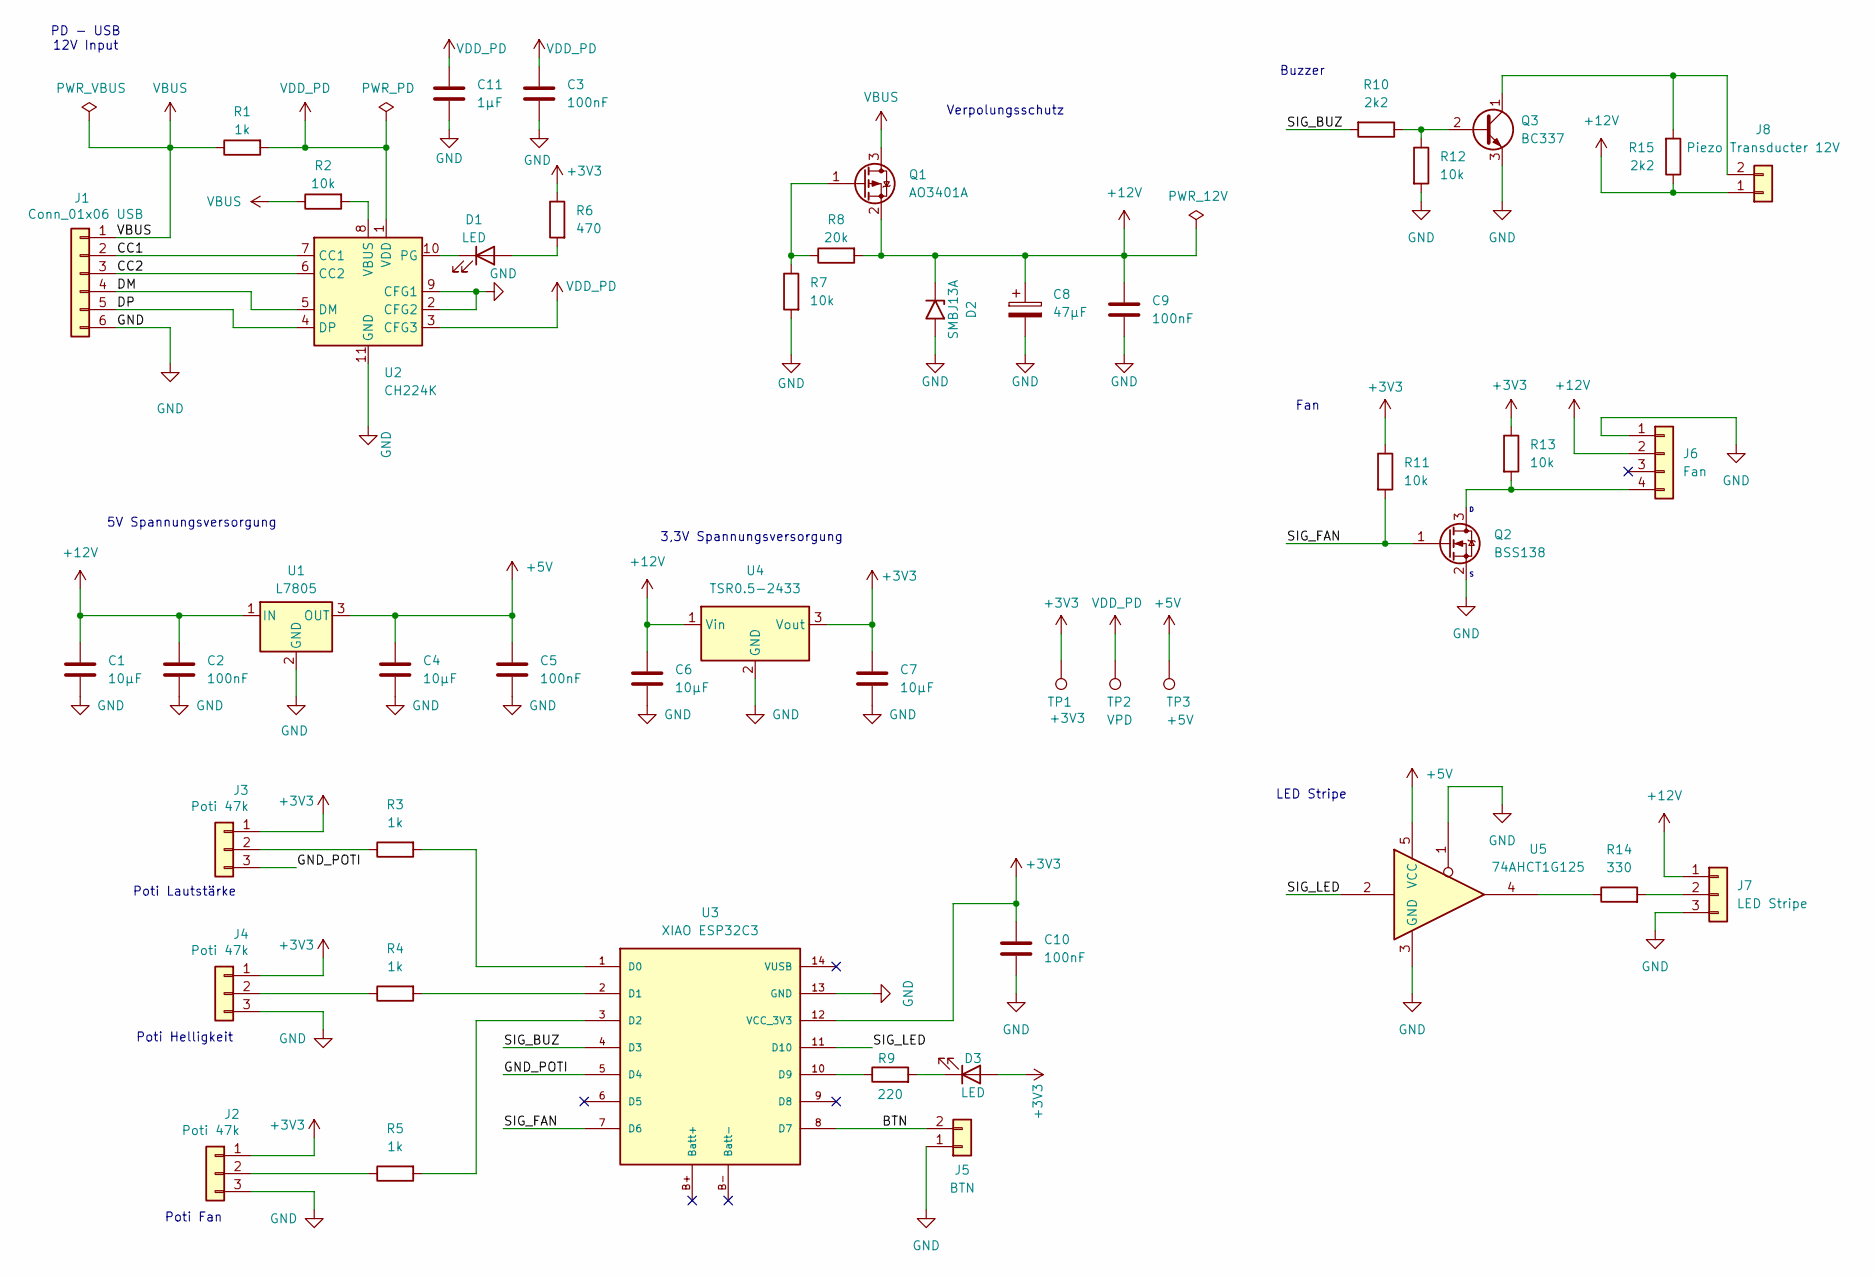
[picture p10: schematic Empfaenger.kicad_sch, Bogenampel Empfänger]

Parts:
C1, C4, C6, C7: 10µF; C_1206_3216Metric
C2, C3, C5, C9, C10: 100nF; C_1206_3216Metric
C8: 47µF; CP_Radial_D8.0mm_P3.50mm
C11: 1µF; C_1206_3216Metric
D1, D3: LED; LED_D5.0mm
D2: SMBJ13A; D_SMB
J1: Conn_01x06 USB; JST_XH_B6B-XH-AM_1x06_P2.50mm_Vertical
J2, J3, J4: Poti 47k; JST_XH_B3B-XH-AM_1x03_P2.50mm_Vertical
J5: BTN; JST_XH_B2B-XH-AM_1x02_P2.50mm_Vertical
J6: Fan; JST_XH_B4B-XH-AM_1x04_P2.50mm_Vertical
J7: LED Stripe; JST_XH_B3B-XH-AM_1x03_P2.50mm_Vertical
J8: Piezo Transducter 12V; JST_XH_B2B-XH-AM_1x02_P2.50mm_Vertical
Q1: AO3401A; SOT-23
Q2: BSS138; SOT-23; MPN 2N7002
Q3: BC337; TO-92_Inline
R1: 1k; R_1206_3216Metric
R2, R7, R11, R12, R13: 10k; R_0603_1608Metric
R3, R4, R5: 1k; R_0603_1608Metric
R6: 470; R_0603_1608Metric
R8: 20k; R_0603_1608Metric
R9: 220; R_0603_1608Metric
R10, R15: 2k2; R_0603_1608Metric
R14: 330; R_0603_1608Metric
TP1: +3V3; TestPoint_Pad_D1.5mm
TP2: VPD; TestPoint_Pad_D1.5mm
TP3: +5V; TestPoint_Pad_D1.5mm
U1: L7805; TO-220-3_Vertical
U2: CH224K; SSOP-10-1EP_3.9x4.9mm_P1mm_EP2.1x3.3mm
U3: XIAO ESP32C3; xiao_esp32c3
U4: TSR0.5-2433; Converter_DCDC_TRACO_TSR0.5-24xx_TSR0.5-24xxx_THT
U5: 74AHCT1G125; SOT-353_SC-70-5

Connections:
+3V3: C7.1, C10.1, D3.2 (A), J2.1, J3.1, J4.1, R6.1, R11.1, R13.1, TP1.1 (1_1), U3.12 (VCC_3V3), U4.3 (Vout)
+5V: C4.1, C5.1, TP3.1 (1_1), U1.3 (OUT), U5.5 (VCC)
+12V: C1.1, C2.1, C6.1, C8.1, C9.1, D2.1 (A1), J6.2, J7.1, J8.1, Q1.2 (S), R8.2, R15.1, U1.1 (IN), U4.1 (Vin)
/BTN: J5.2, U3.8 (D7)
/CC1: J1.2, U2.7 (CC1)
/CC2: J1.3, U2.6 (CC2)
/DM: J1.4, U2.5 (DM)
/DP: J1.5, U2.4 (DP)
/GND_POTI: J3.3, U3.5 (D4)
/SIG_BUZ: R10.2, U3.4 (D3)
/SIG_FAN: Q2.1 (G), R11.2, U3.7 (D6)
/SIG_LED: U3.11 (D10), U5.2
GND: C1.2, C2.2, C3.2, C4.2, C5.2, C6.2, C7.2, C8.2, C9.2, C10.2, C11.2, D2.2 (A2), J1.6, J2.3, J4.3, J5.1, J6.1, J7.3, Q2.2 (S), Q3.3 (E), R7.2, R12.2, U1.2 (GND), U2.2 (CFG2), U2.9 (CFG1), U2.11 (GND), U3.13 (GND), U4.2 (GND), U5.1, U5.3 (GND)
unnamed: D1.2 (A), R6.2
unnamed: D1.1 (K), U2.10 (PG)
unnamed: D3.1 (K), R9.2
unnamed: J2.2, R5.1
unnamed: J3.2, R3.1
unnamed: J4.2, R4.1
unnamed: J6.4, Q2.3 (D), R13.2
unnamed: J7.2, R14.2
unnamed: J8.2, Q3.1 (C), R15.2
unnamed: Q1.1 (G), R7.1, R8.1
unnamed: Q3.2 (B), R10.1, R12.1
unnamed: R14.1, U5.4
unnamed: R2.2, U2.8 (VBUS)
unnamed: R3.2, U3.1 (D0)
unnamed: R4.2, U3.2 (D1)
unnamed: R5.2, U3.3 (D2)
unnamed: R9.1, U3.10 (D9)
VBUS: J1.1, Q1.3 (D), R1.1, R2.1
VDD_PD: C3.1, C11.1, R1.2, TP2.1 (1_1), U2.1 (VDD), U2.3 (CFG3)

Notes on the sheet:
Poti Lautstärke
Buzzer
Poti Helligkeit
LED Stripe
Fan
Verpolungsschutz
Poti Fan
3,3V Spannungsversorgung
5V Spannungsversorgung
PD - USB 12V Input

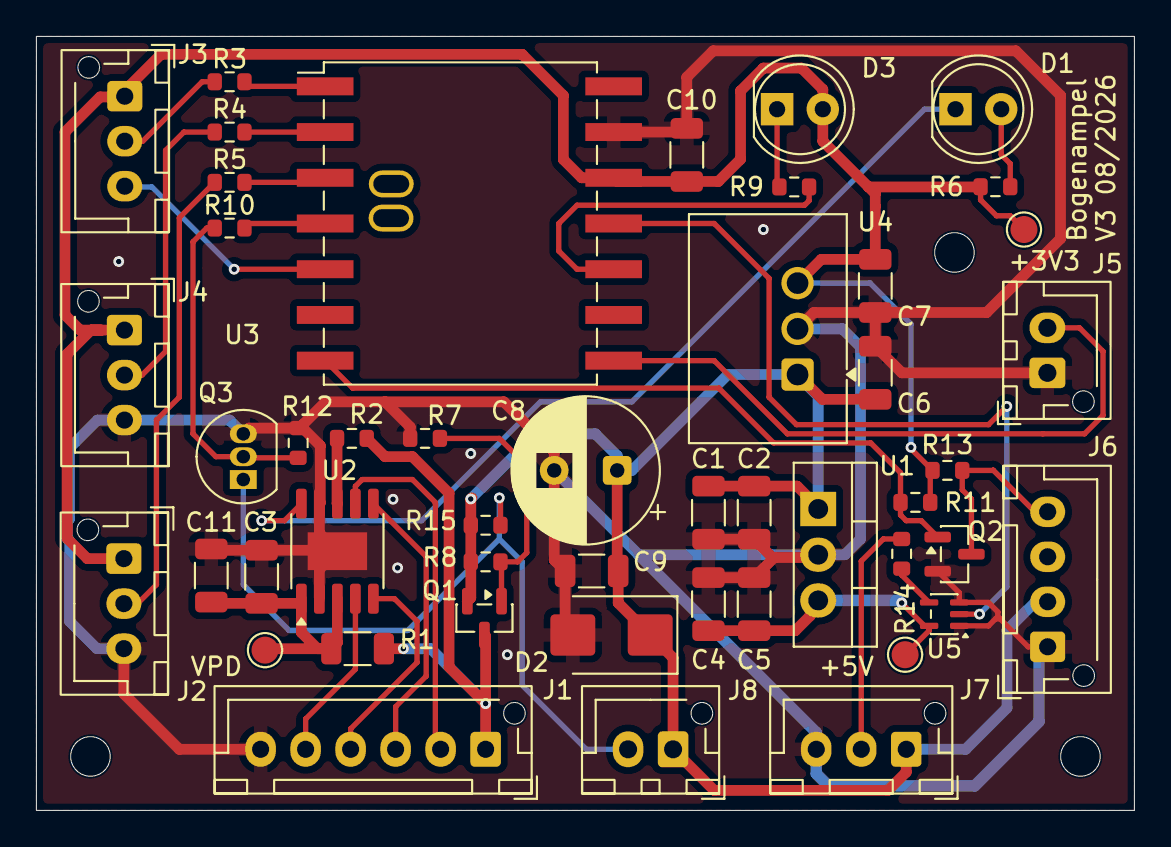
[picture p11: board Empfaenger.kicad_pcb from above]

Board: 2 copper layers, 61.0 x 43.0 mm, 48 parts (0 on the bottom side), 32 nets.

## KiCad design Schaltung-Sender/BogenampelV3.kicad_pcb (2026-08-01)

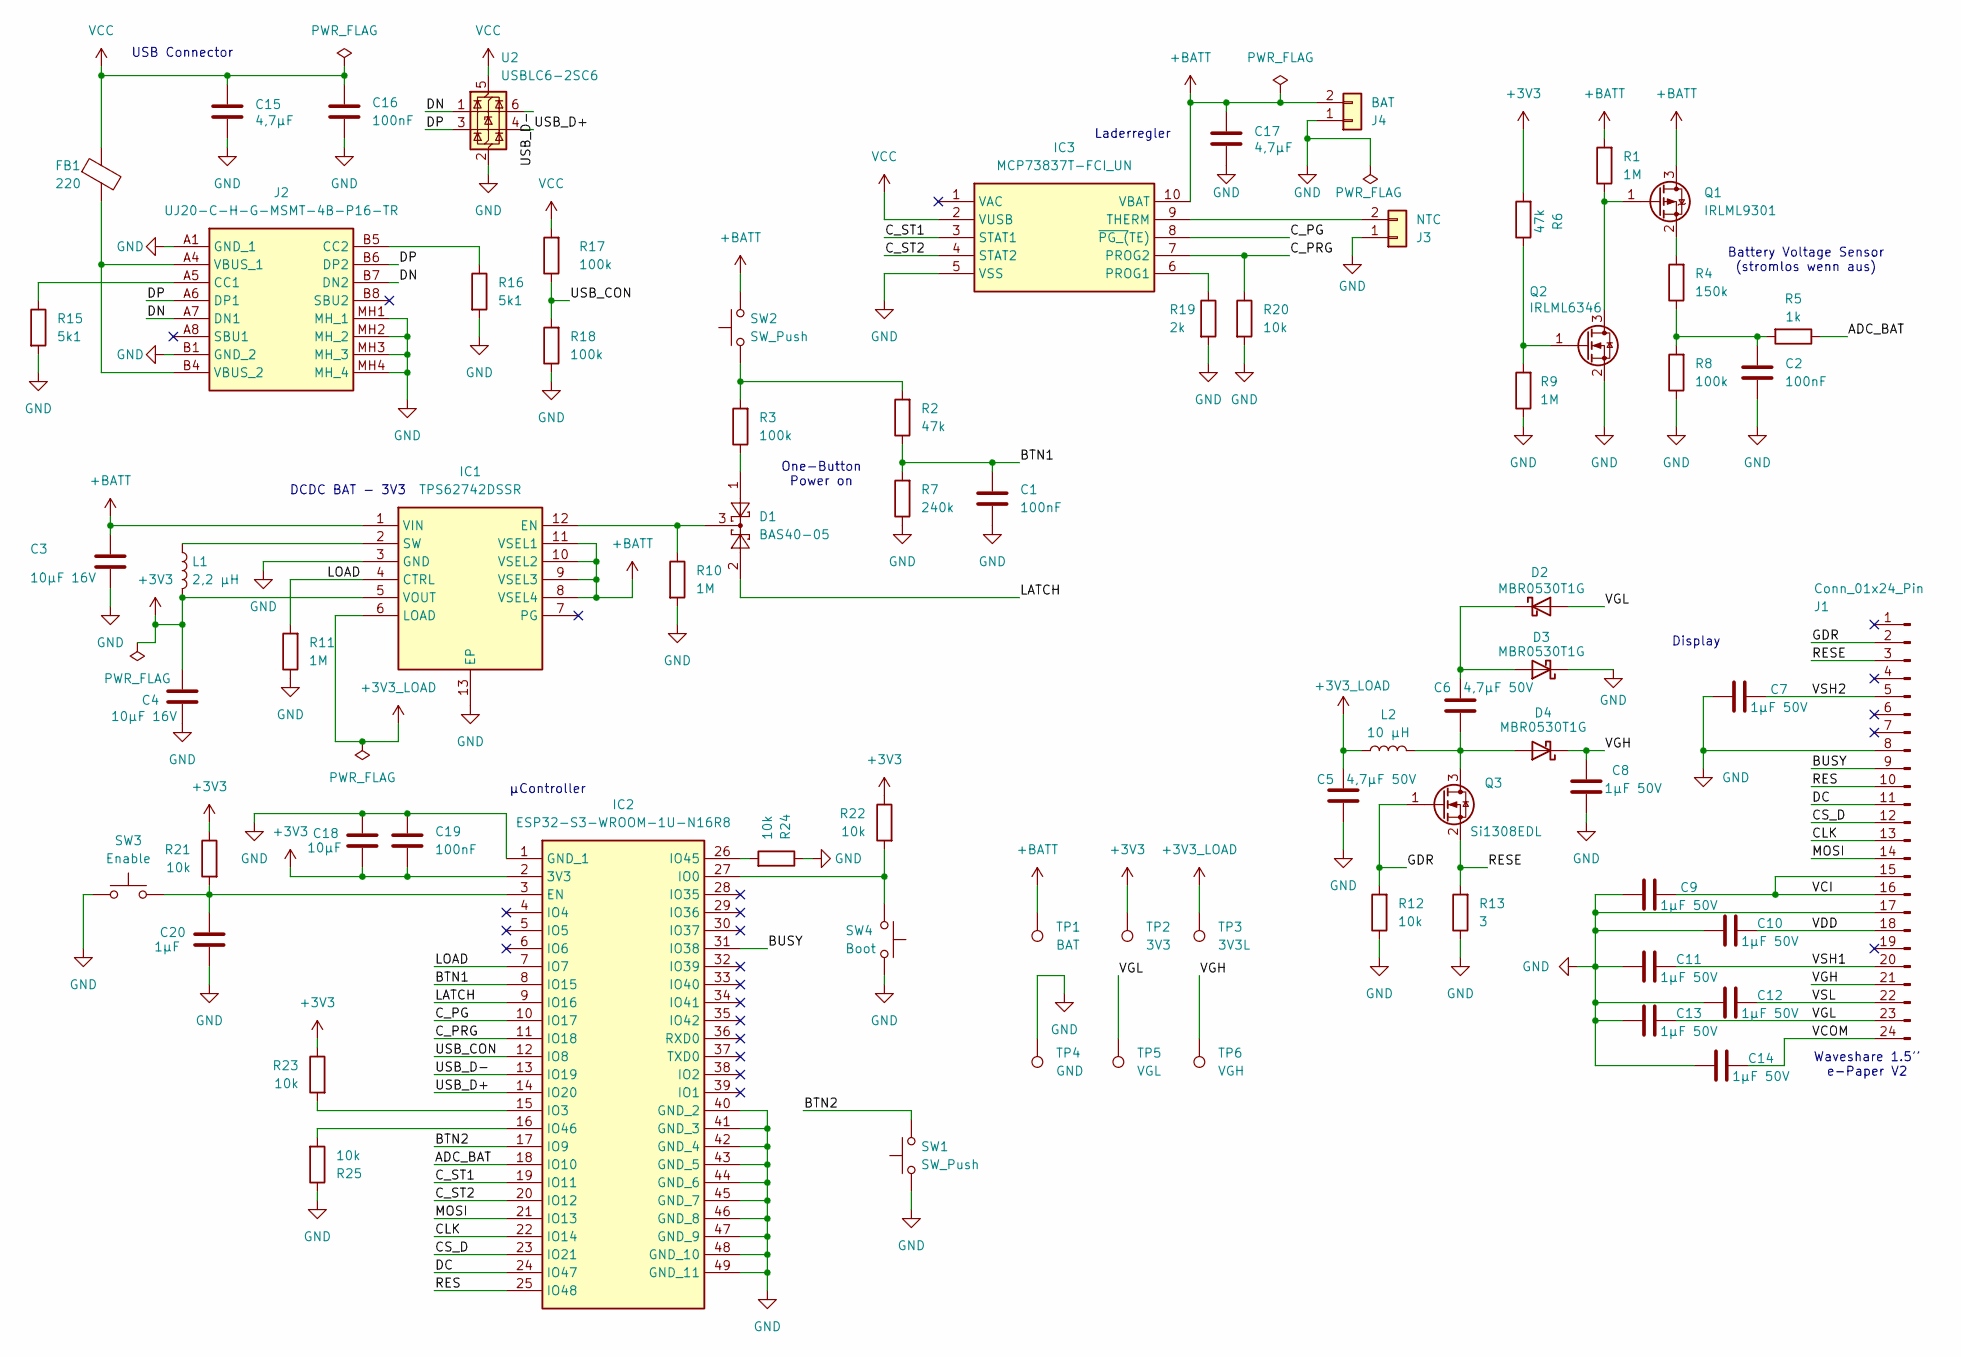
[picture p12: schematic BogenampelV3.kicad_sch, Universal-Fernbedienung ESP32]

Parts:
C1, C16, C19: 100nF; C_0603_1608Metric
C2: 100nF; C_0805_2012Metric
C3, C4: 10µF 16V; C_0805_2012Metric
C5, C6: 4,7µF 50V; C_1206_3216Metric
C7, C8, C9, C10, C11, C12, C13, C14: 1µF 50V; C_0805_2012Metric
C15, C17: 4,7µF; C_0805_2012Metric
C18: 10µF; C_0805_2012Metric
C20: 1µF; C_0805_2012Metric
D1: BAS40-05; SOT-23
D2, D3, D4: MBR0530T1G; D_SOD-123
FB1: 220; R_0805_2012Metric
IC1: TPS62742DSSR; SON50P200X300X80-13N-D; Mouser Part Number 595-TPS62742DSSR
IC2: ESP32-S3-WROOM-1U-N16R8; ESP32S3WROOM1UN16R8; Mouser Part Number 356-ESP32S3WM1UN16R8
IC3: MCP73837T-FCI_UN; SOP50P490X110-10N; Mouser Part Number 579-MCP73837T-FCI/UN
J1: Conn_01x24_Pin; Hirose_FH12-24S-0.5SH_1x24-1MP_P0.50mm_Horizontal
J2: UJ20-C-H-G-MSMT-4B-P16-TR; UJ20CHGMSMT4BP16TR; Manufacturer_Part_Number UJ20-C-H-G-MSMT-4B-P16-TR
J3: NTC; PinHeader_1x02_P2.54mm_Vertical; MPN 61300211121
J4: BAT; PinHeader_1x02_P2.54mm_Vertical; MPN 61300211121
L1: 2,2 µH; L_Coilcraft_LPS3314
L2: 10 µH; L_Coilcraft_LPS3314
Q1: IRLML9301; SOT-23
Q2: IRLML6346; SOT-23
Q3: Si1308EDL; SOT-323_SC-70
R1, R9, R10, R11: 1M; R_1206_3216Metric
R2, R6: 47k; R_1206_3216Metric
R3, R8, R17, R18: 100k; R_1206_3216Metric
R4: 150k; R_1206_3216Metric
R5: 1k; R_1206_3216Metric
R7: 240k; R_1206_3216Metric
R12, R20, R21, R22, R23, R24, R25: 10k; R_1206_3216Metric
R13: 3; R_1206_3216Metric
R15, R16: 5k1; R_1206_3216Metric
R19: 2k; R_1206_3216Metric
SW1, SW2: SW_Push; SW_PUSH-12mm_Wuerth-430476085716
SW3: Enable; SW_PUSH_6mm_H5mm
SW4: Boot; SW_PUSH_6mm_H5mm
TP1: BAT; TestPoint_Pad_D1.5mm
TP2: 3V3; TestPoint_Pad_D1.5mm
TP3: 3V3L; TestPoint_Pad_D1.5mm
TP4: GND; TestPoint_Pad_1.5x1.5mm
TP5: VGL; TestPoint_Pad_D1.5mm
TP6: VGH; TestPoint_Pad_D1.5mm
U2: USBLC6-2SC6; SOT-23-6

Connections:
+3V3: C4.1, C18.2, C19.2, IC1.5 (VOUT), IC2.2 (3V3), L1.2, R6.2, R21.1, R22.1, R23.1, TP2.1 (1_1)
+3V3_LOAD: C5.1, IC1.6 (LOAD), L2.1, TP3.1 (1_1)
+BATT: C3.1, C17.1, IC1.1 (VIN), IC1.8 (VSEL4), IC1.9 (VSEL3), IC1.10 (VSEL2), IC1.11 (VSEL1), IC3.10 (VBAT), J4.2, Q1.3 (D), R1.2, SW2.2, TP1.1 (1_1)
/ADC_BAT: IC2.18 (IO10), R5.1
/BTN1: C1.1, IC2.8 (IO15), R2.1, R7.2
/BTN2: IC2.17 (IO9), SW1.2
/BUSY: IC2.31 (IO38), J1.9
/CLK: IC2.22 (IO14), J1.13
/CS_D: IC2.23 (IO21), J1.12
/C_PG: IC2.10 (IO17), IC3.8 (~PG_(TE))
/C_PRG: IC2.11 (IO18), IC3.7 (PROG2), R20.1
/C_ST1: IC2.19 (IO11), IC3.3 (STAT1)
/C_ST2: IC2.20 (IO12), IC3.4 (STAT2)
/DC: IC2.24 (IO47), J1.11
/DN: J2.A7 (DN1), J2.B7 (DN2), U2.1 (I/O1)
/DP: J2.A6 (DP1), J2.B6 (DP2), U2.3 (I/O2)
/GDR: J1.2, Q3.1 (G), R12.2
/LATCH: D1.2, IC2.9 (IO16)
/LOAD: IC1.4 (CTRL), IC2.7 (IO7), R11.2
/MOSI: IC2.21 (IO13), J1.14
/RES: IC2.25 (IO48), J1.10
/RESE: J1.3, Q3.2 (S), R13.2
/USB_CON: IC2.12 (IO8), R17.1, R18.2
/USB_D+: IC2.14 (IO20), U2.4 (I/O2)
/USB_D-: IC2.13 (IO19), U2.6 (I/O1)
/VCI: C9.2, J1.15, J1.16
/VCOM: C14.2, J1.24
/VDD: C10.2, J1.18
/VGH: C8.2, D4.1 (K), J1.21, TP6.1 (1_1)
/VGL: C13.2, D2.2 (A), J1.23, TP5.1 (1_1)
/VSH1: C11.2, J1.20
/VSH2: C7.2, J1.5
/VSL: C12.2, J1.22
GND: C1.2, C2.2, C3.2, C4.2, C5.2, C7.1, C8.1, C9.1, C10.1, C11.1, C12.1, C13.1, C14.1, C15.2, C16.2, C17.2, C18.1, C19.1, C20.2, D3.1 (K), IC1.3 (GND), IC1.13 (EP), IC2.1 (GND_1), IC2.40 (GND_2), IC2.41 (GND_3), IC2.42 (GND_4), IC2.43 (GND_5), IC2.44 (GND_6), IC2.45 (GND_7), IC2.46 (GND_8), IC2.47 (GND_9), IC2.48 (GND_10), IC2.49 (GND_11), IC3.5 (VSS), J1.8, J1.17, J2.A1 (GND_1), J2.B1 (GND_2), J2.MH1 (MH_1), J2.MH2 (MH_2), J2.MH3 (MH_3), J2.MH4 (MH_4), J3.1, J4.1, Q2.2 (S), R7.1, R8.1, R9.1, R10.2, R11.1, R12.1, R13.1, R15.2, R16.2, R18.1, R19.2, R20.2, R24.1, R25.1, SW1.1, SW3.1, SW4.1, TP4.1 (1_1), U2.2 (GND)
unnamed: C2.1, R4.1, R5.2, R8.2
unnamed: D1.1, R3.1
unnamed: C6.2, D2.1 (K), D3.2 (A)
unnamed: C6.1, D4.2 (A), L2.2, Q3.3 (D)
unnamed: D1.3, IC1.12 (EN), R10.1
unnamed: IC1.2 (SW), L1.1
unnamed: C20.1, IC2.3 (EN), R21.2, SW3.2
unnamed: IC2.27 (IO0), R22.2, SW4.2
unnamed: IC2.15 (IO3), R23.2
unnamed: IC2.26 (IO45), R24.2
unnamed: IC2.16 (IO46), R25.2
unnamed: IC3.6 (PROG1), R19.1
unnamed: IC3.9 (THERM), J3.2
unnamed: J2.A5 (CC1), R15.1
unnamed: J2.B5 (CC2), R16.1
unnamed: FB1.2, J2.A4 (VBUS_1), J2.B4 (VBUS_2)
unnamed: Q1.1 (G), Q2.3 (D), R1.1
unnamed: Q1.2 (S), R4.2
unnamed: Q2.1 (G), R6.1, R9.2
unnamed: R2.2, R3.2, SW2.1
VCC: C15.1, C16.1, FB1.1, IC3.2 (VUSB), R17.2, U2.5 (VBUS)

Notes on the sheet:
USB Connector
Battery Voltage Sensor (stromlos wenn aus)
One-Button Power on
µController
Laderregler
Display
DCDC BAT - 3V3
Waveshare 1.5'' e-Paper V2

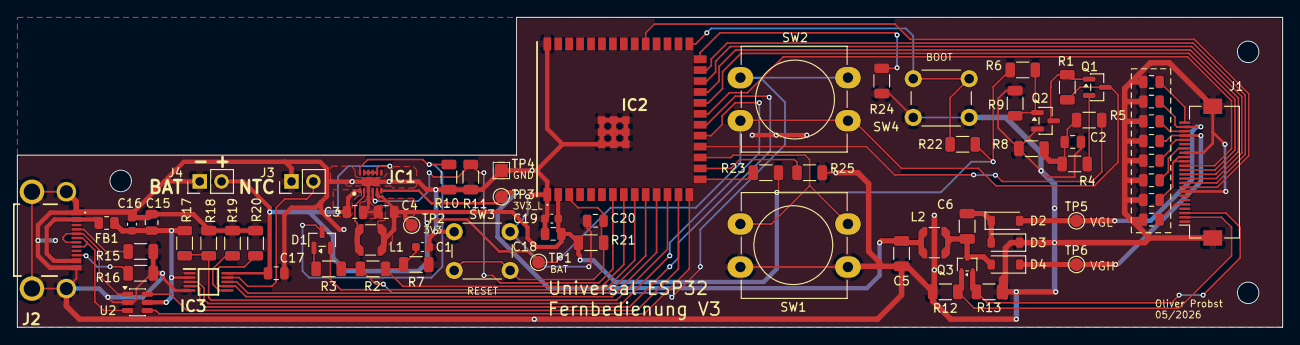
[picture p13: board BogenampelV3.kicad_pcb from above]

Board: 2 copper layers, 147.0 x 36.0 mm, 72 parts (0 on the bottom side), 55 nets.

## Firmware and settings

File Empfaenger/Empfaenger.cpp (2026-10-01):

/**
 * @file Empfaenger.cpp
 * @brief Hauptdatei für Bogenampel V3 Empfänger (Anzeigeeinheit)
 *
 * PORT aus V2 (Empfaenger/Empfaenger.ino) auf Seeed XIAO ESP32C3:
 * - Funk: ESP-NOW statt NRF24 (RadioManager, 11 Kommandos unverändert)
 * - Zeitbasis: esp_timer (1 Hz) statt AVR-Timer1 — gleiches Muster
 *   (Callback setzt volatile-Flag, loop() arbeitet ab)
 * - Timer-Logik 1:1 inkl. AUTONOMEM Passenende und Gruppenwechsel (FR-004):
 *   Zeitablauf benötigt KEINEN Funkempfang!
 * - Status-LED D9 AKTIV LOW (Strapping-Fix Befund 3), ersetzt die 3 V2-LEDs
 * - 3 Potis live: Lautstärke (D0), Helligkeit (D1), Lüfter (D2) — US4
 * - Debug-Taster D7: lokaler Testlauf ohne Sender (FR-024)
 */

#include "Config.h"
#include "Commands.h"
#include "RadioManager.h"
#include "OTAManager.h"
#include "DisplayManager.h"
#include "BuzzerManager.h"
#include "FanManager.h"

#include <FastLED.h>
#include <esp_timer.h>
#include <esp_task_wdt.h>

//=============================================================================
// Globale Instanzen
//=============================================================================

RadioManager radio;

// WS2811 LED Strip (12V, IC-gesteuert, RGB)
CRGB leds[LEDStrip::TOTAL_LEDS];

// Display Manager
DisplayManager display(leds);

// Buzzer Manager (LEDC, Lautstärke vom Poti)
BuzzerManager buzzer(Pins::BUZZER, Timing::BUZZER_FREQUENCY_HZ);

// Lüfter (LEDC ≥ 25 kHz, Drehzahl vom Poti)
FanManager fan(Pins::FAN_PWM, Pins::FAN_POTI);

// Forward-Deklarationen
void showRainbowEffect();
void showLedsSoftStart();
void handleCommand(RadioCommand cmd);
void updateAlarm();
void updatePotis();
void updateBrightnessPreview();
void updateStatusLed();
void checkButton();
void updatePreparation();
void updateTimer();
void showCurrentGroup(CRGB color);
void showStoppedState();
void serviceDelay(uint32_t ms);

// Boot-Modus (FR-001): einmal beim Start entschieden, danach fix (FR-007).
//   true  = OTA-Wartungsmodus (Taster D7 beim Boot gehalten): WiFi + ArduinoOTA,
//           KEIN ESP-NOW, kein Timer (FR-002).
//   false = Normalbetrieb (ESP-NOW), KEIN WiFi/AP (FR-005).
bool bootOtaMode = false;
bool readOtaModeButton();
void setupNormal();
void setupOta();
void loopNormal();
void loopOta();
void updateLedDebugAnimation();

// State-Variablen
uint8_t lastButtonReading = HIGH;  // Letzter gelesener Pin-Zustand
uint8_t buttonState = HIGH;        // Stabiler Button-Zustand nach Debouncing
uint32_t lastDebounceTime = 0;     // Zeitpunkt der letzten Button-Änderung

// Sammel-Flag für direkte FastLED-Array-Manipulationen (Alarm, Helligkeits-
// Vorschau, …). Zusammen mit display.isDirty() entscheidet es, ob loopNormal()
// am Ende der Iteration genau EIN FastLED.show() ausführt. Mehrere show() in
// schneller Folge verschieben beim WS2811 sonst den ersten Pixel / mischen Farben.
bool ledsDirty = false;

// Timer-Variablen (esp_timer-basiert, Muster wie V2-Timer1-ISR).
// Zähler statt bool-Flag: Der esp_timer-Task hat höhere Priorität als der
// Arduino-Loop und tickt zuverlässig weiter, auch wenn loopNormal() mal über
// eine Sekunde blockiert. Ein bool könnte in dem Fall nur EINEN Tick halten —
// der Countdown liefe gegenüber der echten Zeit nach. Writer (Timer-Task)
// erhöht nur, Leser (Loop) führt seinen eigenen Stand mit: kein Read-Modify-
// Write über Taskgrenzen, also auch kein Race.
volatile uint32_t secondTickCount = 0;  // vom Timer-Callback erhöht
uint32_t handledTickCount = 0;          // vom Loop nachgezogen
esp_timer_handle_t secondTimer = nullptr;
bool timerRunning = false;         // Läuft der Timer?
uint32_t timerRemainingSeconds = 0;  // Verbleibende Sekunden
uint32_t timerDurationMs = 0;      // Timer-Dauer in Millisekunden
Groups::Type currentGroup = Groups::Type::GROUP_AB;      // Aktuelle Gruppe (AB oder CD)
Groups::Position currentPosition = Groups::Position::POS_1;  // Aktuelle Position (1 oder 2)
bool groupsEnabled = true;         // Sind Gruppen aktiv? (false = 1-2 Schützen Modus)

// Vorbereitungsphase
bool inPreparationPhase = false;   // Läuft die Vorbereitungsphase?
uint32_t preparationRemainingSeconds = 0;  // Verbleibende Sekunden Vorbereitungsphase
uint32_t preparationDurationMs = 0;

// Alarm State-Variablen (nicht-blockierend)
bool alarmActive = false;          // Läuft gerade ein Alarm?
uint8_t alarmBlinkCount = 0;       // Aktueller Blink-Zähler (0-7)
bool alarmLedState = false;        // LED-Zustand
uint32_t alarmLastToggle = 0;      // Zeitpunkt der letzten Umschaltung

// Lokalregler (Potis, US4)
uint32_t lastPotiUpdate = 0;       // Zeitpunkt der letzten Poti-Messung
uint8_t currentBrightness = LEDStrip::BRIGHTNESS_MAX;  // Aktuelle Helligkeit
uint8_t lastVolumeDuty = 0;        // Letzter Lautstärke-Duty (für Bewegungserkennung)
bool potiFeedbackEnabled = false;  // Vorschau erst nach erstem Messzyklus (kein Feedback beim Start)

// Helligkeits-Vorschau: beim Drehen am Helligkeits-Poti "888" anzeigen, damit die
// Reglereinstellung sofort sichtbar ist (analog zum Lautstärke-Vorhörton). Der
// vorherige Display-Inhalt wird gesichert und nach dem Nachlauf wiederhergestellt.
CRGB ledsBackup[LEDStrip::TOTAL_LEDS];
bool brightnessPreviewActive = false;
uint32_t brightnessPreviewUntil = 0;

// Status-LED (D9, aktiv LOW): an = bereit, kurzes Aus-Blinken bei Frame-Empfang
uint32_t lastFrameCount = 0;       // Letzter Stand des Frame-Zählers
uint32_t ledBlinkUntil = 0;        // LED bleibt bis dahin aus (Empfangs-Blink)

//=============================================================================
// 1-Hz-Zeitbasis (esp_timer, R-7)
//=============================================================================

/**
 * @brief Periodischer 1-s-Callback — setzt nur das Flag (wie V2-Timer1-ISR)
 */
void onSecondTick(void* /*arg*/) {
    secondTickCount = secondTickCount + 1;
}

//=============================================================================
// Setup
//=============================================================================

void setup() {
    // ----- Gemeinsamer, hardware-sicherer Frühstart (BEIDE Modi) -----

    // FRÜH: Poti-Fußpunkt aktivieren (Strapping-Fix Befund 2) — D4 war beim
    // Reset hochohmig, damit GPIO2 HIGH bootet; ab jetzt arbeitet der
    // Lautstärke-Poti-Teiler normal
    pinMode(Pins::POTI_GND, OUTPUT);
    digitalWrite(Pins::POTI_GND, LOW);

    // FRÜH: LED-Datenleitung definiert auf LOW. Seit der PD-12V-Platine sitzt
    // U5 (74AHCT1G125) zwischen GPIO10 und dem Strip; sein Eingang hat keinen
    // Pulldown. Bis FastLED.addLeds() den Pin übernimmt (nach Buzzer-Init) läge
    // er sonst hochohmig → der Buffer-Ausgang kippt/schwingt und schiebt
    // undefinierte 5-V-Pegel auf die Datenleitung (Geisterpixel beim Start).
    // FastLED konfiguriert den Pin danach selbst neu.
    pinMode(Pins::LED_STRIP, OUTPUT);
    digitalWrite(Pins::LED_STRIP, LOW);

    // FRÜH: Lüfter-PWM übernehmen (R5-Pull-up hielt die PWM-Leitung LOW →
    // Lüfter lief bis jetzt auf Minimaldrehzahl, Befund 6). Auch im
    // OTA-Wartungsmodus nötig (Hardware-Safety, Constitution III).
    fan.begin();

    // Status-LED (D9, aktiv LOW): erst mal aus
    pinMode(Pins::STATUS_LED, OUTPUT);
    digitalWrite(Pins::STATUS_LED, STATUS_LED_OFF);

    // Debug-Taster (J5, D7, INPUT_PULLUP, aktiv LOW) — wird gleich für die
    // Boot-Modus-Entscheidung gelesen
    pinMode(Pins::BTN_DEBUG, INPUT_PULLUP);

    // Serial für Debugging
    #if DEBUG_ENABLED
    Serial.begin(System::SERIAL_BAUD);
    while (!Serial && millis() < 2000);
    DEBUG_PRINTLN("");
    DEBUG_PRINTLN("======================================");
    DEBUG_PRINTLN("  Bogenampel Empfaenger V3.0");
    DEBUG_PRINTLN("======================================");
    DEBUG_PRINTF("Build: %s %s\n", __DATE__, __TIME__);
    #endif

    // ----- Boot-Modus-Entscheidung (FR-001): genau einmal, hier -----
    bootOtaMode = readOtaModeButton();

    if (bootOtaMode) {
        DEBUG_PRINTLN("Boot-Modus: OTA-WARTUNG (Taster gehalten)");
        setupOta();
    } else {
        DEBUG_PRINTLN("Boot-Modus: Normalbetrieb");
        setupNormal();
    }
}

/**
 * @brief Liest den Debug-Taster (J5/D7, aktiv LOW) entprellt beim Boot.
 *
 * Verlangt stabiles LOW über mehrere Abtastungen (~25 ms), damit ein einzelner
 * Störimpuls die Boot-Entscheidung nicht kippt (SC-001).
 * @return true, wenn der Taster stabil gedrückt ist → OTA-Wartungsmodus.
 */
bool readOtaModeButton() {
    constexpr uint8_t SAMPLES = 5;
    for (uint8_t i = 0; i < SAMPLES; i++) {
        if (digitalRead(Pins::BTN_DEBUG) != LOW) {
            return false;  // einmal nicht gedrückt → Normalbetrieb
        }
        delay(5);
    }
    return true;  // ~25 ms stabil LOW
}

/**
 * @brief Normalbetrieb-Setup: ESP-NOW + Timer/Anzeige (FR-005/FR-006).
 *        KEIN WiFi, KEIN SoftAP, kein ArduinoOTA.
 */
void setupNormal() {
    // Buzzer initialisieren (LEDC, stumm — R4-Basis-Pulldown hält den BC337
    // schon beim Boot gesperrt)
    buzzer.begin();

    // LED Strip initialisieren (WS2811-Protokoll, RGB). Reihenfolge erst mit
    // sauberem Datensignal (330-Ω-Serienwiderstand am Daten-Pin) zuverlässig
    // bestimmt: feste Helligkeit + einheitliche Pixel zeigten gesendet Rot→Grün,
    // Grün→Blau ⇒ Standard-RGB. Frühere Messungen waren durch gekippte Bits verfälscht.
    // 800 kHz (Standard-WS2811): 400 kHz getestet → nur sporadisches Aufblitzen,
    // also ist dies ein 800-kHz-Typ. Das frühere Restproblem (Gelb/Weiß kippen)
    // war der Signalpegel; seit der PD-12V-Platine hebt U5 (74AHCT1G125) den
    // Daten-Pin auf 5 V an — der 330-Ω-Serienwiderstand sitzt jetzt hinter U5 (R14).
    FastLED.addLeds<WS2811, Pins::LED_STRIP, RGB>(leds, LEDStrip::TOTAL_LEDS);
    // Temporales Dithering AUS: show() wird im Normalbetrieb nur bei Änderungen
    // aufgerufen (selten). Mit Dithering + brightness<255 bleiben die LEDs dann
    // auf einem Dither-Zwischenwert "hängen" → helligkeitsabhängige Farb-/
    // Helligkeitsartefakte. Ohne Dither ist die Ausgabe deterministisch.
    FastLED.setDither(DISABLE_DITHER);

    // Initiale Helligkeit aus Poti lesen (15-100 %, FR-022) — über Poti::level,
    // konsistent mit updatePotis(); sonst liefe der Regenbogen-Effekt mit
    // verkehrter (oft viel zu dunkler) Helligkeit.
    uint16_t potiValue = Poti::level(Adc::readAveraged(Pins::BRIGHTNESS_POTI));  // gemittelt (Rauschunterdrückung)
    currentBrightness = map(potiValue, 0, Poti::ADC_MAX,
                            LEDStrip::BRIGHTNESS_MIN, LEDStrip::BRIGHTNESS_MAX);
    FastLED.setBrightness(currentBrightness);

    FastLED.clear();
    FastLED.show();
    delay(50);  // Kurze Pause nach Initialisierung
    DEBUG_PRINTF("LED Strip init, Helligkeit: %u\n", currentBrightness);

    // Initiale Buzzer-Lautstärke aus Poti
    updatePotis();

    // Regenbogen-Effekt beim Start zeigen
    showRainbowEffect();

    // ESP-NOW initialisieren (KEIN WiFi-Join, KEIN SoftAP — FR-005/FR-006)
    DEBUG_PRINTLN("Initialisiere ESP-NOW...");
    if (!radio.begin()) {
        DEBUG_PRINTLN("FEHLER: ESP-NOW init fehlgeschlagen!");
        // Fehler-Anzeige: Status-LED blinkt schnell (aktiv LOW!)
        while (true) {
            digitalWrite(Pins::STATUS_LED, STATUS_LED_ON);
            delay(100);
            digitalWrite(Pins::STATUS_LED, STATUS_LED_OFF);
            delay(100);
        }
    }

    // 1-Hz-Zeitbasis starten (esp_timer, R-7)
    const esp_timer_create_args_t timerArgs = {
        .callback = &onSecondTick,
        .arg = nullptr,
        .dispatch_method = ESP_TIMER_TASK,
        .name = "secondTick",
        .skip_unhandled_events = true
    };
    esp_timer_create(&timerArgs, &secondTimer);
    esp_timer_start_periodic(secondTimer, 1000000ULL);  // 1 s

    // Task-Watchdog (Schutz gegen Einfrieren bei Unterspannung): Wenn loopNormal()
    // länger als WDT_TIMEOUT_MS keinen Reset mehr abgibt (z.B. weil die CPU bei
    // einbrechender Versorgung hängt), erzwingt der WDT einen sauberen Neustart —
    // besser als eine mitten in der Passe eingefrorene Ampel. Ersetzt NICHT eine
    // ausreichende Stromversorgung; er fängt nur den Hang-Fall ab.
    // Registrierung erst hier — der blockierende Regenbogen-Start (~5 s) läuft davor.
    constexpr uint32_t WDT_TIMEOUT_MS = 5000;
    esp_task_wdt_config_t wdtConfig = {
        .timeout_ms = WDT_TIMEOUT_MS,
        .idle_core_mask = 0,        // Idle-Tasks nicht überwachen
        .trigger_panic = true       // bei Timeout: Panic → Reset
    };
    // Arduino hat den TWDT ggf. schon initialisiert → dann nur umkonfigurieren.
    if (esp_task_wdt_init(&wdtConfig) == ESP_ERR_INVALID_STATE) {
        esp_task_wdt_reconfigure(&wdtConfig);
    }
    esp_task_wdt_add(NULL);  // loopTask überwachen

    // Sicherer Grundzustand: rot "000" statt dunkler Tafel. Relevant nach einem
    // unerwarteten Neustart (Brown-out, Watchdog) mitten in einer Passe: der
    // Sender merkt davon nichts (Peer bleibt registriert, ACKs kommen weiter)
    // und schickt von sich aus nichts Neues — die Anzeige bliebe sonst dunkel,
    // bis das nächste Kommando eintrifft. Dunkel ist mehrdeutig, Rot nicht.
    showStoppedState();
    showLedsSoftStart();
    display.clearDirty();

    // Bereit: Status-LED an
    digitalWrite(Pins::STATUS_LED, STATUS_LED_ON);

    DEBUG_PRINTLN("Setup abgeschlossen");
    DEBUG_PRINTLN("Warte auf Kommandos vom Sender...");
}

/**
 * @brief OTA-Wartungsmodus-Setup: reiner WiFi-Station-Betrieb + ArduinoOTA
 *        (FR-002/FR-003). KEIN ESP-NOW, kein Timer, kein Regenbogen/Buzzer.
 *        Die große LED-Anzeige bleibt dunkel; die Status-LED (D9) signalisiert
 *        den Zustand (OTAManager, FR-004a-c).
 */
void setupOta() {
    // Service-/Programmiermodus: OTA-bereit UND LED-Debug-Animation auf der
    // großen Anzeige (Verschaltungs-/Pixeltest). Start dunkel, die Animation in
    // loopOta() übernimmt sofort den ersten Frame.
    FastLED.addLeds<WS2811, Pins::LED_STRIP, RGB>(leds, LEDStrip::TOTAL_LEDS);
    FastLED.setDither(DISABLE_DITHER);  // siehe setupNormal: deterministische Ausgabe
    FastLED.clear(true);  // löschen + anzeigen (alle aus)

    // WiFi-Station + ArduinoOTA (kein SoftAP, kein ESP-NOW)
    OTAManager::begin();
}

//=============================================================================
// Loop
//=============================================================================

void loop() {
    // Boot-Modus-Fork (FR-001/FR-007): genau einer der beiden Pfade läuft
    if (bootOtaMode) {
        loopOta();
    } else {
        loopNormal();
    }
}

/**
 * @brief OTA-Wartungsmodus-Loop: OTA bedienen + LED-Debug-Animation (FR-002).
 *
 * OTAManager::handle() erledigt WiFi-Reconnect-Retry, ArduinoOTA und das
 * Status-LED-Signal (FR-004a-c). KEIN delay() hier, damit ArduinoOTA.handle()
 * den laufenden Flash nicht aushungert (FR-004c läuft währenddessen).
 * updateLedDebugAnimation() zeigt zusätzlich den Verschaltungstest auf der
 * großen Anzeige (Farbwechsel alle 5 s, nicht-blockierend).
 */
void loopOta() {
    OTAManager::handle();
    updateLedDebugAnimation();
}

/**
 * @brief LED-Debug-Animation für den Service-/Programmiermodus.
 *
 * Setzt ALLE Pixel (beide Gruppen + alle Segmente) gleichzeitig auf eine Farbe
 * und wechselt im 5-Sekunden-Takt Rot → Grün → Gelb (Endlosschleife). Da bei
 * korrekter Verschaltung alle Pixel identisch leuchten, fallen tote Pixel,
 * falsche Farbreihenfolge oder Verdrahtungsfehler sofort auf. Die Helligkeit
 * folgt live dem Helligkeits-Poti. Nicht-blockierend (millis-getaktet), damit
 * ArduinoOTA parallel bedient werden kann.
 */
void updateLedDebugAnimation() {
    constexpr uint32_t COLOR_INTERVAL_MS = 3000;  // Farbwechsel
    constexpr uint32_t REFRESH_MS = 100;          // Helligkeit/show() (10 Hz)
    // DIAGNOSE: reine Einzelkanäle mit dunklem Trenner. Nach dem dunklen Frame
    // folgt immer logisch ROT → GRÜN → BLAU. Helligkeit live vom Poti, damit
    // sichtbar wird, ob nach dem Dither-Fix nur noch die Helligkeit reagiert
    // (Farbe stabil) und ob der Poti-Wert noch mehrfach über den Bereich springt.
    static const CRGB colors[4] = {
        CRGB::Black,        // Sync-Marker (kurz dunkel)
        CRGB(255, 0, 0),    // logisch ROT
        CRGB(0, 255, 0),    // logisch GRÜN
        CRGB(0, 0, 255)     // logisch BLAU
    };
    static uint32_t lastColor = 0;
    static uint32_t lastRefresh = 0;
    static uint8_t colorIndex = 1;   // mit ROT starten
    static bool first = true;

    uint32_t now = millis();
    if (!first && (now - lastRefresh < REFRESH_MS)) {
        return;  // noch im aktuellen Refresh-Fenster
    }
    lastRefresh = now;

    if (first || (now - lastColor >= COLOR_INTERVAL_MS)) {
        if (!first) colorIndex = (colorIndex + 1) % 4;
        first = false;
        lastColor = now;
    }

    uint16_t potiValue = Poti::level(Adc::readAveraged(Pins::BRIGHTNESS_POTI));
    uint8_t brightness = map(potiValue, 0, Poti::ADC_MAX,
                             LEDStrip::BRIGHTNESS_MIN, LEDStrip::BRIGHTNESS_MAX);
    FastLED.setBrightness(brightness);

    fill_solid(leds, LEDStrip::TOTAL_LEDS, colors[colorIndex]);
    FastLED.show();
}

/**
 * @brief Gibt den aktuellen leds[]-Frame aus — mit Soft-Start gegen Inrush.
 *
 * Der 12-V-Streifen hängt über einen Step-up an der USB-5-V-Schiene. Gehen viele
 * Pixel gleichzeitig von dunkel auf hell (Boot/erstes Bild, Passenstart "alles
 * rot", Alarm-Blitz, "888"-Vorschau), zieht der Step-up den Strom schlagartig aus
 * dem USB — die 5 V brechen kurz ein und der ESP kann per Brown-out resetten.
 *
 * Abhilfe: nur bei einem deutlichen LED-Lastanstieg wird der Helligkeitssprung
 * über wenige Zwischenstufen (~55 ms) gerampt, damit der Step-up den Strom
 * allmählich statt schlagartig anfordert. Kleine Änderungen und jedes Abschalten
 * werden weiterhin sofort ausgegeben (kein sichtbares Nachziehen im Countdown).
 */
void showLedsSoftStart() {
    // Grobe Lastschätzung: Summe (R+G+B) über alle Pixel, VOR globaler Helligkeit —
    // ein Maß dafür, wie viele Kanäle gleichzeitig aktiv sind (∝ Strombedarf).
    uint32_t load = 0;
    for (uint16_t i = 0; i < LEDStrip::TOTAL_LEDS; i++) {
        load += leds[i].r + leds[i].g + leds[i].b;
    }

    // Rampen nur bei nennenswertem Anstieg (~30 Pixel gehen voll an). Abschalten
    // oder kleine Deltas → sofort, ohne Verzögerung.
    static uint32_t lastLoad = 0;
    constexpr uint32_t RAMP_THRESHOLD = 30UL * 255;
    if (load > lastLoad + RAMP_THRESHOLD) {
        const uint8_t target = FastLED.getBrightness();
        constexpr uint8_t STEPS = 8;
        for (uint8_t s = 1; s <= STEPS; s++) {
            // FastLED.show(scale) gibt mit temporärer globaler Helligkeit aus,
            // ohne die per setBrightness gesetzte Helligkeit zu verändern.
            FastLED.show((uint8_t)((uint16_t)target * s / STEPS));
            delay(7);  // 8 × 7 ms ≈ 55 ms Gesamt-Rampe
        }
    } else {
        FastLED.show();
    }
    lastLoad = load;
}

/**
 * @brief Normalbetrieb-Loop: ESP-NOW + Timer/Anzeige (unverändert aus V2).
 *        Es wird KEIN OTAManager::handle() aufgerufen (FR-006).
 */
void loopNormal() {
    // Task-Watchdog bedienen: solange der Loop normal durchläuft, kein Reset.
    esp_task_wdt_reset();

    // Discovery-Antworten bedienen (FT_HELLO → FT_HELLO_ACK)
    radio.update();

    // Empfangene Kommandos abarbeiten (Queue wird vom WiFi-Task gefüllt)
    while (radio.commandAvailable()) {
        RadioCommand cmd = radio.nextCommand();
        DEBUG_PRINTF("RX: %s\n", commandToString(cmd));
        handleCommand(cmd);
    }

    // Aufgelaufene Sekunden abarbeiten (i. d. R. genau eine). Waren es mehr,
    // weil der Loop kurz blockiert hat, werden sie nachgeholt statt verworfen —
    // der Countdown bleibt an der echten Zeit.
    while (handledTickCount != secondTickCount) {
        handledTickCount++;

        // Prüfe Vorbereitungsphase
        updatePreparation();

        // Prüfe Timer und aktualisiere LEDs
        updateTimer();
    }

    // Aktualisiere Buzzer-Zustand (nicht-blockierend, muss jede Iteration laufen)
    buzzer.update();

    // Aktualisiere Alarm-Zustand (nicht-blockierend)
    updateAlarm();

    // Prüfe Debug-Button (lokaler Testlauf ohne Sender, FR-024)
    checkButton();

    // Lokalregler: Lautstärke/Helligkeit/Lüfter aus Potis (≥ 10 Hz, US4)
    updatePotis();
    fan.update();

    // Helligkeits-Vorschau ("888") nach Nachlauf wieder ausblenden
    updateBrightnessPreview();

    // Status-LED: an = bereit, kurzes Aus-Blinken bei Frame-Empfang
    updateStatusLed();

    // Zentrales, einziges FastLED.show() pro Iteration: erst jetzt — nachdem
    // alle Anzeige-Updates ins leds[]-Array geschrieben haben — wird der Frame
    // ausgegeben. Genau ein show() statt mehrerer in schneller Folge verhindert
    // beim WS2811 die Pixel-Verschiebung (Geisterpixel) und Farbmischung (z.B.
    // Rot → Pink), siehe DisplayManager::isDirty().
    if (ledsDirty || display.isDirty()) {
        showLedsSoftStart();  // Inrush-begrenzte Ausgabe (Brown-out-Schutz)
        ledsDirty = false;
        display.clearDirty();
    }

    // Kleine Pause um CPU zu entlasten
    delay(5);
}

//=============================================================================
// Status-LED (D9, aktiv LOW — Strapping-Fix Befund 3)
//=============================================================================
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

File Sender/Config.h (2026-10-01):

/**
 * @file Config.h
 * @brief Zentrale Konfigurationsdatei für Bogenampel V3 Sender (Bedieneinheit)
 *
 * Enthält alle Hardware-Pin-Definitionen, Timing-Konstanten und
 * Konfigurationsparameter für den Sender.
 *
 * Hardware: ESP32-S3-WROOM-1U-N16R8 ("Universal-Fernbedienung", IC2)
 * - Waveshare 1.54" e-Paper V2 (SSD1681, 200x200) als rohes Panel an J1
 * - ESP-NOW Funk (integriert, kein externes Modul)
 * - 2 Taster (SW2/GPIO15 = CONFIG + Einschalten, SW1/GPIO9 = OK), Power-Latch (TPS62742)
 * - LiPo-Lader MCP73837, Batteriespannungsmessung über Teiler
 *
 * Verbindliche Pin-Quelle: specs/004-v3-esp32-port/contracts/hardware-pins.md
 * (extrahiert aus Schaltung-Sender/BogenampelV3.kicad_sch Rev 3.0)
 *
 * @date 2026-06-11
 * @version 3.0
 */

#pragma once

#include <Arduino.h>

//=============================================================================
// DEBUG-KONFIGURATION (muss VOR allen anderen Definitionen stehen!)
//=============================================================================

// Debugging aktivieren/deaktivieren. Per -DDEBUG_ENABLED=0 aus der
// platformio.ini überschreibbar (env:sender-release) — Debug-Ausgaben über
// USB-CDC kosten Strom und Zeit, die im Feldbetrieb niemand liest.
#ifndef DEBUG_ENABLED
#define DEBUG_ENABLED 1  // 1 = Debug-Ausgaben an (USB-CDC), 0 = aus
#endif

// Verkürzte Zeiten für Testläufe. Default 0 — eingeschaltet wird das NICHT hier,
// sondern über -DDEBUG_SHORT_TIMES=1 aus der platformio.ini (env:sender-debug /
// sender-debug-ota). So kann ein Testbuild mit 6-Sekunden-Passe nicht
// versehentlich im Feld landen, und Sender und Empfänger werden immer bewusst
// als Paar umgestellt (die Zeittabelle muss auf beiden Geräten gleich sein).
#ifndef DEBUG_SHORT_TIMES
#define DEBUG_SHORT_TIMES 0  // 1 = Verkürzte Zeiten, 0 = Normale Zeiten
#endif

//=============================================================================
// HARDWARE PIN-DEFINITIONEN
//=============================================================================

namespace Pins {

    //-------------------------------------------------------------------------
    // Power-Management (TPS62742 + Latch)
    //-------------------------------------------------------------------------
    constexpr uint8_t LATCH = 16;  // über D1 (BAS40-05) an EN des TPS62742;
                                   // ERSTE Aktion in setup(): OUTPUT + HIGH!
                                   // LOW = Selbstabschaltung
    constexpr uint8_t LOAD  = 7;   // TPS62742 LOAD-Eingang: schaltet 3V3_LOAD-Rail
                                   // fürs Display; HIGH vor Display-Init, LOW vor Power-Off

    //-------------------------------------------------------------------------
    // Taster (SW2 = BTN1, SW1 = BTN2) — die Namen bezeichnen den PIN, nicht die
    // Bedienrolle. Die Rollen sind in ButtonManager::readRawState() zugeordnet
    // und wurden an die Gehäusebeschriftung angepasst:
    //   BTN1 (GPIO15) → Rolle CONFIG (Weiter/Ändern), zugleich Einschalt-Taster
    //   BTN2 (GPIO9)  → Rolle OK (Bestätigen)
    // Welcher Taster einschaltet, legt der Power-Latch in der Hardware fest.
    // Alarm (3x Klick) und Power-Off (3s halten) liegen auf BEIDEN Tastern.
    //-------------------------------------------------------------------------
    constexpr uint8_t BTN1 = 15;   // SW2: AKTIV HIGH (externer Teiler
                                   // R2/R7 an +BATT, 100nF C1); KEINE internen Pulls!
    constexpr uint8_t BTN2 = 9;    // SW1: gegen GND, INPUT_PULLUP, aktiv LOW

    //-------------------------------------------------------------------------
    // Batterie / USB / Lader (MCP73837)
    //-------------------------------------------------------------------------
    constexpr uint8_t ADC_BAT = 10;  // ADC1_CH9, Teiler R4/R8 = 150k/100k an +BATT
                                     // → V_BAT = V_ADC × 2,5 (Sensor stromlos wenn aus)
    constexpr uint8_t USB_CON = 8;   // VBUS-Teiler (R16/R18), aktiv HIGH bei USB
    constexpr uint8_t C_ST1   = 11;  // Lader STAT1 (Open-Drain → INPUT_PULLUP)
    constexpr uint8_t C_ST2   = 12;  // Lader STAT2 (Open-Drain → INPUT_PULLUP)
    constexpr uint8_t C_PG    = 17;  // Lader Power Good (Open-Drain → INPUT_PULLUP)
    constexpr uint8_t C_PRG   = 18;  // Ladestrom-Umschaltung über R20 an PROG2;
                                     // bleibt INPUT (hochohmig) = Default-Ladestrom

    //-------------------------------------------------------------------------
    // e-Paper (Waveshare 1.54" V2 / SSD1681, rohes Panel an J1, write-only SPI)
    //-------------------------------------------------------------------------
    constexpr uint8_t EPD_CS   = 21;  // J1 Pin 12 (CS_D)
    constexpr uint8_t EPD_DC   = 47;  // J1 Pin 11
    constexpr uint8_t EPD_RST  = 48;  // J1 Pin 10
    constexpr uint8_t EPD_BUSY = 38;  // J1 Pin 9
    constexpr uint8_t SPI_CLK  = 14;  // J1 Pin 13
    constexpr uint8_t SPI_MOSI = 13;  // J1 Pin 14 (kein MISO — e-Paper write-only)
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

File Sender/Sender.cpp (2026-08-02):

/**
 * @file Sender.cpp
 * @brief Hauptdatei für Bogenampel V3 Sender (Bedieneinheit)
 *
 * Hardware: ESP32-S3-WROOM-1U-N16R8, 1.54" e-Paper (SSD1681), ESP-NOW,
 * LiPo + MCP73837-Lader, One-Button-Soft-Power (TPS62742-Latch).
 *
 * Setup-Reihenfolge (kritisch!):
 * 1. LATCH HIGH — allererste Aktion, sonst geht das Gerät beim Loslassen
 *    des Einschalt-Tasters (SW2/GPIO15, Rolle CONFIG) wieder aus (FR-014, R-13)
 * 2. ConfigStore (NVS) → 3. Buttons (Boot-Lockout) → 4. LOAD-Rail + Display
 * 5. Funk (ESP-NOW + Discovery) → 6. StateMachine (Splash)
 *
 * Boot-Modus: Wird beim Einschalten zusätzlich zu CONFIG auch OK gehalten,
 * startet das Gerät im OTA-Wartungsmodus — WiFi-Station + ArduinoOTA, KEIN
 * ESP-NOW, keine StateMachine. Im Normalbetrieb läuft umgekehrt kein WiFi:
 * der ESP32 hat nur ein Radio und damit einen Kanal, den ein Netz-Join oder
 * SoftAP sonst wegzieht und ESP-NOW stilllegt.
 *
 * 1-Hz-Zeitbasis: esp_timer setzt nur ein volatile-Flag, die Verarbeitung
 * läuft im loop() — identisches Muster wie der V2-Timer1-Interrupt (R-7).
 */

#include "Config.h"
#include "Commands.h"

#include <esp_timer.h>

#include "EpaperDisplay.h"
#include "ButtonManager.h"
#include "RadioManager.h"
#include "OTAManager.h"
#include "OtaScreen.h"
#include "ShutdownScreen.h"
#include "PowerManager.h"
#include "ConfigStore.h"
#include "StateMachine.h"

//=============================================================================
// Globale Instanzen
//=============================================================================

ButtonManager buttons;
EpaperDisplay epaper;
RadioManager radio;
PowerManager power;
ConfigStore configStore;
StateMachine stateMachine(epaper, buttons, radio, power, configStore);
OtaScreen otaScreen(epaper);
ShutdownScreen shutdownScreen(epaper);

//=============================================================================
// Boot-Modus — einmal beim Start entschieden, danach fix
//=============================================================================

static bool bootOtaMode = false;

static bool readOtaModeButtons();
static void pollButtonsWhileBusy(const void* param);
static void setupNormal();
static void setupOta();
static void loopNormal();
static void loopOta();
static void otaUpdateStarted();

//=============================================================================
// 1-Hz-Zeitbasis (esp_timer, R-7) — ersetzt den V2-Timer1-Interrupt
//=============================================================================

volatile bool senderSecondTick = false;     // Flag: Sekunde vergangen?
static esp_timer_handle_t secondTimer = nullptr;

/**
 * @brief Periodischer 1-s-Callback — setzt nur das Flag (wie die V2-ISR)
 */
static void onSecondTick(void* /*arg*/) {
    senderSecondTick = true;
}

/**
 * @brief Setzt den Sender-Timer zurück (für synchronen Start mit dem Empfänger)
 *
 * Äquivalent zu V2 `resetSenderTimer()` (TCNT1 = 0): Timer stoppen und neu
 * starten, damit der nächste Tick exakt 1 s nach dem CMD_START liegt.
 */
void resetSenderTimer() {
    if (secondTimer) {
        esp_timer_stop(secondTimer);
        esp_timer_start_periodic(secondTimer, 1000000ULL);
    }
    senderSecondTick = false;
}

//=============================================================================
// Setup
//=============================================================================

void setup() {
    // ALLERERSTE Aktion: Power-Latch halten! (FR-014, R-13)
    pinMode(Pins::LATCH, OUTPUT);
    digitalWrite(Pins::LATCH, HIGH);

    // Takt runter, bevor irgendetwas anderes läuft — spart ~15-20 mA über die
    // gesamte Laufzeit. Muss vor Serial.begin() passieren, damit die Baudrate
    // zum Takt passt. Der Wartungsmodus dreht später wieder auf (setupOta()).
    setCpuFrequencyMhz(System::CPU_FREQ_NORMAL_MHZ);

    // Serial für Debugging (natives USB-CDC)
    #if DEBUG_ENABLED
    Serial.begin(System::SERIAL_BAUD);
    // NICHT auf Serial warten — das Gerät muss auch ohne USB booten
    DEBUG_PRINTLN("");
    DEBUG_PRINTLN("======================================");
    DEBUG_PRINTF("  %s (Sender)\n", System::VERSION);
    DEBUG_PRINTLN("======================================");
    DEBUG_PRINTF("Build: %s %s\n", __DATE__, __TIME__);
    #endif

    // Button Manager (erkennt den noch gedrückten Einschalt-Taster →
    // Boot-Lockout bis zum ersten Loslassen)
    buttons.begin();

    // Power-Management (Akku-ADC, Lader-Status, USB-Erkennung)
    power.begin();

    // e-Paper: LOAD-Rail an, dann init (FR-018)
    epaper.begin();

    // Tastenabfrage während des Refreshs am Leben halten. Ohne das steht sie
    // bei jedem Fenster-Update 300-400 ms still — im Schießbetrieb also rund
    // ein Drittel der Zeit — und der Dreifachklick der Alarm-Geste (max. 400 ms
    // Klickabstand) verliert dort einzelne Klicks (research.md R-1).
    epaper.setBusyCallback(&pollButtonsWhileBusy);

    // ----- Boot-Modus-Entscheidung: genau einmal, hier -----
    bootOtaMode = readOtaModeButtons();

    if (bootOtaMode) {
        DEBUG_PRINTLN("Boot-Modus: OTA-WARTUNG (CONFIG+OK gehalten)");
        setupOta();
    } else {
        DEBUG_PRINTLN("Boot-Modus: Normalbetrieb");
        setupNormal();
    }

    DEBUG_PRINTLN("Setup abgeschlossen");
}
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

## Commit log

2025-12-06 Remove unused Empfänger schematic files and update gitignore
    Removed outdated KiCad files from Schaltung/Empfänger/ directory.
    Added .specify/ cache and session directories to gitignore.
    [Empfänger.kicad_pcb, Empfänger.kicad_sch]
2025-12-14 Fix: NRF24L01 Funkverbindung - Konfiguration korrigiert
    Mehrere kritische Probleme behoben:
    1. Payload-Größe synchronisiert
    - Sender: 4 Bytes → 2 Bytes (passend zu RadioPacket)
    - Empfänger: bereits korrekt 2 Bytes
    2. Pin-Initialisierung korrigiert
    - Entfernt manuelle CE/CSN Pin-Init (RF24.begin() macht das)
    - Verhindert Konflikte mit RF24-Bibliothek
    3. SPI-Bus-Initialisierung optimiert (Sender)
    - SPI.begin() einmal am Anfang von setup()
    - Radio VOR Display initialisieren (verhindert SPI-Konflikte)
    - Doppelte SPI.begin() Aufrufe entfernt
    4. RF24-Enums direkt verwendet
    - Entfernt custom DataRate/PowerLevel Enums
    - Verwendet rf24_datarate_e und rf24_pa_dbm_e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
    [Bogenampel.kicad_pcb, Bogenampel.kicad_sch]
2025-12-14 Update Pfeile Holen menu UI with new button layout and 4-sequence display
    - Redesigned button layout:
    * "Nächste Passe" button now full width at top with larger text (size 2)
    * "Reihenfolge" and "Neustart" buttons side-by-side (half width each) for 3-4 shooters
    * "Reihenfolge" button only shown when 3-4 shooters configured
    - Implemented 4-sequence shooter group display showing full rotation cycle
    * Format: "Aktiv: A/B | Naechste: -> C/D } { C/D -> A/B }"
    * Arrows (->) indicate group changes within same pass
    * Curly braces (} {) indicate pass changes
    * Shows current state plus next 3 states in the cycle
    - Updated button navigation logic to handle dynamic button count
    🤖 Gene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
2025-12-14 UI verbessert: Größere Schrift und bessere Lesbarkeit
    - Alle Button-Texte jetzt Schriftgröße 2
    - "Reihenfolge" → "Abfolge" (passt besser mit größerer Schrift)
    - Schützengruppen-Info aufgeteilt in 2 Zeilen mit Größe 2:
    * Zeile 1: "Aktiv: A/B"
    * Zeile 2: "Dann: ->C/D }{C/D->A/B}"
    - "Naechste" → "Dann:" für kürzere Darstellung
    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
2025-12-16 UI-Verbesserungen und Funk-Debugging
    Schießbetrieb UI:
    - Überschrift in Orange mit Trennlinie
    - Timer horizontal zentriert und nur 1x pro Sekunde aktualisiert
    - Layout-Abstände optimiert (weniger gestaucht)
    - Button "Passe beenden" mit grauem Hintergrund
    - Bei 3-4 Schützen: Timer tiefer positioniert
    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
    [Bogenampel.kicad_pcb, Bogenampel.kicad_sch]
2025-12-17 Vorbereitungsphase synchron auf beiden Geräten implementiert
    Änderungen:
    - DEBUG_SHORT_TIMES auf beiden Geräten aktiviert (1)
    - DEBUG_SHORT_TIMES im Sender an Anfang der Config.h verschoben
    - Lokale Vorbereitungsphase auf beiden Geräten (5s/10s)
    - Sender sendet CMD_START nur einmal beim Eintritt in Schießbetrieb
    - Empfänger führt automatische 10s Vorbereitungsphase durch
    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
2025-12-21 7-Segment LED-Display und Gruppen-Anzeige implementiert
    Empfänger:
    - 158 LEDs konfiguriert: 16 Gruppe A/B, 16 Gruppe C/D, 126 für 3×7-Segment Displays
    - Timer-Countdown auf 7-Segment-Display (Grün > Orange > Rot)
    - Vorbereitungsphase (10s) mit Countdown in ROT
    - Orange statt Gelb für letzte 30 Sekunden (besserer Kontrast zu Grün)
    - Gruppen-Farbe synchron mit Display-Farbe
    - Gruppen-Umschaltung korrigiert (inaktive Gruppe wird ausgeschaltet)
    - Buzzer-Funktionen verbessert (explizites Pin-Reset)
    - segmentMap korrigiert für korrekte 7-Segment-Darstellung
    - Display-Reihenfolge angepasst (1er, 10er, 100er von links nach rechts)
    Sender:
    - Gruppen-Kommandos jetzt zur richtigen Zeit gesendet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
    [Bogenampel.kicad_pcb, Bogenampel.kicad_sch, Bogenampel.step]
2025-12-21 Halbe Passe-Funktionalität und Code-Refactoring implementiert
    - Neue Kommandos: GROUP_NONE, GROUP_FINISH_AB, GROUP_FINISH_CD
    - DisplayManager und BuzzerManager für modularen Code
    - Timer1-Interrupts für präzise Sekunden-Ticks (unabhängig von Buzzer-Delays)
    - SchiessBetriebMenu für Sender hinzugefügt
    - Test-Verzeichnisse für Empfänger und Sender erstellt
    - FastLED-Bibliothek integriert
    [BuzzerManager.cpp, BuzzerManager.h, Config.h]
2025-12-22 DEBUG_SHORT_TIMES aktiviert mit optimierten Zeiten
    Software-Änderungen:
    - DEBUG_SHORT_TIMES auf 1 gesetzt (aktiviert)
    - Vorbereitungsphase: 5 Sekunden (unverändert)
    - Schießzeit: 15 Sekunden für beide Modi (statt 6s/12s)
    - Gelbe Ampel: Aktivierung in den letzten 5 Sekunden (statt 30s)
    - Empfänger Serial Baud: 115200 statt 57600
    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
    [Bogenampel.kicad_pcb, Bogenampel.kicad_sch]
2025-12-22 Interrupt-basierte Timer-Synchronisation für perfekte Sender-Empfänger-Sync
    Sender-Änderungen:
    - Timer1-basierte 1-Sekunden-Interrupts (statt millis())
    - ISR(TIMER1_COMPA_vect) für exakte Zeitbasis (identisch zum Empfänger)
    - setupTimer1() und resetSenderTimer() für synchronen Start
    - StateMachine auf Interrupt-basierte Logik umgestellt
    - Bug-Fix: handleShootingPhaseEnd() prüft currentPosition statt currentGroup
    → CD→AB Gruppenwechsel funktioniert jetzt korrekt
    Empfänger-Änderungen:
    - CMD_STOP sendet jetzt buzzer.beep(3) für akustisches Feedback
    - Kleinere Code-Optimierungen in updateTimer() und updatePreparation()
    Technische Details:
    - Timer1 statt Timer2 verwendet (Tone-L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
    [Config.h]
2025-12-22 Alarm-System mit Pfeiltasten-Trigger und UI-Verbesserungen implementiert
    Features:
    - Alarm wird durch Halten einer Pfeiltaste (>2s) ausgelöst
    - Alarm-Screen mit 8x Blink-Sequenz (250ms Intervall)
    - Timer und Phasen werden bei Alarm sofort gestoppt
    - Keine vorzeitige Alarm-Beendigung möglich
    - Alarm-Hinweis im Config Dialog
    - KY-012 aktiver Buzzer unterstützt (HIGH/LOW statt tone())
    - Schießbetrieb-Text geändert zu "Alle ins Gold"
    - Gruppen-Display optimiert (große, zentrierte Anzeige)
    - 7-Segment-Display und Gruppen-LEDs blinken rot bei Alarm
    [ButtonManager.cpp, BuzzerManager.cpp, Config.h]
2025-12-25 Dokumentation aktualisiert und Schaltung Version 2.2
    - HARDWARE.md: Pin-Belegungen korrigiert (NRF D9/D8, Buttons D5/D6/D7, Voltage A5, Buzzer D4)
    - README.md: Features, Pin-Tabellen und Kommunikation aktualisiert (158 LEDs, 11 Kommandos)
    - Sender/README.md: Alle Features als implementiert markiert, State Machine erweitert
    - Sender/SETUP.md: Test-Sektion aktualisiert
    - CLAUDE.md: Komplett überarbeitet mit aktuellem Projekt-Stand
    - Schaltung: Version 2.2 - bereit für Fertigung
    - Test-Dateien entfernt (TestEmpfaenger, TestSender)
    [Bogenampel.kicad_pcb, Bogenampel.step, Bogenampel_embedded.kicad_sch]
2026-01-17 UI für Portrait-Display (240x320) umgebaut
    - Display-Rotation von 3 auf 0 geändert (Portrait statt Landscape)
    - Alle Screens für 240x320 Auflösung angepasst:
    - SplashScreen: Logo-Rahmen schmaler, STATUS_Y angepasst
    - ConfigMenu: Buttons vertikal gestapelt, Positionen optimiert
    - SchiessBetriebMenu: Gruppensequenz auf 2 Zeilen
    - PfeileHolenMenu: Alle Buttons übereinander, Header linksbündig
    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
2026-01-17 Bug: A6 & A7 durch A2 & A3 ersetzt für Digital Output
    [Bogenampel.kicad_pcb, Bogenampel.kicad_sch]
2026-02-02 Fix: CMD_STOP stoppt Timer + Poti-Helligkeitssteuerung
    - CMD_STOP setzt jetzt timerRunning=false (Bug: Timer lief weiter)
    - Poti auf A7 steuert LED-Helligkeit (25%-100%)
    - Helligkeit live während Betrieb anpassbar
    [Config.h]
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2026-02-08 LiPo-Batterieanzeige: 18650 mit 3.0V-4.2V Bereich
    - Pin von A5 auf A4 geändert (LiPo direkt, kein Spannungsteiler)
    - Nicht-lineare LiPo-Entladekurve für akkurate Prozentanzeige
    - USB-Erkennung wenn keine Batterie angeschlossen (<2.5V)
2026-02-08 ConfigMenu: Ändern-Button entfernt, Stift-Navigation
    - "Ändern" Button entfernt, nur noch "Start" Button
    - Pfeiltaste (Stift) bei Start geht zurück zur Konfiguration
    - Hilfetexte: "L/R" durch "Stift" ersetzt
2026-04-04 Fix: Empfänger autonom, Entprellung verbessert
    - Empfänger piept 3x und wechselt Gruppe eigenständig wenn Timer abläuft,
    ohne auf CMD_STOP vom Sender angewiesen zu sein
    - CMD_STOP nur noch bei manuellem Abbruch (Sender-Akku leer = kein Problem mehr)
    - Debounce-Zeit 50ms → 80ms für robustere Tastererkennung
    - 400ms Eingabesperre nach Passende verhindert ungewollte Aktionen durch
    nachprallende Taster (Ursache für durcheinandergekommene Gruppen)
    [Config.h]
2026-05-29 V3 mit XIAO-ESP32C3 Arbeitsstand
    [BogenampelV3.kicad_pcb, BogenampelV3.kicad_sch, Zusatzplatine-Empfänger.kicad_sch]
2026-05-29 Universalfernbedienung V3
    [BogenampelV3.kicad_pcb, BogenampelV3.kicad_sch]
2026-06-09 Update to V3 with ESP-32
    [BogenampelV3.kicad_pcb, BogenampelV3.kicad_sch]
2026-06-12 V3-Firmware: OTA, zentrales PlatformIO, .cpp-Umbenennung, Lüfter-Fix
    - EmpfaengerV3 + SenderV3: .ino → .cpp (kein Konverter-Schritt mehr)
    - OTA via ArduinoOTA: SoftAP-Fallback + STA-Modus (DHCP, wifi_credentials.h)
    - Zentrales platformio.ini im Repo-Root (extends, build_src_filter)
    - FanManager: Gate-Duty invertiert (Q2 Open-Drain, Poti-Richtung korrigiert)
    - Lochrasterskizze: POTI_GND-Trennschnitt und Lüfter-Netz-Kurzschluss behoben
    - KiCad: Gerber-Export, STEP-Modelle, aktualisierter Empfänger-Schaltplan
    - wifi_credentials.h.example als Vorlage (echte Datei gitignored)
    [BogenampelV3-B_Cu.gbr, BogenampelV3-B_Mask.gbr, BogenampelV3-B_Paste.gbr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]
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2026-06-13 005: FR-012 auf physischen Taster-Gate umgestellt (kein OTA-Passwort)
    OTA-Zugang ist durch den Taster-beim-Boot geschützt, nicht durch ein
    Netzwerk-Passwort: Die ArduinoOTA-PBKDF2-Auth (arduino-esp32 3.3.7) ist mit der
    espota.py von PlatformIO inkompatibel; wer das Gerät mit gehaltenem Taster
    power-cyceln kann, hat ohnehin physischen Zugriff. OTA-Flash ist bestätigt
    funktionsfähig — der zuvor vermutete WLAN-Paketverlust war eine Firewall am
    Flash-Pfad (behoben), kein Firmware-Fehler.
    - spec.md: FR-003 (ohne "authenticated"), FR-012 (Taster-Gate-Sicherheitsmodell)
    - contracts/boot-mode-contract.md: C3 ohne Passwort/Auth
    - quickstart.md: HIL #9 auf Taster-Gate statt "wrong password"
    - r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
2026-06-13 Buzzer-Lautstärke: R8 (Entlade-Pfad) + Treiberfrequenz auf Resonanz 3250 Hz
    Ursache des kaum hörbaren Buzzers: der Piezo (J6) am Low-Side-BC337 hatte keinen
    Lade-/Entlade-Pfad. Als reine Kapazität ohne Rückweg am Collector konnte er nicht
    schwingen — nur ein leises Brummen, unabhängig von Frequenz und Duty.
    - HW: R8 (~1k) parallel zum Piezo / Collector→+12V ergänzt; gibt den 0↔12V-Hub
    (Zusatzplatine-Empfänger.kicad_sch, Empfaenger-Lochraster.diy, PNG-Exporte)
    - FW: BUZZER_FREQUENCY_HZ 2700 -> 3250 (Resonanz CPS-4013-110PM) — am lautesten
    genau bei Resonanz (Config.h, BuzzerManager.h)
    [Zusatzplatine-Empfänger.kicad_sch]
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2026-06-13 Lüfter-PWM zurück auf 25 kHz (4-Draht-Spec)
    Die 1 kHz waren nur ein Diagnose-Versuch gegen ein vermeintliches Frequenz-
    problem; die fehlende Drehzahländerung lag an einem falsch beschalteten
    MOSFET (Hardware), nicht an der PWM-Frequenz. Daher zurück auf die Spec.
    [Config.h]
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2026-06-13 HW: Pull-up auf der Lüfter-PWM-Leitung ergänzt
    4-Draht-Lüfter-PWM (Open-Drain über MOSFET an D6) braucht einen Pull-up auf
    Logikebene (~10k nach +3,3/5 V, NICHT 12 V), damit die Steuerleitung nach HIGH
    kommt — ohne den blieb sie auf 0 V und die Drehzahl ließ sich nicht regeln.
    (Zusatzplatine-Empfänger.kicad_sch, Empfaenger-Lochraster.diy)
    [Zusatzplatine-Empfänger.kicad_sch]
2026-06-14 Empfänger: Lautstärke-Vorhörton, Start-Piepen-Fix, Aus-Zone 1 %
    - Kein Dauerpiepen mehr beim Einschalten: das Lautstärke-Feedback feuert
    erst nach dem ersten Poti-Messzyklus (sonst lief der Ton durch den
    blockierenden Regenbogen-Effekt durch, da dort kein buzzer.update() läuft).
    - Anfangshelligkeit invertiert (konsistent mit updatePotis) → Regenbogen-
    Effekt läuft wieder mit korrekter Helligkeit statt verkehrt/zu dunkel.
    - Lautstärkeregler erzeugt jetzt einen kontinuierlichen Vorhörton, der live
    der eingestellten Lautstärke folgt und max. 1 s nach der letzten Bewegung
    verstummt (BuzzerManager::startPreview, Timing::VOLUME_PREVIEW_HOLD_MS).
    - Buzzer nur noch im letzten 1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
    [BuzzerManager.cpp, BuzzerManager.h, Config.h]
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2026-08-01 Sender: OTA-Wartungsmodus, ESP-NOW-Kanalfix, Tastenrollen getauscht
    Wartungsmodus (beide Taster beim Einschalten halten): WiFi-Station +
    ArduinoOTA, Verbindungsstatus und eigene IP auf dem e-Paper. Im Normalbetrieb
    laeuft dafuer gar kein WiFi mehr. Der bisher dauerhaft parallel laufende
    SoftAP zog den Single-Radio-Kanal weg und legte ESP-NOW still — Symptom war
    der Log-Spam "Peer channel is not equal to the home channel, send fail!",
    bei dem kein einziger Frame rausging.
    ESP-NOW zusaetzlich abgesichert: Peers werden mit channel 0 registriert
    (= aktueller Home-Channel, keine Mismatch-Pruefung mehr), ein Kanal-Waechter
    holt einen abgewanderten Kanal zurueck, und die Discovery faellt nach 10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
    [ButtonManager.cpp, Config.h, EpaperDisplay.cpp]
2026-08-01 Schaltplaene neu strukturiert: Sender/Empfaenger getrennt, V2 entfernt
    Schaltung_v3/ war ein Sammelordner: die Sender-Platine lag unter
    BogenampelV3/, der Empfaenger-Schaltplan als "Zusatzplatine" mittendrin, und
    lose Empfaenger-Dateien (Lochraster, Regler-Aufkleber) daneben. Aufgeteilt in
    Schaltung-Sender/ und Schaltung-Empfaenger/, jeweils flach.
    Schaltung/ (V2, Arduino Nano) entfernt — die Generation ist eingefroren
    (FR-025) und bleibt ueber die Git-Historie auffindbar.
    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
    [Bogenampel.kicad_pcb, Bogenampel.kicad_sch, Bogenampel.step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]
2026-08-01 Doku: Pfade auf die neue Schaltplan-Struktur nachgezogen
    Verweise auf Schaltung_v3/BogenampelV3/ zeigten nach der Aufteilung ins Leere
    und gehen jetzt auf Schaltung-Sender/ bzw. Schaltung-Empfaenger/. Betrifft
    CLAUDE.md, README.md, HARDWARE.md, die Constitution (Prinzip III und V nennen
    den Schaltplan als autoritative Quelle) und den Pin-Contract.
    Die entfernten V2-KiCad-Dateien sind ueberall als "nur noch in der Git-Historie"
    gekennzeichnet, statt auf nicht mehr existierende Pfade zu verweisen. Ebenfalls
    korrigiert: TestSender/ und TestEmpfaenger/ standen noch in der Projektstruktur,
    existieren aber laengst nicht mehr.
    README: Die Bedienzeile beschrieb noch die alte Tastenbelegung
    ("BTN1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
    [Config.h]
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2026-08-01 Korrektur: Schnellladen per GPIO18 ist nicht moeglich
    Drei Stellen behaupteten, GPIO18 als OUTPUT HIGH schalte den Ladestrom von
    80-100 mA auf 400-500 mA: PowerManager.h, der Pin-Contract und das README.
    Das ist falsch — es wuerde den Lader abschalten.
    Die PROG2-Schwellen des MCP73837 sind relativ zur Versorgung definiert, und
    laut Datenblatt ist VDD = VUSB, wenn wie hier aus dem USB-Port gespeist wird
    (VAC ist unbeschaltet). Bei VDD = 5 V liegt V_IH damit bei 4,0 V, waehrend ein
    ESP32-GPIO nur 3,3 V liefert. Der Ausgang uebersteuert den 10k-Pulldown zwar
    problemlos, erreicht aber nur einen Pegel mitten im Shutdown-Fenster V_SD
    (1,0 .. 4,0 V) — derselbe Mechanismus, der den Lader schon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
    [PowerManager.cpp]
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2026-08-02 Empfaenger: PCB fertig geroutet
    Layout des Empfaenger-Boards abgeschlossen.
    PCB
    - Leiterbahnen 100 -> 323 Segmente, Vias 4 -> 10: das Board ist jetzt
    durchgeroutet statt teilverdrahtet
    - Zweite Kupferflaeche hinzugekommen (1 -> 2 Zonen)
    - Platinenumriss gezeichnet (4 gr_line)
    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
    [Empfaenger.kicad_pcb, Empfaenger.kicad_sch]
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2026-08-03 Finale überarbeitung (Druck, Bohrlöcher, TP) vor Fertigung
    [Empfaenger.kicad_pcb, Empfaenger.kicad_sch]
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2026-08-06 Robustheit: Funkabbruch, Alarm-Zustellung und sichere Anzeigezustaende
    Systematischer Durchgang der Fehlerszenarien am Empfaenger (Funkabbruch,
    verlorene Kommandos, Neustart mitten in der Passe) und der Frage, ob Alarm-
    und Abbruchsignale zuverlaessig ankommen. Elf Befunde, alle behoben.
    Empfaenger:
    - Nach einem Alarm fehlten die Gruppenbalken: das FastLED.clear() im Blinktakt
    loescht sie, und es laeuft kein Timer mehr, der sie nachzieht. Neue
    showStoppedState()/showCurrentGroup() ersetzen das 7-fach kopierte Muster.
    - Nach Brown-out/Watchdog-Reset blieb die Tafel dunkel, bis das naechste
    Kommando kam (der Sender merkt den Reboot nicht). Jetzt rot "000" als
    Grundzustand — dunkel i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
    [Config.h, Empfaenger.cpp]
2026-08-06 Empfaenger: Countdown mit dem Sender synchronisieren
    Der Sender lief dem Empfaenger dauerhaft eine Sekunde voraus. Zwei Ursachen:
    1. Off-by-one in updatePreparation(): Die Auswertung stand VOR dem Dekrement,
    dadurch wurde der Startwert ("10") zwei Ticks lang gezeigt und die
    Vorbereitungsphase brauchte 11 statt 10 Ticks. Der Sender dekrementiert in
    handleSchiessBetrieb() zuerst — jetzt beide gleich.
    2. Der Sekundentakt des Empfaengers lief frei durch, waehrend der Sender seinen
    direkt nach dem Senden zuruecksetzt (resetSenderTimer()). Der erste Tick fiel
    damit zufaellig irgendwo ins laufende 1-s-Raster, im Mittel eine weitere
    halbe Sekunde Versatz. CMD_START startet den e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
    [Empfaenger.cpp]
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2026-10-01 Empfaenger-Platine: Bemassungen, MOSFET-Typen und BOM-Export
    - PCB: Bemassungen auf User.1 ergaenzt (Bohrabstaende/Platinenmasse)
    - Schaltplan: Q1 IRLML9301 -> AO3401A, Q2 2N7002 -> BSS138
    - BOM-Export Empfaenger.csv hinzugefuegt (Stand vor der MOSFET-Umbenennung)
    - BOM-Spalten (MPN/MFG/Beschreibung) im Projekt konfiguriert
    [Empfaenger.csv, Empfaenger.kicad_pcb, Empfaenger.kicad_sch]
2026-10-01 Empfaenger: Poti-Drehrichtung korrigiert (aufdrehen = mehr)
    Alle drei Regler liefen falsch herum: aufdrehen machte dunkler, leiser und
    den Luefter langsamer. Ursache war nicht die Verdrahtung, sondern die
    Firmware - sie invertierte die Potis an fuenf Stellen einzeln ("Poti verpolt"),
    was noch vom Vorserien-Aufbau stammte. Auf der PD-12V-Platine sind die Regler
    regulaer verdrahtet, also dreht die Software die Richtung falsch.
    Die Orientierung sitzt jetzt an genau einer Stelle: Poti::ASCENDING in
    Config.h, dazu Poti::level(), das den Rohwert in eine Reglerstellung
    uebersetzt (0 = unterer Anschlag). Alle Kennlinien rechnen damit statt mit
    dem Rohwert - eine kuenftige Platinenrevision braucht n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
    [Config.h, Empfaenger.cpp, FanManager.cpp]
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2026-10-01 README: Projektbeschreibung als Kapitel 1, Entwickler-Teil als Kapitel 2
    Kapitel 1 beschreibt das Projekt fuer Leser, die es nicht bauen wollen:
    worum es geht, die beiden Geraete mit Fotos der bestueckten Platinen und des
    Einbaus, Bedienung, Ablauf einer Passe, dazu Schaltplaene und Platinenlayouts
    aus doc/. Kapitel 2 enthaelt unveraendert den Entwickler-Teil (Bauen, Flashen,
    OTA, Stromverbrauch, Projektstruktur, offene Punkte, Historie).
    doc/ ist mit aufgenommen (4,1 MB: 4 Fotos, 2 Schaltplaene, 2 Layouts). Die
    Exporte in doc/ sind aktueller als die schaltplan-*.png im Repo-Root - der
    Empfaenger-Plan dort ist Rev. 3 und zeigt bereits AO3401A/BSS138.
    Dabei zwei veraltete Angaben korrigiert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
2026-10-01 Doku gegen den aktuellen Stand geprueft und korrigiert
    Durchgang durch README.md und HARDWARE.md, Angaben gegen Schaltplaene,
    Config.h und ButtonManager geprueft. Gefunden und korrigiert:
    HARDWARE.md (Sender):
    - Tasterrollen waren VERTAUSCHT. Maassgeblich ist
    ButtonManager::readRawState(): GPIO15 (SW2, aktiv HIGH, haelt den Latch) ist
    CONFIG/Weiter, GPIO9 (SW1, aktiv LOW) ist OK. Die Doku schrieb GPIO15 = OK
    und GPIO9 = Weiter - also genau andersherum als Gehaeuse und Firmware.
    - "integrierte Antenne U.FL" war in sich widerspruechlich: das -1U-Modul hat
    KEINE Leiterplattenantenne, sondern einen U.FL-Anschluss fuer eine externe
    (verbaut: SMA-Pigtail).
    - Akku praezisiert: einzelne L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
2026-10-01 MOSFET-Typen in Firmware-Kommentaren und Pin-Contract nachgezogen
    Reine Kommentar- und Doku-Aenderung, kein Code angefasst - daher nicht neu
    geflasht.
    Empfaenger/Config.h, FanManager.h: Q1 IRLML9301 -> AO3401A,
    Q2 2N7002 -> BSS138, passend zum Value-Feld im Schaltplan.
    Dasselbe in specs/.../contracts/hardware-pins.md.
    Dabei zwei echte Fehler in FanManager.h gefunden und korrigiert: Dort stand
    "R5 ist Gate-Pull-up an 3V3 -> Luefter laeuft hardware-default voll". Beides
    falsch. R5 ist laut Schaltplan der 1k-Vorwiderstand am Luefter-Poti (J2); der
    Gate-Pull-up ist R11. Und die Richtung stimmt auch nicht: Q2 leitet dadurch
    beim Boot, zieht die PWM-Leitung LOW, der Luefter laeuft auf MINIMAL-,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
    [Config.h, FanManager.cpp]
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2026-11-03 Bluetooth-Bruecke (Steckbrett) und FT_SIGNAL im Empfaenger
    Neues Geraet Bruecke/ (ESP32-DevKitC V4, LCD 16x2, KY-040): hoert per
    ESP-NOW auf die Signaltoene des Empfaengers und spielt sie als A2DP-Source
    ueber eine Bluetooth-Box ab. Box-Suche und Lautstaerke am Drehgeber.
    Empfaenger sendet jeden Signalton zusaetzlich als FT_SIGNAL-Broadcast
    (FrameType 0x06, 3 Kopien mit gleicher seq, Contract-Regel 8); alle
    buzzer.beep() laufen ueber signalBeep(). Commands.h in allen drei
    Ordnern byte-identisch.
    Plattform auf pioarduino 55.03.312-1 (arduino-esp32 3.3.12) gepinnt,
    das unversionierte espressif32 baute nicht mehr.
    Am Steckbrett bestaetigt: Flashen, LCD, Pairing, Testton, Lautstaerke.
    Offen: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
